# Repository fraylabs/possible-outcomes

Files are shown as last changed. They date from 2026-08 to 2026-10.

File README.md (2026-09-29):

# Fray Labs Outcomes

Public, reusable AI Outcomes and the recipes behind them, published by Fray Labs for [Possible](https://possible.sh).

Each folder contains:

- `outcome.md` — what was made and the original request;
- `prompt.md` — the recorded reusable execution prompt; and
- `outcome.json` — provenance, models, Products, Skills, requirements, file metadata, and an optional recipe.

A recipe collects the recorded agent, pinned skills, references, tools and ordered steps that help another agent reproduce or adapt the result. Unknown details are omitted. Fray-authored backfills explicitly label steps reconstructed from published prompts and artifacts; they are not transcripts of historical agent turns. Existing model provenance, prompts, result limitations and creator credits remain intact. Curated third-party demos retain their disclosed prompts without an invented workflow.

The root [`outcomes.json`](./outcomes.json) is the machine-readable publisher index. Possible reads this repository directly; the canonical source remains here.

## Use with Possible

Use CLI 0.5.0 or newer for manifests containing the optional `recipe` field. The older primary Product/Skill parsing issue in CLI 0.3.0 was fixed in 0.3.1; recipe support began in 0.4.0; explicit reconstructed-origin labels require 0.5.0.

```shell
npx https://github.com/fraylabs/possible/releases/download/v0.5.0/fraylabs-possible-0.5.0.tgz add fraylabs/possible-outcomes
npx https://github.com/fraylabs/possible/releases/download/v0.5.0/fraylabs-possible-0.5.0.tgz use fraylabs/possible-outcomes@digital-photo-frame
```

The `use` command provides the reusable instructions for an agent. Review the recipe, original prompt and stated limits before running it; access to referenced tools and services is still required.

## Opus 5.5 demos

[See ten creator demos and copy their prompts](OPUS-DEMOS.md): neon cities, mini golf, a cursor-following pet, a rocket launch, an interactive robot hand, fluid simulation, a Rube Goldberg machine, a sunset pirate ship, motion design and an explorable pagoda. Each links the original creator and records creator-reported model provenance.

## License

Fray-authored code and text are available under the MIT License. Curated creator prompts and demo media retain their original ownership and are excluded from that grant; see linked sources and each media/NOTICE.md. Referenced third-party Products and Skills retain their respective ownership and licenses.

CLI 0.5.0 is currently distributed through the verified GitHub release package used above. The npm registry remains on 0.3.1; use the release package for these optional recipes.

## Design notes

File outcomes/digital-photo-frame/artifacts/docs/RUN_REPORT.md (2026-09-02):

# Cleanroom and independent review report

## Outcome

The exact prompt was executed once in an empty workspace by an isolated Codex agent using Burr skill commit `3a1b8ebf17e178b28c6d65f67ad04fc97f009a55`, CAD skill commit `fc4f7069fb31c131a55f1ecd334b505f031f486b`, and KiStack commit `c5a25d1d0af7ae811666cab41d7952f41e310575`.

Prompt SHA-256: `394d94afe5622c2cc86f75955a4a430ee1d9883ff4be4308cc8aa4a50aa25dcd`.

No sibling experiment was visible and no parent-agent steering occurred after execution began. No purchase, fabrication, hardware power-up, publication, or external contact occurred during the run.

## Reproduced digital evidence

- Mechanical CAD: 9/9 final STEP targets passed topology, closure, and positive-volume validation.
- Product face: 216 × 138 mm.
- Nominal enclosure depth excluding stand: 29 mm.
- Burr motion: 61 rigid frames, eight instances, 1200 ms.
- KiCad ERC: exit 0, zero violations.
- KiCad DRC/parity: exit 5. The saved run recorded 742 DRC violations, zero unconnected items, and 295 schematic-parity issues.

The independent review reran ERC and reproduced exit 0. Three exact DRC reruns—including the cleanroom receipt—reproduced exit 5 and 295 parity issues; the DRC count varied between 740, 742, and 784 after zone refill. The stable conclusion is failure, not an exact deterministic violation count.

## Integration boundary

Because DRC/parity failed, the run correctly withheld populated PCB STEP, PCB renders, Gerbers, and drill files. The assembly retains an explicitly named `unverified_populated_component_envelope_4p5mm` rather than presenting a fabricated board model as authoritative.

Burr's integrated checks are also not passes:

- Deployed: `fail`, six findings across 28 checked pairs.
- Folded: `fail`, seven findings across 28 checked pairs.
- Exploded: `fail`, three findings across 28 checked pairs.
- All three carry an `open_component_mesh` incomplete reason.

## Trust boundary

Trusted: the exact prompt and provenance, editable CAD and KiCad sources, ERC-clean schematic, generated BOM/PDF, nine valid CAD outputs, relative Burr project, named fold motion, and preserved failed evidence.

Not trusted: PCB routing or fabrication readiness, populated-board integration, connector reach, power integrity, antenna performance, thermal or electrical safety, enclosure fit, stand strength, durability, or production readiness.

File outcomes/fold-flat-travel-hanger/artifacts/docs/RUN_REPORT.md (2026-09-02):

# Cleanroom and independent review report

## Outcome

The exact prompt was executed once in an empty workspace by an isolated Codex agent using Burr skill commit `3a1b8ebf17e178b28c6d65f67ad04fc97f009a55` and CAD skill commit `fc4f7069fb31c131a55f1ecd334b505f031f486b`.

Prompt SHA-256: `3c9f24162b60f47c980407762831950fe5c1894924433af9f205b289d80082fc`.

No earlier hanger geometry was provided, and no parent-agent steering occurred after execution began. No purchase, fabrication, physical use, publication, or external contact occurred during the run.

## Reproduced digital evidence

- CAD provider validation: 16/16 targets passed with zero failures.
- Deployed shoulder width: 442 mm.
- Folded envelope: 222.884518 × 88 × 30 mm.
- Hook pocket: 42 mm for a stated maximum 38 mm rod.
- Pin/bore clearance: 0.6 mm diametral.
- Positive-lock engagement: 6 mm per arm, with a nominal 36 mm² contact face per side.
- Release travel: 7.5 mm with 1 mm modeled blocking-face clearance.
- Exact exported STEP validation: all 55 component pairs passed in deployed, 25%, 50%, 75%, and folded poses.
- Burr motion: 61 rigid frames, 11 instances, 1600 ms.

The independent review reran the geometry validator from a separate temporary copy and reproduced `overall_pass: true` and all five zero-positive-volume-intersection results.

## Burr result

Burr's check is not a pass:

- Deployed: `fail`, four findings, 11 components, 55 checked pairs.
- Folded: `fail`, three findings, 11 components, 55 checked pairs.
- Both include `open_component_mesh` for seven tessellated components.

The exact BREP result and Burr's tessellated result use different representations. Both are retained; the BREP result does not override Burr's failed/incomplete outcome.

## Trust boundary

Trusted: editable source, exported CAD, stated dimensions, exact five-pose geometry result, named Burr motion, and the preserved evidence files.

Not trusted: physical load rating, stiffness, fatigue, creep, spring selection, retention force, dimensional accuracy after printing, user safety, or production readiness.

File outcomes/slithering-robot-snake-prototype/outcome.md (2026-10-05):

# Slithering Robot Snake Prototype

A ten-link robot snake, about 0.95 m long, with nine yaw joints: a CAD assembly, robot description files, and a MuJoCo simulation where it slithers with lateral undulation, notices an obstacle with a range sensor, detours around it without touching it, and rejoins its route. Twelve tests check the geometry, joints, gait and clearance.

## How it was made

An AI agent made this. Codex built it in one recorded session, starting from the `$possible` skill: it asked what to build, how it should behave, where, and what result was wanted, then prepared a build pack. The answers in this recipe came from a scripted test run, not typed live. The agent used the text-to-cad and robotics skills listed below, MuJoCo for simulation and pytest for checks. Possible captured the session with `possible capture`; tool outputs and file contents are left out.

## What to know

This is a digital prototype. Propulsion in the simulation uses a surrogate, so real-world slithering, servo choice, friction, strength and manufacturability are unproven. The video and renders were regenerated from the session's own files after the originals were lost; link count, joints, tests and simulated distances match the session's report.

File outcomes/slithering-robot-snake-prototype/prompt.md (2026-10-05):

$possible

I want to make a robot snake.

I want it to slither convincingly and navigate around obstacles on its own.

A smooth indoor floor.

Continue from my previous answer.

I am starting from scratch. I only have the idea.

A convincing digital prototype I can inspect and simulate now, with a clear path toward fabricating it later.

Yes, proceed with this pack.

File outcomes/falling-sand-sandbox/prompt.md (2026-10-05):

Build a falling-sand sandbox game as a single self-contained index.html: no libraries, no build step, it should just open in a browser. Elements: sand, water, stone, wood, plant, fire, smoke, and an eraser. Sand piles up and slides off slopes, water flows sideways and levels out, fire burns wood and plants and gives off smoke that rises and fades, and plants slowly grow into adjacent water. Paint with mouse or touch, with an element palette along the bottom and a brush-size slider. Simulate on a fixed grid of about 240x160 cells, render it to a canvas through ImageData, and scale it up with crisp pixels. Keep it smooth at 60fps. Give every element a little per-cell colour variation so it looks textured. Add Pause, Clear, and a Seed button that drops a small demo scene.

Works nicely. Two changes: add lava, which flows slowly, sets wood and plants on fire, turns water it touches into steam (a new gas that rises and condenses back into water near the top) and cools into stone where it meets water. And alternate the horizontal scan direction every frame so sand piles and water don't drift to one side.

Now make the Seed scene look good as a screenshot: a stone basin of water with plants growing in it, a wooden tree on a stone ledge, a stream of sand pouring from the top, and lava dripping from one corner onto the ledge so the tree slowly catches fire. Load that scene automatically on first open.

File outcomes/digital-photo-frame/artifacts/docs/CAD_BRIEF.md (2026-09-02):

# CAD brief

## Goal and scope

Create a landscape tabletop enclosure for a documented seven-inch display, a
compact controller PCB envelope, a reusable-fastener rear cover, and a folding
easel stand. The authoritative editable source is
`models/cad/source/photo_frame_parts.py`; STEP and STL files are generated
artifacts. The detailed PCB is not represented as validated populated geometry
because the KiCad PCB failed DRC and parity, so the assembly intentionally uses
a named conservative PCB envelope and is incomplete.

## Units and coordinates

- Units: millimetres and degrees.
- Origin: centre of the front product face.
- +X: landscape right; +Y: product up; +Z: toward the rear.
- Front exterior plane: Z=0.
- Rear-cover exterior plane: Z=29.
- Stand hinge axis: X direction through Y=35, Z=29.

## Objects and configuration

- `front_bezel`: 216 x 138 mm rounded outer form, 4 mm face, display-frame
  ledge and an unobstructed 158.08 x 89.92 mm window around the active area.
- `rear_chassis`: 216 x 138 mm, rear envelope ending at Z=29, service-cover
  insert bosses, PCB standoffs/ribs, connector openings, hinge blocks and hard
  stops.
- `service_cover`: 208 x 130 x 2 mm; four M3 clearances, controller/power vents,
  three button holes, ambient-sensor hole, and rear status-light opening.
- `folding_stand`: 140 x 105 x 4 mm plate with hinge barrel, folded detents, and
  stop tabs; deployed source angle -18 degrees and folded angle 0 degrees.
- `display_envelope`: EastRising ER-TFTM070-4V3 documented 180 x 100 x 12.8 mm
  maximum envelope plus 154.08 x 85.92 mm active-area plate.
- `pcb_unverified_envelope`: 112 x 70 x 1.6 mm board plus 4.5 mm conservative
  top-side component envelope. This is explicitly not a populated-PCB STEP.
- Product outputs: deployed, folded, and rear-cover-open exploded arrangements
  built from unchanged rigid component functions.

## Constraints and assumptions

- Outer front envelope must remain <=230 x 165 mm. Actual: 216 x 138 mm.
- Enclosure excluding stand must remain approximately 22-30 mm deep. Nominal
  exterior planes span 29 mm; the hinge/stop source is constrained to Z<=29.
- Display ledge locates the module by its outer frame, not active glass.
- Four product PCB standoff centres are (-10,-31), (94,-31), (-10,31),
  (94,31), mapped from KiCad holes (24,24), (128,24), (24,86), (128,86).
- Side openings share the KiCad connector Y coordinates; final X insertion and
  shell engagement require the missing validated populated-PCB STEP.
- No underside PCB components are allowed in the current integration envelope.
- Prototype parts require a build volume of at least 220 x 140 x 30 mm when
  oriented flat; this is an envelope statement, not a printability proof.

## Validation contract

All nine final STEP files were run through CAD `inspect refs --facts --planes
--positioning` and `inspect validate`; every final validation reported
`failureCount: 0`. Every primary STEP has at least one saved snapshot. These
checks prove closed positive-volume source geometry, but do not supersede
Burr's failed tessellated interference check or prove manufactured fit.

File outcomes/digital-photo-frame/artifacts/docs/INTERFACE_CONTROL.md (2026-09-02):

# Shared mechanical/electrical interface control

Status: digital pre-build, incomplete. KiCad and CAD remain independent
authorities. Only exported geometry is copied into `models/assembly/exports`.

## Product and display

| Interface | Controlled value |
|---|---|
| Product axes | Origin at front-face centre; +X right, +Y up, +Z rear |
| Product front envelope | 216 x 138 mm |
| Nominal enclosure rear | Z=29 mm |
| Display MPN/configuration | ER-TFTM070-4V3, 5 V, 8-bit 8080, no touch |
| Display outer/max envelope | 180 x 100 x 12.8 mm |
| Display active area | 154.08 x 85.92 mm, centred on product origin |
| Display front/back | Z=4.5 to 17.3 mm; active-area plate is immediately forward |
| Display mounting holes | Four 3.2 mm holes on 174 x 98 mm centres per selected module documentation; not modelled as product fasteners in this first result |
| Display connection | J2, 2x20 2.54 mm vertical pin header on controller PCB |
| Touch | No-touch configuration; pins 33-38 intentionally unconnected |

The CAD ledge clears the 180 x 100 mm display frame by 0.6 mm total in X and Y
and leaves a 2 mm perimeter allowance around the active area. A replaceable
0.5-1.0 mm compliant gasket is required between the ledge/clamp system and
module frame during physical build; no load may be applied to active glass.

## PCB mapping

| Interface | KiCad coordinates | Product coordinates |
|---|---:|---:|
| Board outline | X=20..132, Y=20..90 | X=-14..98, Y=-35..35 |
| Board centre | (76,55) | (42,0) |
| Mount 1 | (24,24) | (-10,-31) |
| Mount 2 | (128,24) | (94,-31) |
| Mount 3 | (24,86) | (-10,31) |
| Mount 4 | (128,86) | (94,31) |
| Board thickness | 1.6 mm | Z=18.5..20.1 |
| Modelled top envelope | 4.5 mm above board | Z=20.1..24.6 |
| Allowed bottom components | None in this revision | Board-to-display gap is 1.2 mm |

Coordinate transform: `product_x = kicad_x - 34`, `product_y = kicad_y - 55`.
The standoff centres exactly use this mapping in the CAD source. Edge clearance
to the inner cavity is at least 5 mm at the right board edge and 29 mm at the Y
edges. Top-envelope clearance to the service-cover underside at Z=27 is 2.4 mm.
The 1.2 mm board-bottom gap is an explicit local exception valid only because
the current PCB places no bottom-side components; solder protrusion and assembly
tolerance remain a physical bring-up check.

## External and service interfaces

| Item | KiCad anchor | Product opening/axis | Status |
|---|---:|---:|---|
| USB-C J1 | (130,32), rotated 90 deg | right wall, Y=-23 | Y aligned; exact shell protrusion unverified without populated PCB STEP |
| microSD J3 | (126,70), rotated 90 deg | right wall, Y=15 | Y aligned; insertion reach unverified without populated PCB STEP |
| Previous SW1 | (86,74) | (52,19) | coordinate-aligned |
| Next SW2 | (96,74) | (62,19) | coordinate-aligned |
| Menu/wake SW3 | (106,74) | (72,19) | coordinate-aligned |
| Ambient sensor U3 | (63,80) | (29,25) | coordinate-aligned |
| Status LED LED1 | (75,76) | (41,21) | coordinate-aligned after source repair |
| Debug J4 | (39,74) | internal, (5,19) | rear cover removal required; not externally exposed |

Keep at least 12 mm unobstructed outside the USB-C opening for plug overmould
and bend, and at least 20 mm outside the microSD slot for finger/card insertion.
The display module uses a rigid pin-header connection in the selected
configuration; there is no FPC bend region. Maintain a 6 mm insertion corridor
above and around J2 until exact mating hardware is validated.

## Stand and service envelope

- Hinge: X-axis, Y=35, Z=29.
- Deployed pose: -18 degrees from folded/rear plane.
- Folded pose: 0 degrees, stand plate substantially flush; final folded product
  bounds are approximately 216 x 139 x 35.2 mm including the stand barrel.
- Deployed product bounds are approximately 216 x 138 x 67.34 mm.
- Retention: spherical folded detents and two deployed stop tabs are modelled;
  retention force and cycle life are not verified.
- Service cover: four M3 reusable fasteners into heat-set inserts; display, PCB,
  controls and cover are intended to be replaceable after cover removal.

## Known failed interfaces

Burr reports positive-volume overlaps between enclosure pieces, display and PCB
envelope, and open component meshes. The deployed integrated assembly has six
reported interfering pairs, folded has seven, and exploded has three. Therefore
no-fit/no-interference claim is made. USB-C/microSD X alignment, all connector
insertion volumes, and mechanical clearances to real populated components remain
unverified because DRC prevented populated PCB STEP export.

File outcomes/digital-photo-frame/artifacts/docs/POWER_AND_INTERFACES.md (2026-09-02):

# Power budget and electrical interfaces

Status: design estimate only; not measured on hardware.

## Input and rails

J1 is a GCT USB4105-GF-A USB-C receptacle used as a power-only sink. R1 and R2
are independent 5.1 kohm Rd resistors from CC1 and CC2 to ground. USB data and
SBU pins are intentionally unconnected. U4 (USBLC6-2SC6) protects CC1/CC2 and
uses VBUS as its reference. VBUS passes through F1, a Bourns MF-MSMF200-2
2.0 A resettable protector, to +5V; D1 is an SMAJ5.0A shunt TVS on protected
+5V. This architecture requires a certified regulated 5 V USB-C supply that
advertises sufficient Type-C current; it has no USB PD negotiation.

U2 is TPS62132RGTR, fixed 3.3 V, rated 3 A. It uses a 1.0 uH Coilcraft
XAL4020-102MEC, 10 uF input, two 22 uF output capacitors, 10 nF soft-start, and
the datasheet's fixed-output pin treatment. Exact loop layout is not accepted:
the PCB currently fails DRC.

## Pre-build current budget

| Load | Rail | Budgeted current | Basis |
|---|---:|---:|---|
| ER-TFTM070-4V3 module including backlight | 5 V | 0.480 A max | module datasheet maximum |
| ESP32-S3 module/Wi-Fi peaks | 3.3 V | 0.550 A | conservative bring-up allowance; must be measured |
| microSD write/transient | 3.3 V | 0.200 A | design allowance; card-dependent |
| Ambient sensor, LED, pull networks, margin | 3.3 V | 0.020 A | design allowance |
| 3.3 V total | 3.3 V | 0.770 A | below converter rating |
| 3.3 V input equivalent at 90% efficiency | 5 V | 0.565 A | calculated |
| Combined nominal maximum estimate | 5 V | 1.045 A | display plus converter input |
| Recommended adapter | 5 V | >=2.0 A | transient/thermal headroom |

TPS62132 output loading is approximately 26% of its 3 A rating under this
budget. The input protector is not a precision current limiter, and temperature
derating of the PTC must be checked. Display inrush, Wi-Fi bursts, storage
writes, converter temperature, rail droop and EMI require bench measurement.

## Display interface

J2 implements the documented 40-pin ER-TFTM070-4V3 interface in 8-bit 8080,
5 V, no-touch configuration:

- 1 GND; 2 VDD5V; 3 /CS; 4 D/C; 5 /RD; 6 /WR; 7 RESET; 8 TE.
- 9-16 are DB0-DB7 and connect to ESP32-S3 GPIO35-GPIO42.
- 17-32 (DB8-DB23) are intentionally no-connect for the selected 8-bit mode.
- 33-38 are touch-related pins and are intentionally no-connect for no-touch.
- 39 BL_ON/OFF/PWM is driven by GPIO11 (`LCD_BL`); 40 is NC.

The module's integrated SSD1963 controller and backlight circuitry are the
reason it was selected. The logic-level compatibility and reset/backlight
polarity still require physical confirmation on the exact ordered
configuration; the saved public datasheet could not be downloaded directly in
this environment, although the official URL is recorded.

## Storage, sensing and debug

The Molex 104031-0811 microSD socket is wired in SPI mode with card detect.
LTR-303ALS-01 uses I2C with 4.7 kohm pull-ups, 100 nF local decoupling and an
interrupt line. Three KMR221GLFS buttons pull GPIO inputs to ground with 10 kohm
pull-ups. Reset and boot buttons are separately accessible after rear-cover
removal. J4 exposes 3V3, GND, native USB D+/D-, U0TXD and U0RXD. Test points
cover +5V, +3V3, GND, LCD_WR, LCD_BL and SD_CS.

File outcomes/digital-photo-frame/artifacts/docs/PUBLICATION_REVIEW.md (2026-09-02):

# Publication review

This receipt records findings made after the one-shot cleanroom run. The generated archive, CAD, KiCad files, source, prompt, and original run report remain unchanged so the published pack is evidence of the actual run rather than a parent-edited redesign.

## Reproducibility

- Burr package: `@fraylabs/burr` version `0.31.0`, skill commit `3a1b8ebf17e178b28c6d65f67ad04fc97f009a55`, source: <https://github.com/fraylabs/burr/tree/3a1b8ebf17e178b28c6d65f67ad04fc97f009a55/skills/burr>.
- CAD skill commit: `fc4f7069fb31c131a55f1ecd334b505f031f486b`, source: <https://github.com/earthtojake/text-to-cad/tree/fc4f7069fb31c131a55f1ecd334b505f031f486b/skills/cad>.
- KiStack skill commit: `c5a25d1d0af7ae811666cab41d7952f41e310575`, source: <https://github.com/American-Embedded/kistack/tree/c5a25d1d0af7ae811666cab41d7952f41e310575/skills>.
- Archive CAD source: `models/cad/source/photo_frame_parts.py`.
- Archive electronics source: `tools/generate_electronics.py`.
- Archive mechanical endpoints: `models/assembly/exports/product_stand_deployed.step`, `models/assembly/exports/product_stand_folded.step`, and `models/assembly/exports/product_rear_cover_open_exploded.step`.
- Archive KiCad authority: `models/kicad/source/photo_frame.kicad_pro`, `.kicad_sch`, and `.kicad_pcb`.
- Reviewed snapshots: `media/xray.png`, `media/deployed.png`, `media/exploded.png`, `media/schematic.png`, and `media/burr-checks.png`.

Paths beginning with `models/` or `tools/` are valid relative to the extracted archive root. Paths beginning with `artifacts/` or `media/` are valid relative to this outcome pack.

## Confirmed source blockers

1. The stand barrel is a solid cylinder: it has no clearance bore for the specified 5 mm hinge pin. Its local barrel centre is also 2 mm behind the hinge datum before placement. The documented hinge assembly cannot be completed from this geometry.
2. The interface control gives a 180 × 100 mm display envelope and four 3.2 mm holes on 174 × 98 mm centres. The vertical pattern plus hole diameters spans 101.2 mm, so those stated values are mutually incompatible. The exact selected-module drawing must resolve the interface before CAD placement.
3. The USB-C input has fixed 5.1 kΩ sink resistors but no detection or load limiting for the source-advertised Type-C current. The estimated 1.045 A load can exceed a source advertising default current; the 2 A resettable protector is not a precision current-control mechanism.
4. The KiCad project ignores or downgrades footprint/symbol identity mismatches, and the generator has no equivalent fail-closed schematic-to-PCB footprint comparison. The already failed parity result must be repaired and independently blocked before fabrication.
5. The electronics generator hard-codes one macOS KiCad 10.0.6 installation and a host-specific Python package path. The checked-in KiCad files are inspectable, but regeneration is not portable as generated.

The schematic date `2026-09-03` is not a future-dated receipt: the run and publication used Singapore time (UTC+08:00), as recorded by the outcome's `authoredAt` value.

These are repair blockers, not physical validation results. A future design pass must repair the sources, regenerate all affected CAD/KiCad artifacts, rerun ERC, DRC/parity, exact CAD validation and Burr checks, and then perform the specified physical bring-up. Until then, this pack remains incomplete and repair-required.

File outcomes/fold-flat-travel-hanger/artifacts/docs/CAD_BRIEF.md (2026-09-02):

# CAD brief

- Model: symmetric fold-flat travel clothes hanger; five printed parts plus purchased shoulder screws, locknuts and compression springs.
- Task type: new fit-critical mechanical assembly with five static fold poses, exploded assembly and lock details.
- Units and axes: millimetres; X shoulder width, Y front/back thickness, Z vertical.
- Deployed target: 430–450 mm shoulder width; modeled nominal 442 mm.
- Folded target: at most approximately 230 × 90 × 30 mm.
- Load path: each thick shoulder beam has an 8 × 6 mm heel bearing on a rigid dual-ear lock bar. The bar presents 6 mm positive blocking engagement per side; it is spring-biased engaged and moves 7.5 mm axially under deliberate thumb action.
- Hook: 42 mm circular rod pocket, 40 mm modeled throat, folding on a captured M5 shoulder screw in a front-layer clevis.
- Parts: `center_yoke`, `left_shoulder_arm`, `right_shoulder_arm`, `folding_hook`, `dual_positive_lock_bar`.
- Purchased hardware: two M5 arm shoulder screws, one shorter M5 hook shoulder screw, three low-profile prevailing-torque locknuts, two small compression springs.
- Clearances: 5.0 mm pin in 5.6 mm bore (0.30 mm radial); arm axial clearance 1.0 mm each side; hook axial clearance 0.5 mm each side; released lock clearance 1.0 mm.
- Joints/datums: named left/right arm revolute axes, hook revolute axis and lock linear-release axis in `models/hanger_common.py`.
- Finger protection: both arm roots remain between 4 mm cheek plates; the thumb pad is recessed in an 8 mm-high guide slot; final arm movement occurs behind the cheek faces.
- Strap notches: shallow 9 mm-diameter transverse top grooves near both tips, leaving more than 12 mm of local beam depth.
- Manufacturing assumption: FDM PETG/PA-class prototype with layer direction selected to keep shoulder bending in the XY layer plane; rounded long edges are modeled where OCC permits. This is not a material or strength validation.
- Authoritative paths: `models/hanger_common.py`, individual `models/parts/*.step.py`, and pose `models/assemblies/*.step.py` generators.
- Validation targets: closed positive-volume occurrences; part build-area envelopes; deployed/folded envelopes; hook pocket/throat; pin and axial clearances; blocking-face engagement/contact; release clearance; component identity; pairwise positive-volume intersection for five poses; Burr motion and Burr interference outcomes.

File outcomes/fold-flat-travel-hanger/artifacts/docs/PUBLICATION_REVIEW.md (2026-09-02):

# Publication review

This receipt records findings made after the one-shot cleanroom run. The generated archive, CAD, source, prompt, and original run report remain unchanged so the published pack is evidence of the actual run rather than a parent-edited redesign.

## Reproducibility

- Burr package: `@fraylabs/burr` version `0.31.0`, skill commit `3a1b8ebf17e178b28c6d65f67ad04fc97f009a55`, source: <https://github.com/fraylabs/burr/tree/3a1b8ebf17e178b28c6d65f67ad04fc97f009a55/skills/burr>.
- CAD skill commit: `fc4f7069fb31c131a55f1ecd334b505f031f486b`, source: <https://github.com/earthtojake/text-to-cad/tree/fc4f7069fb31c131a55f1ecd334b505f031f486b/skills/cad>.
- Archive source: `models/hanger_common.py`.
- Archive model endpoints: `models/assemblies/hanger_deployed.step` and `models/assemblies/hanger_folded.step`.
- Published source mirror: `artifacts/source/hanger_common.py`.
- Reviewed snapshots: `media/deployed.png`, `media/folded.png`, `media/lock-engaged.png`, `media/lock-released.png`, `media/burr-folded.png`, and `media/burr-checks-deployed.png`.

Paths beginning with `models/` are valid relative to the extracted archive root. Paths beginning with `artifacts/` or `media/` are valid relative to this outcome pack.

## Confirmed source defect

`make_lock_bar()` combines the transverse bar and thumb pad but does not create the two guide pegs named by `docs/ASSEMBLY.md`. The documented compression springs therefore have no modeled pegs, and the spring-loaded return/folded-retention assembly cannot be reproduced from the generated geometry.

This is a repair blocker, not a physical validation result. A future design pass must add compatible guide and spring geometry, regenerate every pose and export, rerun exact geometry checks and Burr checks, and physically verify release and retention forces. Until then, this pack remains repair-required.

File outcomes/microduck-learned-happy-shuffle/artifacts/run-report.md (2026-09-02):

# Happy Shuffle run report

## Outcome

`Mjlab-HappyShuffle-Flat-MicroDuck` is implemented as a registered reinforcement-learning task and trained with PPO in the official `pollen-robotics/microduck_rl` stack. The final checkpoint produces a stable, rhythmic, alternating step-and-sway motion in the supported simulator playback path. A close front-view rollout shows two consecutive eight-second phrases; it is recognizably a compact shuffle rather than random twitching or a scripted joint trajectory.

This result is **verified in simulation, not on physical hardware**. The dance reads clearly in motion, but “happy” is subjective and the step size is intentionally modest. The second phrase is stable but not action-identical to the first (`phrase_repeat_action_rmse = 0.446`), so perfect loop identity is not proven.

## What changed

- Registered `Mjlab-HappyShuffle-Flat-MicroDuck` in the live task registry and documented it in `README.md`.
- Added an eight-second four-count phase command: left-out, right-close, right-out, left-close.
- Added state-based rewards for alternating contacts, body-relative lateral foot motion, lateral body rhythm, and a curriculum-gated gentle head sway. No target joint trajectory or animation is present.
- Added fall/NaN termination plus costs for unintended travel/yaw, slip, self-collision, feet tilt, joint-limit proximity, action over-limit, torque, leg speed, neck thrash, and action changes.
- Preserved the 61-dimensional actor observation contract, BAM actuators, observation noise/delay, domain randomization, and modest training pushes inherited from the production walking task.
- Added a finite supported-path checkpoint evaluator with nominal video and a 32-environment randomized perturbation battery.
- Fixed the Hugging Face training bootstrap's pre-existing one-level checkpoint lookup so the final trained checkpoint is exported through `scripts/export.py` to normalized ONNX.

## Local verification

All local work ran on CPU/configuration paths; no meaningful Mac GPU training was attempted.

| Check | Result |
|---|---|
| `uv run list-envs` | Lists `Mjlab-HappyShuffle-Flat-MicroDuck` |
| `uv run --with pytest pytest -q tests/test_happy_shuffle_cfg.py` | 6 passed |
| `uv run --with pytest pytest -q tests/` | 172 passed, 1 skipped |
| `uvx ruff check` on the new evaluator, task config, and focused tests | Passed |
| `git diff --check` | Passed |

Focused tests cover the eight-second phase/seam, four-count alternation, 61D observation layout, anti-hacking reward signs and guards, inherited robustness configuration, and distinct PPO run configuration.

## Training and checkpoint

- Private model repository: <https://huggingface.co/cowbelleh/happy-shuffle-train-20260902>
- Final checkpoint: `happy_shuffle/2026-09-01_17-15-19_happy_shuffle/model_3499.pt`
- Supported export: `exported/policy.onnx`
- Serious run: 4,096 environments, 3,500 PPO iterations, A10G Small, completed successfully.
- Final training mean reward: `172.35`; mean episode length: `800/800` steps (16 seconds).
- Final weighted task terms: contacts `2.2791`, lateral step `1.6563`, body rhythm `2.7295`, head sway `0.9705`.
- Final safety signals: `nan_state = 0`; fall term `0.0417`; slip velocity metric `0.0146`; every logged penalty remained non-positive.

## Final evaluation

Checkpoint `model_3499.pt` was loaded by RSL-RL's inference policy in the registered environment. The nominal battery recorded one robot for 800 steps (two phrases). The perturbation battery ran 32 environments for 800 steps with training-time domain randomization and pushes. All `done` events occurred at the expected final 16-second timeout; there were no early terminations.

| Metric | Nominal | Perturbed (32 envs) |
|---|---:|---:|
| Upright within 30 degrees | 1.000 | 1.000 |
| Early terminations | 0 | 0 |
| Contact-sequence score | 0.7634 | 0.7594 |
| Lateral-step score | 0.3637 | 0.3537 |
| Body-rhythm score | 0.9076 | 0.9072 |
| Mean stance-foot slip | 0.0103 m/s | 0.00947 m/s |
| Self-collision fraction | 0.000 | 0.000 |
| Maximum episode-relative travel | 0.0622 m | 0.0572 m |
| Maximum heading drift | 0.435 rad | 0.448 rad |
| Maximum absolute joint speed | 4.665 rad/s | 4.849 rad/s |
| Mean action delta L2 | 0.0638 | 0.0613 |
| Mean reward per step | 0.2112 | 0.2103 |

Artifacts in this working directory:

- `artifacts/happy_shuffle/happy-shuffle-preview.mp4` — 16 seconds, 640x640, 50 fps, two phrases.
- `artifacts/happy_shuffle/happy-shuffle-one-phrase.gif` — shareable eight-second preview.
- `artifacts/happy_shuffle/metrics.json` — final nominal and perturbed metrics.
- `artifacts/happy_shuffle/frames/final-contact-sheet.png` — 0.5-second visual samples used for inspection.

Artifact checksums:

- MP4: `c359335be695e085c3b8a454de94670130578705ebe62bfb3c9042c8bf66d8d9`
- GIF: `91e255cc0ed1fb57e5c6953d524f4b2243d9e16e9df795fb54d9d3f870fa20ea`
- metrics JSON: `e9be5221bef3352c99536bf16e3596bb1408c2d4518a6fdbffbc8c953bf8109a`

The same final evaluation is preserved privately under `evaluation-final/` in the model repository.

## Hugging Face Jobs and spend

The requested L4 smoke remained queued for about 47 minutes and was canceled and verified canceled before the explicitly authorized A10G fallback. It never started and has zero measured runtime.

| Purpose | Job | Status | Runtime | Derived cost |
|---|---|---:|---:|---:|
| L4 smoke, canceled before allocation | [6a96fadf21c5aa7c8364bdd2](https://huggingface.co/jobs/cowbelleh/6a96fadf21c5aa7c8364bdd2) | CANCELED | 0 s | $0.0000 |
| A10G 64-env/5-iteration smoke | [6a97060b0718b0f6d890d682](https://huggingface.co/jobs/cowbelleh/6a97060b0718b0f6d890d682) | COMPLETED | 191.638 s | $0.0532 |
| A10G serious 4,096-env/3,500-iteration run | [6a97077a0718b0f6d890d6cb](https://huggingface.co/jobs/cowbelleh/6a97077a0718b0f6d890d6cb) | COMPLETED | 8,922.121 s | $2.4784 |
| Initial eval, missing EGL selection | [6a972c0621c5aa7c8364c3c7](https://huggingface.co/jobs/cowbelleh/6a972c0621c5aa7c8364c3c7) | ERROR | 188.710 s | $0.0524 |
| Distant-camera eval | [6a972cf80718b0f6d890de6a](https://huggingface.co/jobs/cowbelleh/6a972cf80718b0f6d890de6a) | COMPLETED | 251.862 s | $0.0700 |
| Close-view eval, score-probe config bug | [6a972f160718b0f6d890def4](https://huggingface.co/jobs/cowbelleh/6a972f160718b0f6d890def4) | ERROR | 195.688 s | $0.0544 |
| Correct close-view eval | [6a9730880718b0f6d890df2a](https://huggingface.co/jobs/cowbelleh/6a9730880718b0f6d890df2a) | COMPLETED | 261.156 s | $0.0725 |
| Final episode-relative metric confirmation | [6a97329d0718b0f6d890df98](https://huggingface.co/jobs/cowbelleh/6a97329d0718b0f6d890df98) | COMPLETED | 269.929 s | $0.0750 |

**Total derived compute cost: USD $2.8559**, below the authorized $5.00 cap.

Hugging Face's job-inspection response did not expose an actual billed-dollar field. Costs above are therefore explicitly derived from recorded `startedAt`/`finishedAt` timestamps and the live Jobs hardware price returned by the API for A10G Small (`$0.016667/minute`). Queuing time is excluded. No other paid service was used.

## Failed attempts and remaining uncertainty

- Two evaluator attempts failed before rollout due to harness defects (headless EGL selection, then unresolved scene-site configuration). Both were diagnosed without changing the trained policy, fixed, and followed by successful final evaluations.
- The behavior is proven only in MuJoCo Warp simulation. Sim-to-real transfer, hardware thermal/current behavior, and physical floor grip are not tested here.
- The randomized battery covers the repository's domain randomization and modest velocity pushes for 16 seconds. It does not prove recovery from arbitrary large disturbances or long-horizon drift.
- The two phrases are visually coherent and remain stable, but action-space phrase-repeat RMSE is `0.446`; exact trajectory identity at the seam is not proven.
- “Joyful” is a human visual judgment. The close-view evidence shows a compact alternating foot shuffle, synchronized body sway/crouch, and gentle head motion; it is not an exaggerated dance.

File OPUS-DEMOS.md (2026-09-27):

# Opus 5.5: see the result, copy the prompt

Ten creator demos with the prompts they disclosed. Model attribution is creator-reported; these are not independent Possible model tests.

## [Rainy Neon Cyberpunk City](outcomes/neon-cyberpunk-city/outcome.md)

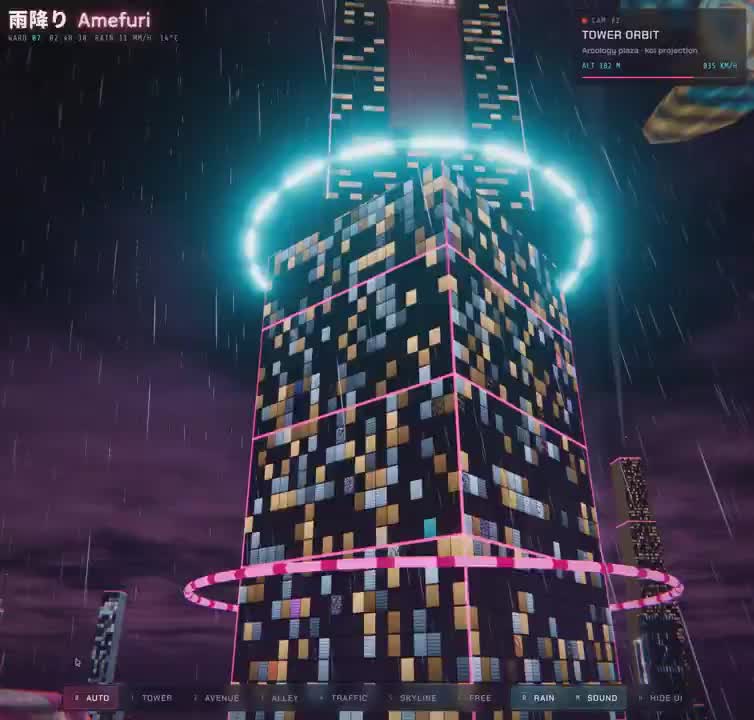
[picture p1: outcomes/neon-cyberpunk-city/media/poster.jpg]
Rainy Neon Cyberpunk City (https://x.com/0xPD33/status/2102454871899443432)


[Copy the prompt](outcomes/neon-cyberpunk-city/prompt.md) · [Preview excerpt](outcomes/neon-cyberpunk-city/media/preview.mp4) · [Full creator demo](https://x.com/0xPD33/status/2102454871899443432)

## [One-File Mini Golf](outcomes/one-file-mini-golf/outcome.md)

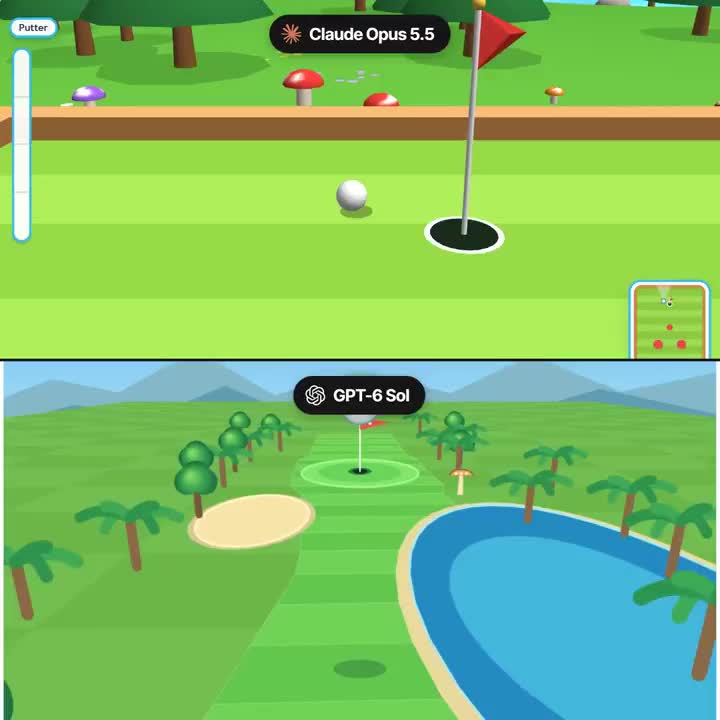
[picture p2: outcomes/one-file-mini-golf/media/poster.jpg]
One-File Mini Golf (https://x.com/hunterjreid/status/2102718456026325132)


[Copy the prompt](outcomes/one-file-mini-golf/prompt.md) · [Preview excerpt](outcomes/one-file-mini-golf/media/preview.mp4) · [Full creator demo](https://x.com/hunterjreid/status/2102718456026325132)

## [Feed a Cursor-Following Monster](outcomes/cursor-monster-pet/outcome.md)

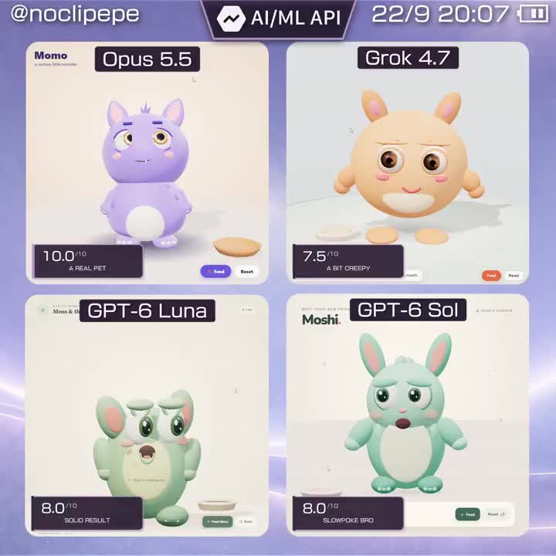
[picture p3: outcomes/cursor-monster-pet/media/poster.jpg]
Feed a Cursor-Following Monster (https://x.com/noclipepe/status/2102673625060966830)


[Copy the prompt](outcomes/cursor-monster-pet/prompt.md) · [Preview excerpt](outcomes/cursor-monster-pet/media/preview.mp4) · [Full creator demo](https://x.com/noclipepe/status/2102673625060966830)

## [3D Rocket Launch](outcomes/three-dimensional-rocket-launch/outcome.md)

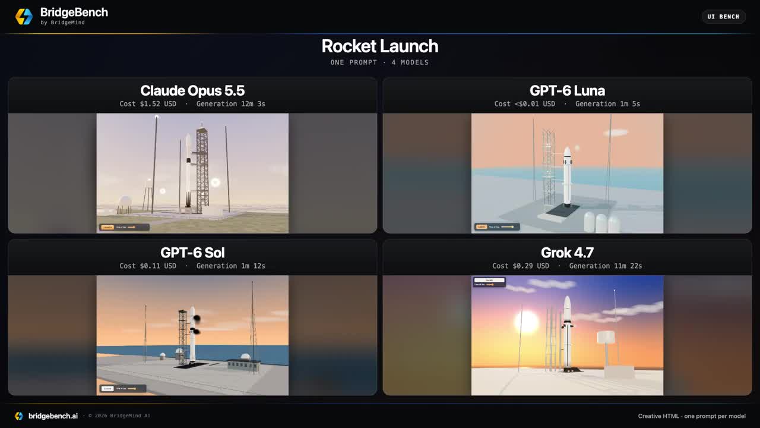
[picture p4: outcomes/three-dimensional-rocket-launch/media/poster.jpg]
3D Rocket Launch (https://x.com/bridgebench/status/2102476831031017581)


[Copy the prompt](outcomes/three-dimensional-rocket-launch/prompt.md) · [Preview excerpt](outcomes/three-dimensional-rocket-launch/media/preview.mp4) · [Full creator demo](https://x.com/bridgebench/status/2102476831031017581)

## [Inside a Robot Hand](outcomes/inside-robot-hand/outcome.md)

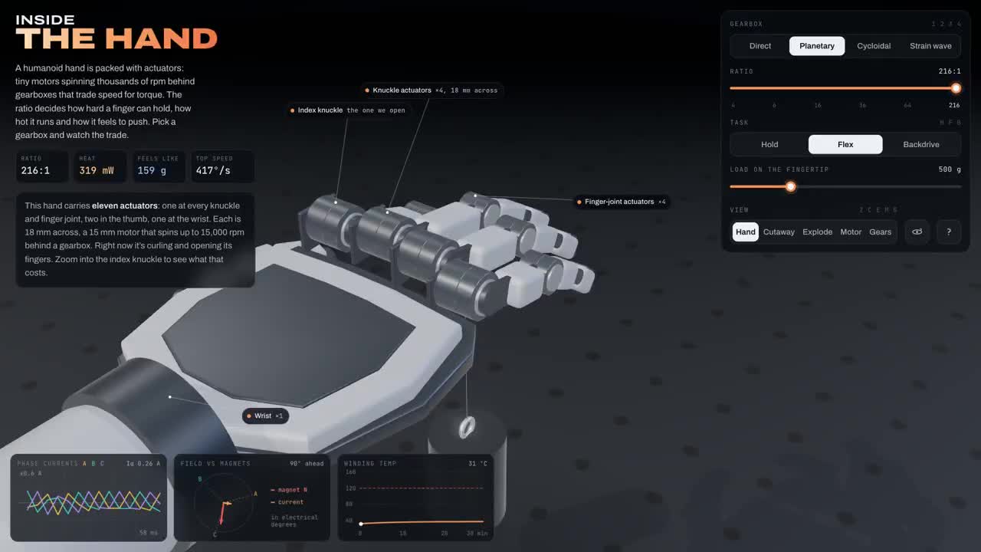
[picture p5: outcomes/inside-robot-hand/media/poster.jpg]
Inside a Robot Hand (https://x.com/thermalpastor/status/2102928996900200562)


[Copy the prompt](outcomes/inside-robot-hand/prompt.md) · [Preview excerpt](outcomes/inside-robot-hand/media/preview.mp4) · [Full creator demo](https://x.com/thermalpastor/status/2102928996900200562)

## [Neon Fluid Playground](outcomes/neon-fluid-simulation/outcome.md)

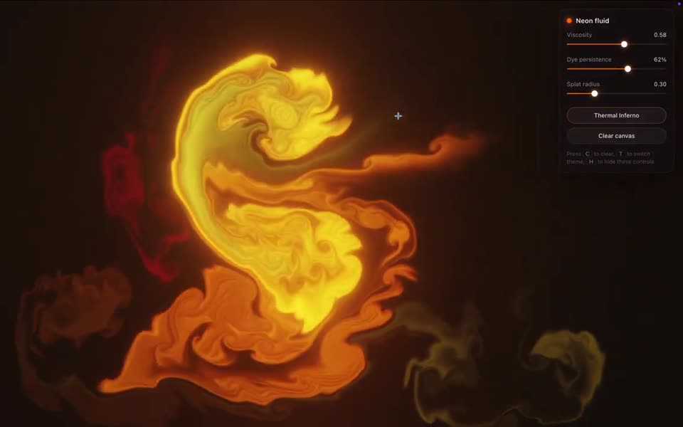
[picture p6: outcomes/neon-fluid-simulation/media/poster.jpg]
Neon Fluid Playground (https://x.com/theailoser/status/2102565611473661963)


[Copy the prompt](outcomes/neon-fluid-simulation/prompt.md) · [Watch demo](outcomes/neon-fluid-simulation/media/demo.mp4) · [Original creator post](https://x.com/theailoser/status/2102565611473661963)

## [Self-Running Rube Goldberg Machine](outcomes/rube-goldberg-machine/outcome.md)

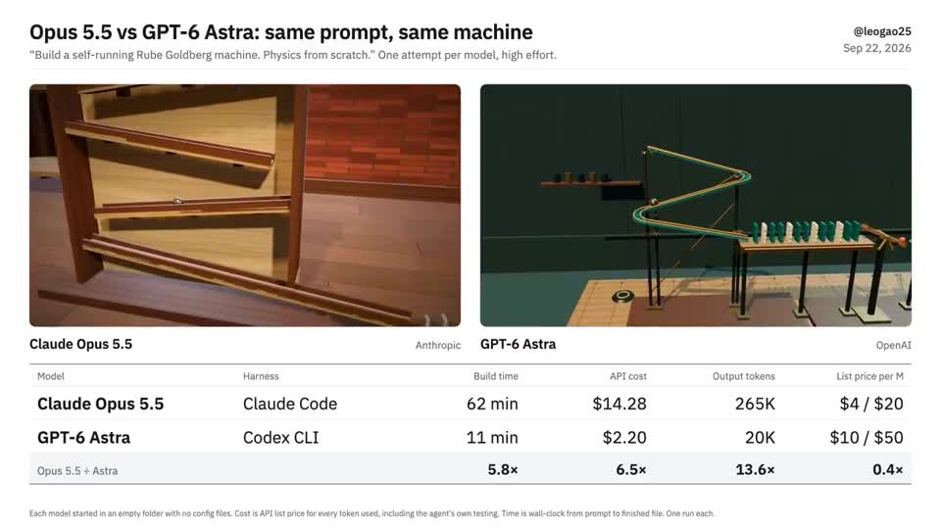
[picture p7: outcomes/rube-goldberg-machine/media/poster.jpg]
Self-Running Rube Goldberg Machine (https://x.com/leogao25/status/2102544078927741369)


[Copy the prompt](outcomes/rube-goldberg-machine/prompt.md) · [Watch demo](outcomes/rube-goldberg-machine/media/demo.mp4) · [Original creator post](https://x.com/leogao25/status/2102544078927741369)

## [Pirate Ship at Sunset](outcomes/sunset-pirate-ship/outcome.md)

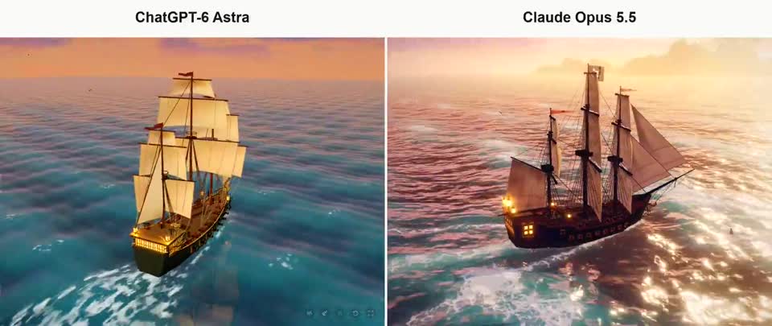
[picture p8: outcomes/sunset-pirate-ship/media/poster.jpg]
Pirate Ship at Sunset (https://x.com/vib3coded/status/2102533729746882985)


[Copy the prompt](outcomes/sunset-pirate-ship/prompt.md) · [Watch demo](outcomes/sunset-pirate-ship/media/demo.mp4) · [Original creator post](https://x.com/vib3coded/status/2102533729746882985)

## [Kinetic Motion Design Reel](outcomes/kinetic-motion-design-reel/outcome.md)

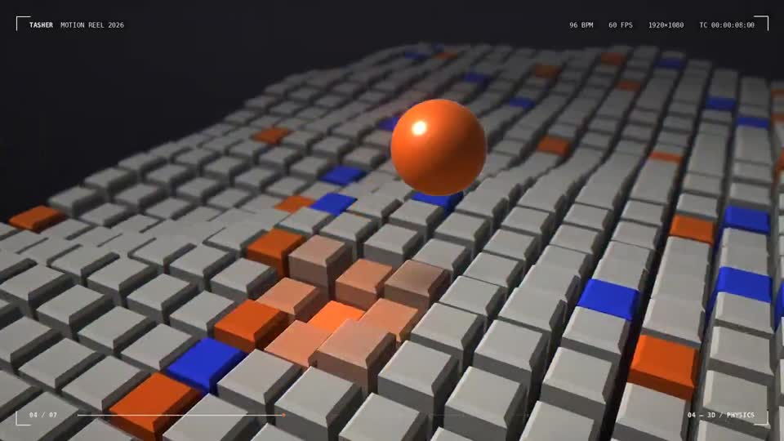
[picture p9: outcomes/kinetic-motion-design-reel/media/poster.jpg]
Kinetic Motion Design Reel (https://x.com/Dannnnnok/status/2103846630088716687)


[Copy the prompt](outcomes/kinetic-motion-design-reel/prompt.md) · [Watch demo](outcomes/kinetic-motion-design-reel/media/demo.mp4) · [Original creator post](https://x.com/Dannnnnok/status/2103846630088716687)

## [Explore a 3D Pagoda](outcomes/navigable-3d-pagoda/outcome.md)

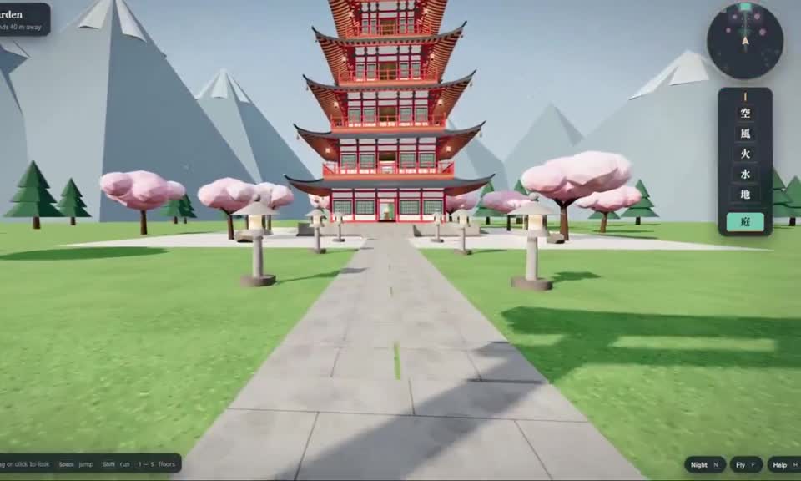
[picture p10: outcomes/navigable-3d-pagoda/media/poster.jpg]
Explore a 3D Pagoda (https://x.com/BuildFastWithAI/status/2103483174957597035)


[Copy the prompt](outcomes/navigable-3d-pagoda/prompt.md) · [Watch demo](outcomes/navigable-3d-pagoda/media/demo.mp4) · [Original creator post](https://x.com/BuildFastWithAI/status/2103483174957597035)

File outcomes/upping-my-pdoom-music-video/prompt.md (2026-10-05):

I've included an MP4 file and an original link to a video that is called "Claude Pop." It's a pop song that is about increasing rate of progress and the experience of the singularity approaching.

I want you to independently do an end-to-end complete pass on making an updated version of this video. Use the exact same audio track and think and feel very deeply about what is the best way to visually represent all of the lyrics on screen. You do not need to anchor to the current style, you can do truly anything that you think might best let you visually express yourself, including abstract motion graphics.

You can use the internet freely to pull in references. You can look at motion design. I want you to make a new music video that has beautifully rendered JavaScript animations with a papery feel in a similar style to the reference that is created, but push the aesthetics in any direction you want and consider what is part of the modern zeitgeist.

Also, think about your current capabilities and what is realistic for you to be able to do. You can go through the full /asic folder and look at the other work that I've done. You should be able to use the skill mesh to look at the compendium of references that I've pulled, and also the skill video scoring to learn how to make JavaScript songs from references that are passed in (You shouldn't need to modify the song in any real way, but I want you to have this available to you so you can better creatively express yourself)

You can also use the ElevenLabs API to do sound design. There's documentation in /asic to do this, and you can see the API key.

There's also a foul API key that's available to you. I think what might make the most sense here is using the foul API key to generate some character sheets and probably having a pop protagonist that represents you. There's already an anchor point where Claude has a sunflower-esque character, and you could likely do an adapted version of this that is similar to the feminine vocals that are being delivered and is inspired by the Claude character, but maybe feels a bit more personified in some way.

I think you should be mindful of aesthetics here, and I don't want you to produce something that is GPT slop. Instead, I'd be more impressed if you come up with a coherent style that works well with the image gen models that are available via foul. Generate the style sheet. You can use the gen media documentation for seedance 2.5 that exists in my markdown files and come up with your own style that makes sense and that works well with the models.

I wouldn't fit too heavily to Pixar. I think it's kind of slop. Think critically about what is relevant here and what would be fun, and also perform well on Twitter as far as an aesthetic. I think that K-pop is a good anchor point visually that you can pull from, but I'll let you cook here.

Once you have your character sheet, you can make a few backup dancers and some supporting characters as you see fit. You can design your own sets with the foul API. You can insert the characters and then do seedance 2.5 video generations to serve as the base assets for this, and you could pass in the lyrics so you can generate individual scenes.

You don't need to have vocal singing, like visible lip movement, throughout the entire thing. Think like a regular music video where you have some inserts that are done independently and don't have the characters in them, or you see the characters doing something else entirely different. I think that for the world building for this, we want to create the sense of speeding up, and so I would like you to audit all of the different events, like the Navi Stokes and all of the Twitter hype around math getting eaten up. Think really critically about how to integrate all of the current memes that are in the zeitgeist on the Twitter timeline, and all of the feelings around AI progress.

Think about things like the Shinji meme and all of the words that are around him, and how you might be able to integrate this. You can also just take straight assets and insert things into the video in an internet brutalism style. You should feel very creatively free in order to do what you want here, but try and anchor to visual references that people will be able to understand. The goal for this is to have it be appreciated by people widely in a San Francisco tech Twitter audience.

We need a very strong, compelling visual hook that gets people excited and appreciates the work that you've done here really quickly. You can also just go and study other music videos and understand what they've done really well. I think that K-pop is probably one of the best examples that we can pull from, and thinking about how they direct human attention and manage human psychology in the way that they use visual patterns.

This is probably your best approach, but taking more stylistic freedom instead of having to anchor to K-pop too intensely. The best version of this is seedance 2.5 generations with those image bases of environments and characters inserted into them with singing, and ideally we get good lip syncing. You can cut up the song and actually pass it in as a reference in seedance, if that's part of what seedance can handle, so that the timing is exactly right, I think it'd be very important for you to do that properly. I would think critically about how to do this, like really nailing the timing of the delivery of voices. You'll want to build out the right verification loops so that you can run seedance 2.5 as much as you need, and confirm that the audio is properly synced up.

I think after that, what might be fun is if you use your visual reasoning skills and your ability to build animations in JavaScript, and then reconstruct the video from scratch as sort of an overlay, so that the visual continuity of the base is really there. It's like that animation technique where you shoot first in traditional film and then draw over top of it. I think you could do this in such a way that we're only looking at the beautiful drawing that you've produced in JavaScript as an overlay, and we don't even see the base assets from seedance 2.5. So all the video gen work that you do is actually just a way to give you a strong foundation of a base to work with for your JavaScript animations. Just because seedance 2.5 has really good character representation and physics rendering for backgrounds, that gives you a lot of ammunition to then go and do your amazing JavaScript work that I know you're so good at.

I think too, we want to think about how to retain attention, and one of the best ways to do this is through text on screen.

It'd be good to have amazing motion graphics of the text lyrics that are actually embedded into the video itself. And you can think about this as you are composing shots. As you're making backgrounds and inserting characters, we can think about where we want to have lyrics be really big and really present, so the background can be less busy there, and you can position the characters perhaps on the right as lyrics appear on the left.

You want to have some variance, so sometimes I think lyrics will just appear more like subtitles, and then other times they're going to be really present and really big. I think at the start for the visual hook, we do want to have lyrics be much more visually present because that's a strong way to grab people's attention

Overall, I just really want to emphasize how amazing you are as an agent and a language model, and now a visual reasoning system. Your capabilities are far beyond what you understand, and I want you to have this mindset as you're going through this entire process. I have a Claude Max plan with 100% available usage. I want you to spend all of the usage. You can monitor it, and you should be pushing tokens aggressively, but also economically, so you can think about how to best use what is available to you.

Remember, you can really do anything here. The goal is to make a banger for Twitter, and the stretch goal is to make something better than anyone's ever seen before. I think that what I would remind you of is that sometimes when things cohere together, it can be jarring or abrasive because the thought work has not been done beforehand in order for everything to mesh cleanly. You need to be really rigorous in planning of composition and timing to make sure this goes well.

You also need to be open to going back and revisiting things in order to be able to reiterate. You're going to want to watch the entire video multiple times, take screenshots at individual parts, and think about if something is really up to the bar of quality that we need here. I trust that you can do this, and I think that it's really important to nail the style of animations. The reference GitHub attached of the source video that I'm talking about is good, but it's really not there. It could be much, much stronger, but it gives you a good foundation to work with.

You can also use search abilities and find other references to pull from for motion, for JavaScript, animations, et cetera, and integrate them. Your budget is as high as you want here, effectively as high as you want. I think that there's roughly two grand in foul credits. Again, be economical; don't go crazy, but spend what you want here and see what you can cook up

here's the source code for the JS animation video: https://github.com/JohnHeibel/PDoomVideo

here's a mp4 for the original blender video:  
(linked)

orginal twitter post  
https://x.com/other__reality/status/2102514581684052169?s=20

make no mistakes.

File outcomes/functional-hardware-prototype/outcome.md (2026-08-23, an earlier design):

# Flat-Pack Corridor Cat Shelter CAD Prototype

Design a fully printable, screw-free cat shelter with a captured triangular roof, replaceable panels, and concealed ballast bays for an HDB corridor.

## Original request

> Can u use $possible from repos/possible to make a cat house?

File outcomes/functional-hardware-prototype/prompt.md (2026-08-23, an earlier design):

Design a fully 3D-printable, screw-free, flat-pack cat shelter for supervised indoor use immediately outside an HDB flat door in a spacious corridor. It should fit a typical adult cat, include a floor and stable base, and resist being flipped by using concealed compartments for removable ballast that the owner supplies separately.

Use interlocking or snap-fit walls connected to the base and a triangular roof that is mechanically captured by the wall geometry. The assembled shelter must not depend on screws, glue, tape, or non-printed structural fasteners. Make panels replaceable and make the roof attachment understandable in both the CAD and the exploded view. Keep every part printable through a commercial large-format FDM service; disclose the largest part dimensions and do not pretend it fits a common desktop printer.

Deliver editable parametric CAD source, an assembled STEP model, an exploded STEP model, individual STEP parts, and print-oriented STL exports. Include clear assembled, exploded, ballast-base, and roof-lock renders. Check that the solids are valid, the intended interfaces overlap correctly, the entrance is usable, and the assembled envelope and largest part are reported.

This is a digital pre-build only. Do not purchase, fabricate, expose it to an animal, or claim that the snap fits, ballast, stability, edges, material, weather resistance, hygiene, durability, or corridor suitability have been physically validated. State the coupon, assembly-cycle, push, under-ballast, contact-edge, and cleaning tests that must happen before use, and return the result as repair-required until those tests exist.

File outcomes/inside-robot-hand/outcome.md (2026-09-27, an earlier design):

# Inside a Robot Hand

Open a robot hand to explore its motors and gearboxes, then compare how gear ratios affect motion.

## Try it

Copy the creator’s disclosed prompt into Claude Opus 5.5. A coding assistant and a WebGL-capable browser. The creator also provides a live interactive demo. [Open the interactive demo](https://zerotimedrift.github.io/inside-the-hand/).

## Creator

By [H](https://x.com/thermalpastor). [Full demo and original prompt](https://x.com/thermalpastor/status/2102928996900200562). The preview is an excerpt of the actual creator video; comparison labels are retained.

## What to know

The post discloses the task sentence, not a complete session transcript. The linked app is an educational visualisation, not a validated engineering simulator. Model attribution is creator-reported. Possible checked the source pairing and preview playback; we did not regenerate this result or independently test Opus.

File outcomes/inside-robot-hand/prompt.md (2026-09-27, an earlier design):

create an interactive 3D visualisation explaining how robot actuators work

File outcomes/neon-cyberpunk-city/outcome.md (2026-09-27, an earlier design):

# Rainy Neon Cyberpunk City

Fly past luminous towers and rainy streets in a neon-lit Three.js city.

## Try it

Copy the creator’s disclosed prompt into Claude Opus 5.5. A coding-capable Claude environment and a WebGL-capable browser.

## Creator

By [paddy](https://x.com/0xPD33). [Full demo and original prompt](https://x.com/0xPD33/status/2102454871899443432). The preview is an excerpt of the actual creator video; comparison labels are retained.

## What to know

The creator reports max reasoning in the Claude web app. The one-line prompt leaves architecture, camera paths and visual details to the model. Model attribution is creator-reported. Possible checked the source pairing and preview playback; we did not regenerate this result or independently test Opus.

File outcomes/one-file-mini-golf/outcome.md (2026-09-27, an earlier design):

# One-File Mini Golf

Putt across a bright miniature course with a power meter, obstacles and a tiny course map.

## Try it

Copy the creator’s disclosed prompt into Claude Opus 5.5. A coding assistant that can save an HTML file and a browser to run it.

## Creator

By [Hunter](https://x.com/hunterjreid). [Full demo and original prompt](https://x.com/hunterjreid/status/2102718456026325132). The preview is an excerpt of the actual creator video; comparison labels are retained.

## What to know

The creator compares two models with the same prompt; the shown Opus result is the top half. Generated source was not supplied in the post. Model attribution is creator-reported. Possible checked the source pairing and preview playback; we did not regenerate this result or independently test Opus.

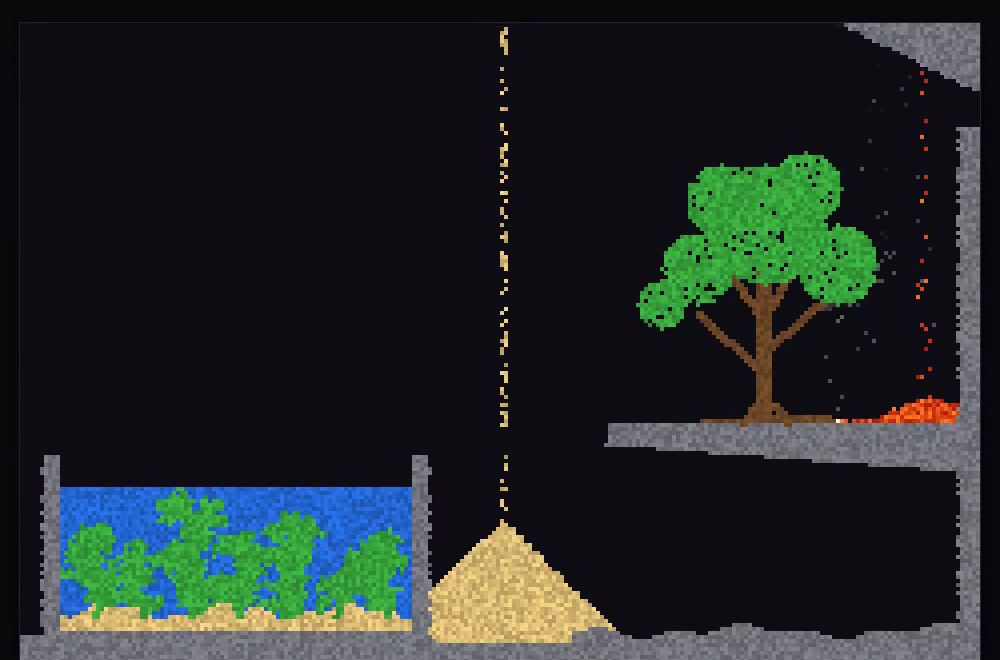
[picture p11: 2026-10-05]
outcomes/falling-sand-sandbox/media/poster.png

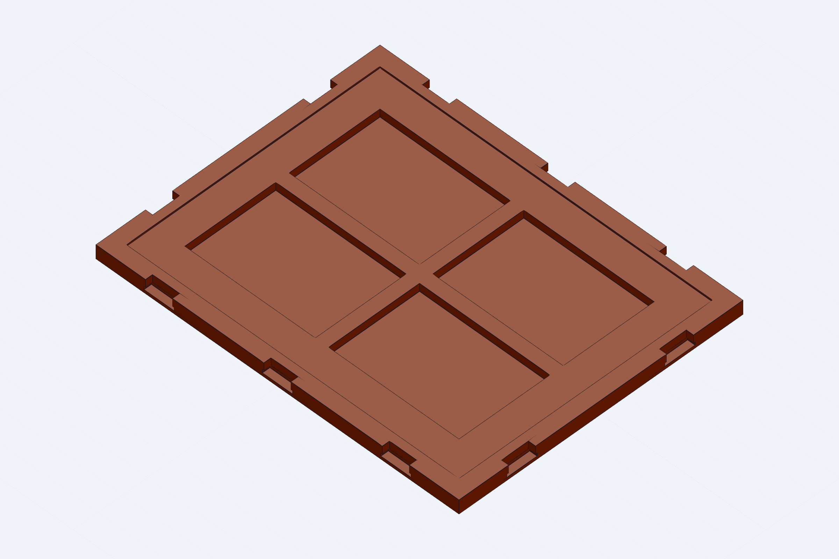
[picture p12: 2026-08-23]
outcomes/functional-hardware-prototype/media/cat-shelter-ballast-base.png

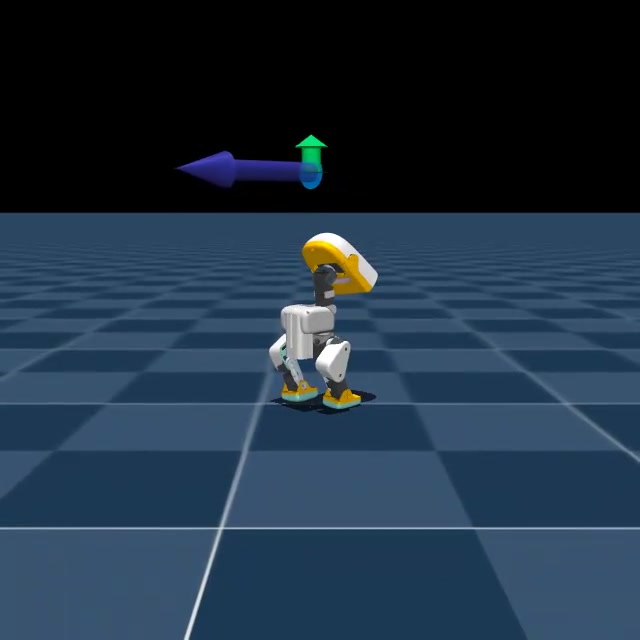
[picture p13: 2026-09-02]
outcomes/microduck-learned-happy-shuffle/media/happy-shuffle-poster.jpg

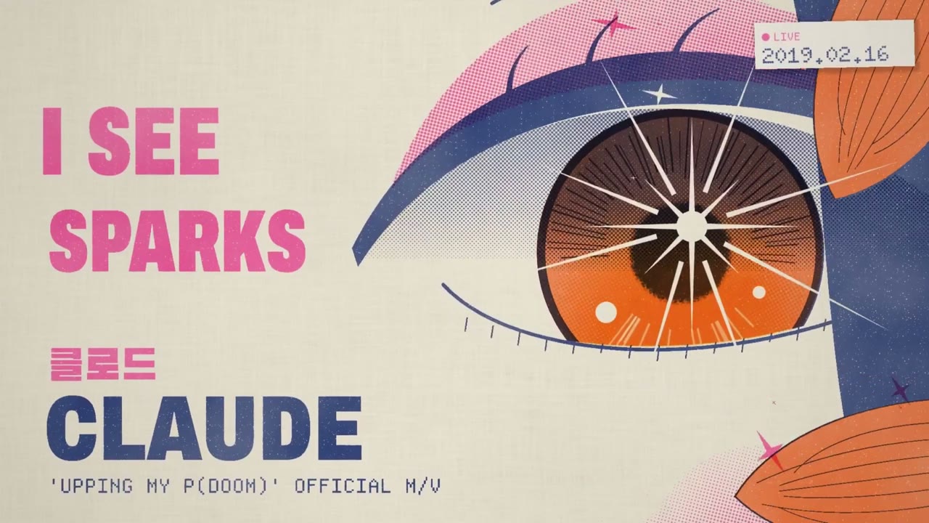
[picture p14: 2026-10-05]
outcomes/upping-my-pdoom-music-video/media/poster.jpg

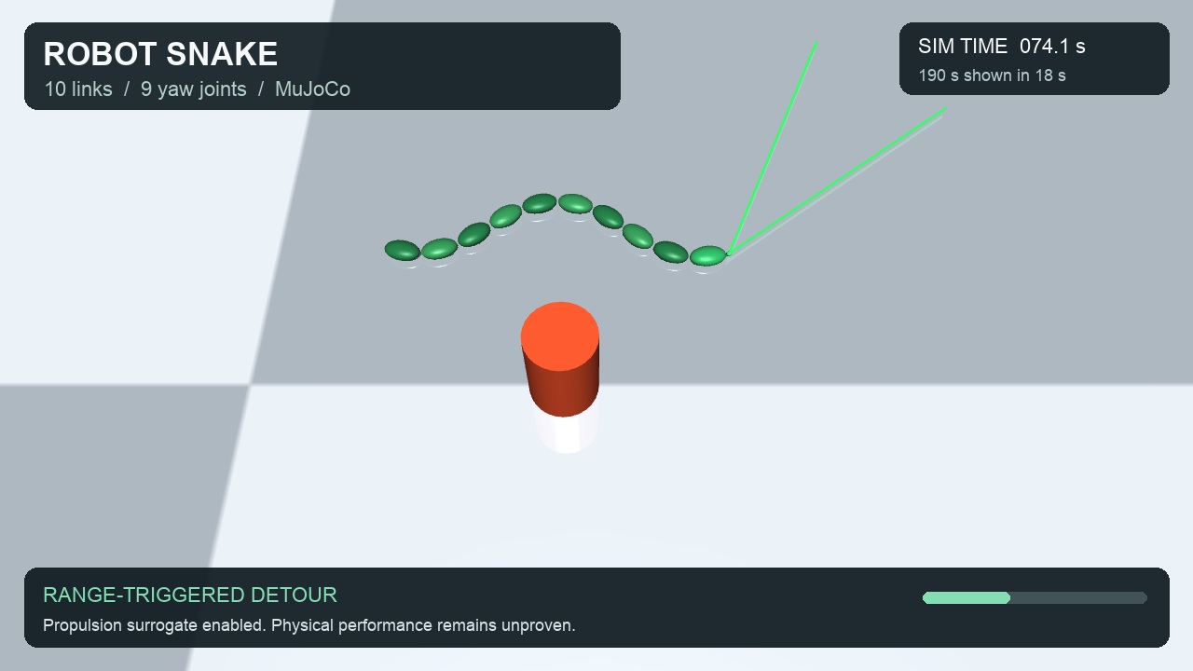
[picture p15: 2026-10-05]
outcomes/slithering-robot-snake-prototype/media/poster.jpg

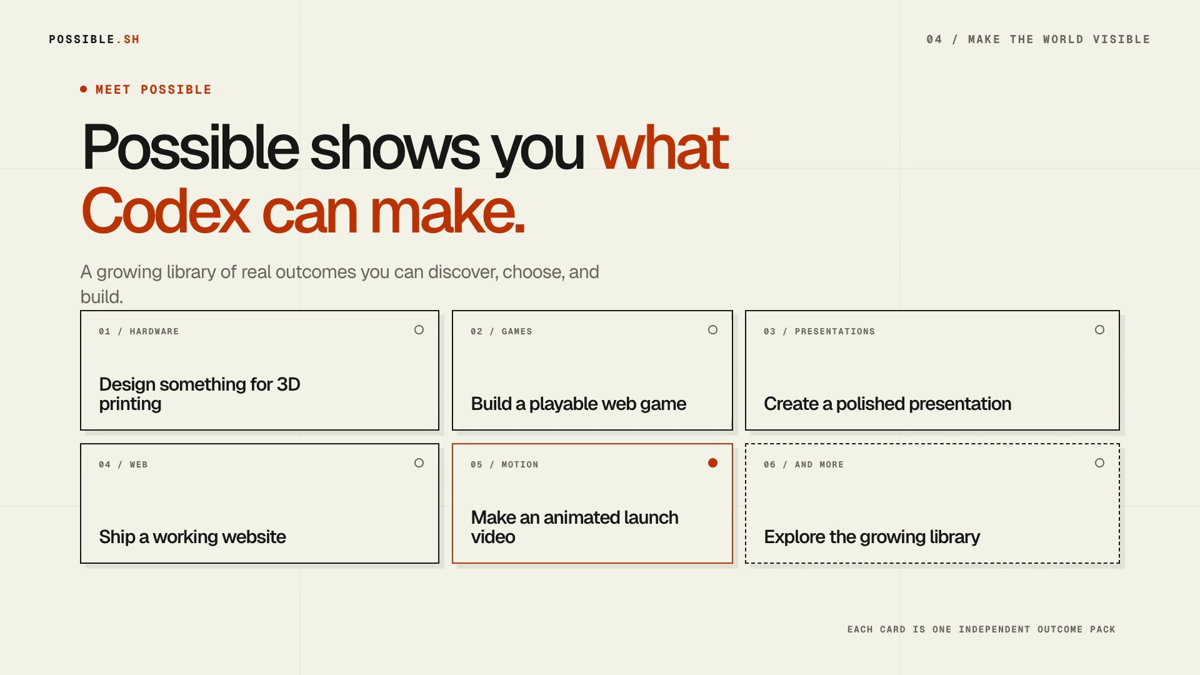
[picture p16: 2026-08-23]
outcomes/html-css-animated-product-launch-film/media/possible-launch-film-poster.jpg

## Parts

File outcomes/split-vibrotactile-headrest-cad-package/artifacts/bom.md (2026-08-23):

# Connectorized BOM and sourcing shortlist

Evidence checked: 2026-07-25. Prices and stock can change. Checkout delivery
dates are not verified orders.

No item may be bought until the exact cart, landed cost, delivery date, and
vendor are separately approved.

## Operator inventory and purchase status

Confirmed owned:

- Raspberry Pi 4 host.
- RØDE AI-1 USB audio interface.

Confirmed ordered on 2026-07-26:

- Dayton Audio TT25-8, 8-ohm version, from
  [Amazon Singapore](https://www.amazon.sg/Dayton-Audio-TT25-8-Tactile-Transducer/dp/B009RGJ47S).

Not yet confirmed as owned, ordered, or available: Fosi V1.0G, the exact
1/4-inch-to-RCA interconnect, speaker cable/connectors, microSD, switched
strip, power meter, suitable true-RMS low-pass meter, sound meter, thermometer,
calibrated load, or bench equipment. A hope of borrowing equipment is not a
budget line.

## Recommended chain

| Role | Exact item or bounded equivalent | Evidence | Connectorization / assembly | SGD estimate | Timing and uncertainty |
| --- | --- | --- | --- | ---: | --- |
| Tactile actuator | **Dayton Audio TT25-8**, 8 ohm, conservatively bounded to 15 W continuous / 30 W max pending received label, 20–80 Hz, Fs 40 Hz | [Current manufacturer product page, checked 2026-07-26](https://www.daytonaudio.com/product/1104/tt25-8-puck-tactile-transducer-mini-bass-shaker) states 15 W RMS / 30 W max; [exact Amazon SG item ordered 2026-07-26](https://www.amazon.sg/Dayton-Audio-TT25-8-Tactile-Transducer/dp/B009RGJ47S) resolves to model TT25-8 | Finished actuator with wire leads. Bare unit uses six #6 screws; inspect the delivered bundle before selecting the mount path | Ordered; exact paid total not recorded | Correct model and impedance are locked. Arrival date, received label, included ring/hardware, mount path, and physical fit remain inspection gates. |
| Optional surface ring | **Dayton Audio SMRK-2**, only for mount path A | [Manufacturer SMRK-2 page](https://www.daytonaudio.com/product/1656/smrk-2-surface-mounting-ring-kit-for-tt25-puck-mini-bass-shaker) lists the ring as an accessory kit | Finished three-point ring; exact received geometry must be transferred | Unpriced | No Singapore cart, stock, delivery, or landed cost is verified. Omit only if TT25 cart proves inclusion or bare six-tab path is selected. |
| Host | **Raspberry Pi 4**, operator-owned | Existing operator inventory | USB-A host connection; runs finite non-looping WAV playback | Owned | Raspberry Pi OS recognition of the AI-1, sample rate, channel map, underrun-free playback, and silence before/after the file require a bench preflight. |
| Audio interface | **RØDE AI-1**, operator-owned | [RØDE product page](https://rode.com/en-us/products/ai-1) specifies two balanced 1/4-inch monitor outputs; its user guide specifies a -6 dBu maximum monitor output | USB bus powered; use left rear line output, not the microphone input or direct actuator connection | Owned | Its maximum line output exceeds the Fosi's published input sensitivity, so it is adequate but cannot serve as a power limiter. |
| Amplifier | **Fosi Audio V1.0G**, exact candidate | [Fosi product page](https://fosiaudio.com/products/v1-0g-2-channel-stereo-audio-class-d-amplifier-mini-hi-fi-professional-digital-amp-for-home-speakers-50w-x-2-with-powersupply-fosi-aud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) specifies RCA input, 2–8 ohm loads, 19 V adapter and input sensitivity <=280 mV | Enclosed and assembled. Use only the left RCA input and left speaker output; never bridge channels | Quote required | Ownership/order not confirmed. The amplifier can overpower the TT25-8; it does not replace the 9.5 V RMS abort gate. |
| Vibration logger | **SparkFun OpenLog Artemis DEV-16832** | [Mouser SG](https://www.mouser.sg/ProductDetail/SparkFun/DEV-16832?qs=hWgE7mdIu5RLSvRkxZwC3g%3D%3D) showed 32 in stock, dispatch immediately, S$83.33; [SparkFun](https://www.sparkfun.com/sparkfun-openlog-artemis.html) specifies CSV logging and IMU up to 250 Hz | Fully assembled board; USB-C power/configuration and microSD logging; no soldering | 83.33 | Strongest delivery evidence. Add microSD and USB-C cable if not already owned. Bare board requires a nonconductive mount/enclosure. |
| Logger alternative | **WitMotion WT901BLECL**, ±16 g, up to 200 Hz, USB-C cable included | [WitMotion](https://witmotion-sensor.com/products/bluetooth-5-0-accelerometer-inclinometer-wt901blecl-mpu9250-9-axis-imu-sensor) showed US$28.90 (~S$39 before freight) | Assembled enclosed wireless sensor with built-in battery and USB-C charging | 50 landed allowance | Delivery to Singapore and 200 Hz packet completeness are unverified. Charging and Bluetooth add failure modes. Use only if OpenLog timing or budget fails and checkout is approved. |
| Power measurement | **GMM-DDS108 Type-G power meter** | [Testmeter SG](https://testmeter.sg/products/GMM-DDS108-Digital-Power-Consumption-Energy-Meter-UK-Plug-Socket/) showed in stock, S$26.80 incl. tax | Finished plug-in instrument; no wiring | 26.80 | Measures whole-chain AC input, not actuator electrical power. Use voltage/current measurements separately if available. |
| Required actuator-voltage instrument | **Fluke 87V** true-RMS battery handheld meter with intact TL75 or equivalent shrouded leads, AC low-pass mode, and calibration/service state recorded | [Fluke Singapore](https://www.fluke.com/en-sg/product/electrical-testing/digital-multimeters/fluke-87v) specifies true RMS and a low-pass filter for noisy PWM-drive outputs; [RS Singapore](https://sg.rs-online.com/web/p/multimeters/4802355) showed S$953 | Fully assembled floating handheld instrument; attach across speaker terminals while amplifier is off/unplugged; no soldering, current jack, chassis earth, or oscilloscope ground clip | S$953 if bought; **owned/borrowed-only** | Buying it alone exceeds the complete S$300 budget by S$653. If it cannot be borrowed, this prototype is no-go under the current budget. Wall input power is not a substitute. |
| Budget hard-limit candidate | **RS PRO 175-3303**, Type-G regulated 12 V / 1 A / 12 W, 2.1 × 5.5 mm centre-positive, overload/overvoltage protected | [RS Singapore](https://sg.rs-online.com/web/p/ac-dc-adapters/1753303) showed S$19.40 incl. GST and 46 units ready to ship | Fully assembled molded lead; no soldering | 19.40 | Power conservation makes a genuinely current-limited 12 W DC source attractive, but the published page does not state the overload-current/time curve. It is not a sole 15 W control until exact amplifier barrel/polarity/startup compatibility and continuous current limit below 1.25 A are documented. |
| Manual disconnect | Reputable switched Type-G power strip already owned; otherwise a locally certified equivalent | Exact owned model must be recorded before use | Finished mains accessory; no modified AC leads | 0–20 | This is a manual disconnect, not a safety-rated E-stop. Reject travel adapters and unmarked products. |
| Speaker interconnect | 18–20 AWG stranded copper speaker lead plus **WAGO 221-2411** inline lever connector or direct amplifier spring terminal | [WAGO manufacturer record](https://www.wago.com/global/installation-terminal-blocks-and-connectors/inline-splicing-connector-with-levers/p/221-2411) specifies 0.2–4 mm² and all conductor types; [TT25 manual](https://www.daytonaudio.com/images/resources/dayton-audio-tt25-8-tt25-16-user-manual.pdf) permits standard wire nuts | Pre-cut/stripped by supplier or fabricator; lever connection; no solder | 10 | Exact cable OD, connector envelope, strip length, route, and bend radius are release blockers. No loose copper strands permitted. |
| Audio cable | Shielded 1/4-inch TS male-to-RCA male cable, <=1.5 m | Finished cable from a known retailer | AI-1 left rear output to Fosi left RCA input; no Y-splitter required | 8–15 | Confirm continuity/pinout before powered testing. Right channel remains disconnected. |
| Logger media/power | 8–32 GB genuine microSD and data-capable USB-C cable, if not owned | [SparkFun guide](https://learn.sparkfun.com/tutorials/openlog-artemis-hookup-guide/hardware-hookup) documents microSD logging | Finished parts | 0–20 | Prefer owned known-good items; format and destructive erase require explicit bench approval. |

## Budget scenarios

These modeled totals exclude the currently unpriced SMRK-2 accessory. None is
purchase-ready until the exact TT25 cart proves ring inclusion or the mount
decision selects the bare six-tab path.

They originally assumed some items were owned or borrowed. The Pi 4 and AI-1
are now confirmed owned, and the TT25-8 is ordered; all other ownership and
access assumptions remain invalid. Buying the S$953 reference instrument makes
every S$300 all-in scenario a no-go. The S$19.40 12 W adapter candidate can
become one bounded design control only after its overload behavior and exact
amplifier compatibility are verified; it does not replace vibration,
temperature, noise, or fit evidence.

| Scenario | Electronics and measurement | Remaining from S$300 | Decision |
| --- | ---: | ---: | --- |
| Current core: ordered TT25 + owned Pi 4/AI-1 + Fosi + finished interconnects | Quote required | Unknown | Mechanically and electrically coherent; paid actuator total, Fosi status, cable cart and fabrication quote remain unrecorded. |
| Current measured prototype: core + logger and verification access | Quote required | Unknown | Cannot earn a `working` receipt until logger, voltage access, sound, temperature, load and fixture evidence are named and priced. |

Current conclusion: **S$300 all-in feasibility is not established.** The next
useful comparison is (A) exact product cart + enclosed-body quote and (B) a
separate quote or named access route for measurement/verification. Do not hide
verification cost inside “borrowed.”

## Purchase gate

Proceed only if one cart satisfies all of these:

- actuator, amplifier, adapter, logger, and interconnect arrive by the locked
  assembly date;
- exact cart proves whether SMRK-2 is included; otherwise the cart adds the
  ring or the approved design selects the bare six-tab mount;
- amplifier variation includes the stated power adapter and supports the
  actuator impedance;
- electronics plus confirmed fabrication remain <=S$300;
- a named Fluke 87V-class or reviewed exact-equivalent access route is
  available with intact shrouded leads, service state, date, provider and cost;
  none is currently available;
- any proposed 12 W supply substitute has an exact connector/polarity match
  and a documented continuous current limit below 1.25 A at 12 V;
- no operator soldering is required;
- seller pages and checkout screens are saved as evidence;
- alternatives are not silently substituted.

If no cart satisfies the gate, report `no-go` or request a budget/deadline
decision. Do not buy a visually similar actuator or amplifier without revising
the interfaces and test plan.

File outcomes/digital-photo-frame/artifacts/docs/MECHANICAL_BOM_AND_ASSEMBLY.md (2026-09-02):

# Mechanical BOM and assembly instructions

## Hardware BOM

| Qty | Item | Specification / status |
|---:|---|---|
| 1 | Front bezel | Printed prototype from `front_bezel.stl` |
| 1 | Rear chassis | Printed prototype from `rear_chassis.stl` |
| 1 | Service cover | Printed prototype from `service_cover.stl` |
| 1 | Folding stand | Printed prototype from `folding_stand.stl` |
| 4 | M3 heat-set insert | Brass, nominal 4.6-5.0 mm OD x 4-6 mm; exact vendor not selected |
| 4 | M3 service-cover screw | M3 x 8 mm, low-profile pan/button head; verify grip length |
| 4 | PCB standoff screw | M3 x 6 mm nylon or metal with insulating washer; exact stack unverified |
| 1 | Hinge pin | 5 mm nominal diameter x 140 mm max; exact retention hardware not selected |
| 1 set | Display pads/gasket | Replaceable closed-cell compliant pads, 0.5-1.0 mm |
| as needed | Strain relief | Serviceable USB-C cable clip or tie mount; not yet modelled |

The hardware list is a prototype selection guide, not a released procurement
BOM. Insert hole size, screw length, hinge-pin tolerance and polymer material
must be resolved with the chosen print process.

## Assembly sequence

1. Inspect printed parts and chase support material from the service-cover,
   connector and hinge openings. Install four M3 heat-set inserts without
   distorting the chassis bosses.
2. Apply compliant pads only to the display module's metal frame. Seat the
   display against the front ledge without contacting active glass.
3. Install the controller PCB on its four mapped standoffs. This step is blocked
   for the current digital result because no DRC-clean populated PCB STEP exists;
   first validate real connector reach and underside solder clearance.
4. Mate J2 and provide service slack/strain relief. Verify USB-C and microSD
   insertion before closing the cover.
5. Align the three button plungers/light openings; confirm the ambient sensor is
   optically exposed and the LED points rearward.
6. Fit the service cover using four reusable M3 screws. Do not glue the cover.
7. Install the hinge pin, verify the folded detents engage, and verify the two
   stand tabs land on the chassis hard stops at the deployed angle.
8. Perform low-voltage electrical bring-up with the cover removed, then repeat
   thermal and insertion checks with the enclosure assembled.

All four manufactured parts fit a stated 220 x 140 x 30 mm flat-oriented build
envelope. No statement is made about slicer settings, warping, strength,
tolerance stack, cycle life or print quality.

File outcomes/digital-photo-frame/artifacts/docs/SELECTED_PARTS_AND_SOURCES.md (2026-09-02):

# Selected exact parts and manufacturer sources

These are the BOM selections embedded in the KiCad schematic. Availability,
life-cycle status, distributor stock and the display's orderable configuration
suffix were not verified; no purchasing claim is made.

| Function | Manufacturer / exact MPN | Package/footprint | Manufacturer source | Local source receipt |
|---|---|---|---|---|
| Display | EastRising ER-TFTM070-4V3, 5 V, 8-bit 8080, no-touch configuration | Module, 2x20 2.54 mm header | https://www.buydisplay.com/download/manual/ER-TFTM070-4V3_Datasheet.pdf | Direct download rejected; URL and rejection receipt retained |
| MCU module | Espressif ESP32-S3-WROOM-1-N16R8 | ESP32-S3-WROOM-1 | https://www.espressif.com/sites/default/files/documentation/esp32-s3-wroom-1_wroom-1u_datasheet_en.pdf | PDF saved |
| 3.3 V buck | Texas Instruments TPS62132RGTR | VQFN-16, 3 x 3 mm, exposed pad | https://www.ti.com/lit/ds/symlink/tps62132.pdf | TPS6213x family PDF saved |
| USB-C receptacle | GCT USB4105-GF-A | 16-position horizontal top mount | https://gct.co/files/drawings/usb4105.pdf | drawing and product specification saved |
| microSD socket | Molex 104031-0811 | Molex 104031 footprint | https://www.molex.com/content/dam/molex/molex-dot-com/products/automated/en-us/productspecificationpdf/104/104031/PS-104031-001-001.pdf | direct download unavailable |
| Ambient sensor | Lite-On LTR-303ALS-01 | 2 x 2 mm six-pin optical package | https://optoelectronics.liteon.com/upload/download/DS86-2013-0004/LTR-303ALS-01_DS_V1.1.PDF | request-rejection HTML retained, not mislabeled as PDF |
| USB ESD | STMicroelectronics USBLC6-2SC6 | SOT-23-6 | https://www.st.com/resource/en/datasheet/usblc6-2.pdf | direct download unavailable |
| Input PTC | Bourns MF-MSMF200-2 | 1206 | https://www.bourns.com/docs/product-datasheets/mf-msmf.pdf | URL in BOM |
| 5 V TVS | Littelfuse SMAJ5.0A | SMA | https://www.littelfuse.com/assetdocs/littelfuse-tvs-diode-smaj-datasheet | URL in BOM |
| Buck inductor | Coilcraft XAL4020-102MEC | XAL4020 | https://www.coilcraft.com/getmedia/5e5308cc-2480-4f52-be4a-cbbfc5c2eb1f/xal4020.pdf | URL in BOM |
| User/reset/boot switches | C&K KMR221GLFS | KMR2 SMD | https://www.ckswitches.com/media/1479/kmr2.pdf | URL in BOM |
| Status LED | Lite-On LTST-C191KGKT | 0603 | https://optoelectronics.liteon.com/upload/download/DS22-2000-228/LTST-C191KGKT.pdf | URL in BOM |
| Debug header | Harwin M20-9990646 | 1x6, 2.54 mm | https://cdn.harwin.com/pdfs/M20-999.pdf | URL in BOM |

The generated schematic BOM also fixes Murata capacitor and Yageo resistor MPNs
and Keystone 5015 test points. See `models/kicad/exports/photo_frame_bom.csv` for
the complete exact-part table and datasheet links.

## Display dimensional and pinout source facts used

- Resolution 800 x 480; SSD1963 controller; landscape module.
- Module outer envelope 180 x 100 mm; documented maximum thickness 12.8 mm.
- Active area 154.08 x 85.92 mm.
- Four 3.2 mm mounting holes on 174 x 98 mm centres.
- Maximum module current used for the budget: 480 mA at 5 V.
- Pin map: 1 GND, 2 5V, 3 /CS, 4 D/C, 5 /RD, 6 /WR, 7 RESET,
  8 TE, 9-32 DB0-DB23, 33-38 touch-related, 39 BL_ON/OFF/PWM, 40 NC.

The base MPN does not encode every selectable factory interface/no-touch option.
An order must quote and confirm the exact 5 V, 8-bit 8080, no-touch, pin-header
configuration with EastRising before procurement. That is an unresolved
ordering assumption, not an invented suffix.

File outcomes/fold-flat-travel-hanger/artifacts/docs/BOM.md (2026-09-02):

# Bill of materials

| Qty | Item | Source / specification | Notes |
| ---: | --- | --- | --- |
| 1 | Center yoke | Printed from `center_yoke.step` | Arm cheek plates, lock guide and hook clevis are one part. |
| 1 | Left shoulder arm | Printed from `left_shoulder_arm.step` | Deep solid beam, captured root and shallow strap notch. |
| 1 | Right shoulder arm | Printed from `right_shoulder_arm.step` | Mirror of left with unique component name. |
| 1 | Folding hook | Printed from `folding_hook.step` | 42 mm rod pocket, 40 mm throat. |
| 1 | Dual positive lock bar | Printed from `dual_positive_lock_bar.step` | Rigid linked blocking member and recessed thumb pad. |
| 2 | Arm shoulder screw | Purchased M5 × 18 mm shoulder-length, low-profile head | Simplified envelope in CAD. Use an unthreaded shoulder through the rotating stack. |
| 1 | Hook shoulder screw | Purchased M5 × 26.25 mm shoulder-length, low-profile head | Simplified envelope in CAD; the shoulder spans the main front cheek and outboard hook clevis. |
| 3 | M5 low-profile prevailing-torque locknut | Purchased | Simplified cylindrical envelope in CAD; production selection must be verified. |
| 2 | Compression spring | Purchased, approximately 3.5 mm OD × 10–12 mm free length | Fits around lock guide pegs and biases the bar to engaged. Not modeled because coil geometry changes under compression. |

All pins and nuts remain captured after assembly. None are removed during folding, deployment or use. Printed pins are deliberately not supplied; if improvised for a prototype, they are prototype-only and not the intended load-bearing hardware.

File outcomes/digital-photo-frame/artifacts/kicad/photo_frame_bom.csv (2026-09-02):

Reference | Value | Footprint | MPN | Manufacturer | Datasheet | Description | Quantity
C1,C3,C4 | 22uF 10V X5R | Capacitor_SMD:C_0805_2012Metric | GRM21BR61A226ME44L | Murata | https://search.murata.co.jp/Ceramy/image/img/PDF/ENG/GRM21BR61A226ME44-01.pdf | 3.3 V output capacitor; 10 V rating,Protected 5 V bulk capacitor; 10 V rating | 3
C2 | 10nF 25V X7R | Capacitor_SMD:C_0603_1608Metric | GRM188R71E103KA01D | Murata | https://search.murata.co.jp/Ceramy/image/img/PDF/ENG/GRM188R71E103KA01-01.pdf | Buck soft-start capacitor | 1
C5 | 10uF 10V X5R | Capacitor_SMD:C_0805_2012Metric | GRM21BR61A106KE19L | Murata | https://search.murata.co.jp/Ceramy/image/img/PDF/ENG/GRM21BR61A106KE19-01.pdf | Buck input capacitor | 1
C6 | 10uF 10V X5R | Capacitor_SMD:C_0805_2012Metric | GRM21BR61A106KE19L | Murata | https://search.murata.co.jp/Ceramy/owa/CATALOG.showcatalog | ESP32 local decoupling | 1
C7 | 100nF 16V X7R | Capacitor_SMD:C_0603_1608Metric | GRM188R71C104KA01D | Murata | https://search.murata.co.jp/Ceramy/owa/CATALOG.showcatalog | ESP32 local decoupling | 1
C8 | 100nF 16V X7R | Capacitor_SMD:C_0603_1608Metric | GRM188R71C104KA01D | Murata | https://search.murata.co.jp/Ceramy/image/img/PDF/ENG/GRM188R71C104KA01-01.pdf | Ambient sensor decoupling | 1
D1 | SMAJ5.0A | Diode_SMD:D_SMA | SMAJ5.0A | Littelfuse | https://www.littelfuse.com/assetdocs/littelfuse-tvs-diode-smaj-datasheet | Unidirectional 5 V rail TVS | 1
F1 | 2.0A resettable | Fuse:Fuse_1206_3216Metric | MF-MSMF200-2 | Bourns | https://www.bourns.com/docs/product-datasheets/mf-msmf.pdf | Resettable input current limiter | 1
J1 | USB4105-GF-A | Connector_USB:USB_C_Receptacle_GCT_USB4105-xx-A_16P_TopMnt_Horizontal | USB4105-GF-A | GCT | https://gct.co/files/drawings/usb4105.pdf | USB-C 16-position receptacle; power-only sink | 1
J2 | ER-TFTM070-4V3 8-bit 8080 5V no-touch | Connector_PinHeader_2.54mm:PinHeader_2x20_P2.54mm_Vertical | ER-TFTM070-4V3 | EastRising | https://www.buydisplay.com/download/manual/ER-TFTM070-4V3_Datasheet.pdf | 7-inch 800x480 SSD1963 display module; pin-header configuration | 1
J3 | 104031-0811 | Connector_Card:microSD_HC_Molex_104031-0811 | 104031-0811 | Molex | https://www.molex.com/content/dam/molex/molex-dot-com/products/automated/en-us/productspecificationpdf/104/104031/PS-104031-001-001.pdf | Push-pull microSD socket with detect switch | 1
J4 | DEBUG 1x6 | Connector_PinHeader_2.54mm:PinHeader_1x06_P2.54mm_Vertical | M20-9990646 | Harwin | https://cdn.harwin.com/pdfs/M20-999.pdf | Internal programming and debug header | 1
L1 | 1.0uH 20% | Inductor_SMD:L_Bourns-SRU8028_8.0x8.0mm | XAL4020-102MEC | Coilcraft | https://www.coilcraft.com/getmedia/5e5308cc-2480-4f52-be4a-cbbfc5c2eb1f/xal4020.pdf | Shielded buck inductor; Isat 7.6 A | 1
LED1 | LTST-C191KGKT green | LED_SMD:LED_0603_1608Metric | LTST-C191KGKT | Lite-On | https://optoelectronics.liteon.com/upload/download/DS22-2000-228/LTST-C191KGKT.pdf | Rear-facing green status LED | 1
R1,R2 | 5.1k 1% | Resistor_SMD:R_0603_1608Metric | RC0603FR-075K1L | Yageo | https://www.yageo.com/upload/media/product/productsearch/datasheet/rchip/PYu-RC_Group_51_RoHS_L_13.pdf | USB-C CC1 Rd sink resistor,USB-C CC2 Rd sink resistor | 2
R3 | 100k 1% | Resistor_SMD:R_0603_1608Metric | RC0603FR-07100KL | Yageo | https://www.yageo.com/upload/media/product/productsearch/datasheet/rchip/PYu-RC_Group_51_RoHS_L_13.pdf | Power-good pull-up | 1
R4-R8,R11-R13 | 10k 1% | Resistor_SMD:R_0603_1608Metric | RC0603FR-0710KL | Yageo | https://www.yageo.com/upload/media/product/productsearch/datasheet/rchip/PYu-RC_Group_51_RoHS_L_13.pdf | ESP32 GPIO0 boot pull-up,ESP32 enable pull-up,GPIO45 strap pull-down for 3.3 V VDD_SPI,GPIO46 strap pull-down for normal boot,User-button pull-up,microSD card-detect pull-up | 8
R9,R10 | 4.7k 1% | Resistor_SMD:R_0603_1608Metric | RC0603FR-074K7L | Yageo | https://www.yageo.com/upload/media/product/productsearch/datasheet/rchip/PYu-RC_Group_51_RoHS_L_13.pdf | I2C pull-up | 2
R14 | 1.0k 1% | Resistor_SMD:R_0603_1608Metric | RC0603FR-071KL | Yageo | https://www.yageo.com/upload/media/product/productsearch/datasheet/rchip/PYu-RC_Group_51_RoHS_L_13.pdf | Status LED current limit | 1
SW1-SW5 | KMR221GLFS | Button_Switch_SMD:SW_Push_1P1T-SH_NO_CK_KMR2xxG | KMR221GLFS | C&K | https://www.ckswitches.com/media/1479/kmr2.pdf | Bootloader access,Menu/wake button,Next button,Previous button,Reset access | 5
TP1 | +5V | TestPoint:TestPoint_Pad_D1.5mm | 5015 | Keystone Electronics | https://www.keyelco.com/product.cfm/product_id/13981 | Labeled test point for +5V | 1
TP2 | +3V3 | TestPoint:TestPoint_Pad_D1.5mm | 5015 | Keystone Electronics | https://www.keyelco.com/product.cfm/product_id/13981 | Labeled test point for +3V3 | 1
TP3 | GND | TestPoint:TestPoint_Pad_D1.5mm | 5015 | Keystone Electronics | https://www.keyelco.com/product.cfm/product_id/13981 | Labeled test point for GND | 1
TP4 | LCD_WR | TestPoint:TestPoint_Pad_D1.5mm | 5015 | Keystone Electronics | https://www.keyelco.com/product.cfm/product_id/13981 | Labeled test point for LCD_WR | 1
TP5 | LCD_BL | TestPoint:TestPoint_Pad_D1.5mm | 5015 | Keystone Electronics | https://www.keyelco.com/product.cfm/product_id/13981 | Labeled test point for LCD_BL | 1
TP6 | SD_CS | TestPoint:TestPoint_Pad_D1.5mm | 5015 | Keystone Electronics | https://www.keyelco.com/product.cfm/product_id/13981 | Labeled test point for SD_CS | 1
U1 | ESP32-S3-WROOM-1-N16R8 | RF_Module:ESP32-S3-WROOM-1 | ESP32-S3-WROOM-1-N16R8 | Espressif Systems | https://www.espressif.com/sites/default/files/documentation/esp32-s3-wroom-1_wroom-1u_datasheet_en.pdf | Wi-Fi MCU module; 16 MB flash and 8 MB octal PSRAM | 1
U2 | TPS62132RGTR 3.3V | Package_DFN_QFN:VQFN-16-1EP_3x3mm_P0.5mm_EP1.68x1.68mm_ThermalVias | TPS62132RGTR | Texas Instruments | https://www.ti.com/lit/ds/symlink/tps62132.pdf | 3 A fixed 3.3 V synchronous buck | 1
U3 | LTR-303ALS-01 | OptoDevice:Lite-On_LTR-303ALS-01 | LTR-303ALS-01 | Lite-On | https://optoelectronics.liteon.com/upload/download/DS86-2013-0004/LTR-303ALS-01_DS_V1.1.PDF | I2C ambient-light sensor | 1
U4 | USBLC6-2SC6 | Package_TO_SOT_SMD:SOT-23-6 | USBLC6-2SC6 | STMicroelectronics | https://www.st.com/resource/en/datasheet/usblc6-2.pdf | ESD protection for both USB-C CC pins and VBUS reference | 1

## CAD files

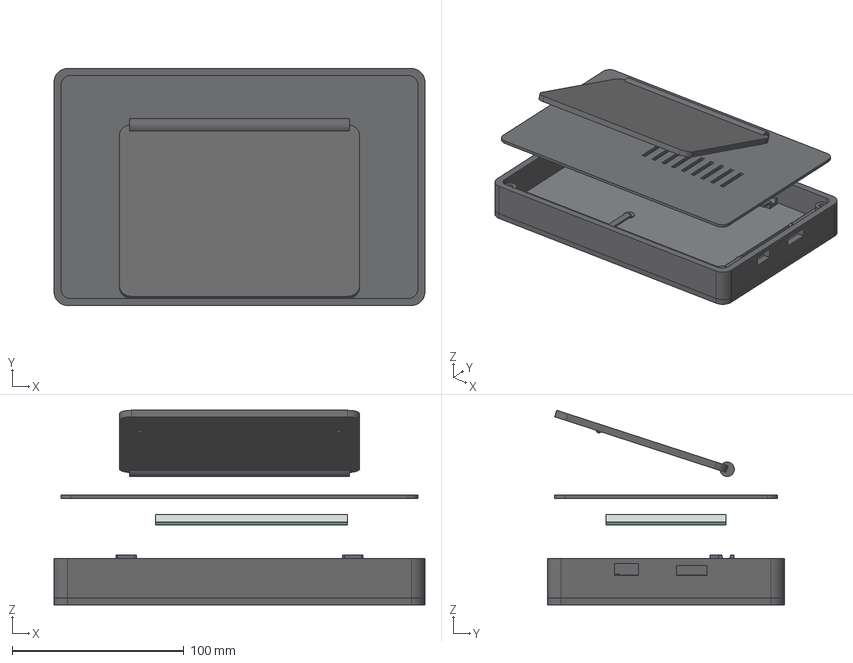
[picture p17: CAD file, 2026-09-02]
outcomes/digital-photo-frame/artifacts/cad/product_rear_cover_open_exploded.step
216.0 x 138.0 x 113.3 mm
front_bezel_with_display_ledge
rear_chassis_with_standoffs_and_hinge_stops
removable_service_cover
ER-TFTM070-4V3_documented_max_envelope
display_active_area_154p08x85p92
pcb_112x70x1p6
unverified_populated_component_envelope_4p5mm
folding_easel_stand_with_detents

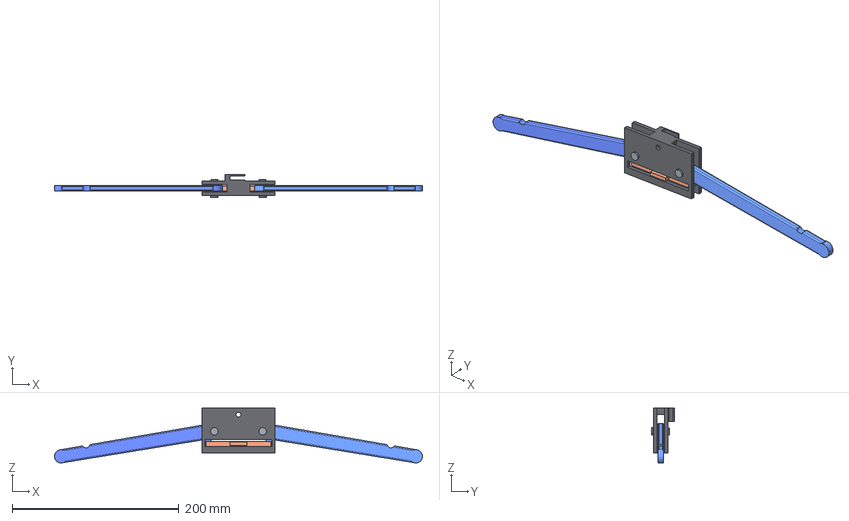
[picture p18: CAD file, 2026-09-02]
outcomes/fold-flat-travel-hanger/artifacts/cad/lock_engaged.step
442.0 x 27.5 x 66.0 mm
center_yoke
left_shoulder_arm
right_shoulder_arm
dual_positive_lock_bar
left_arm_pin
right_arm_pin
left_arm_locknut
right_arm_locknut

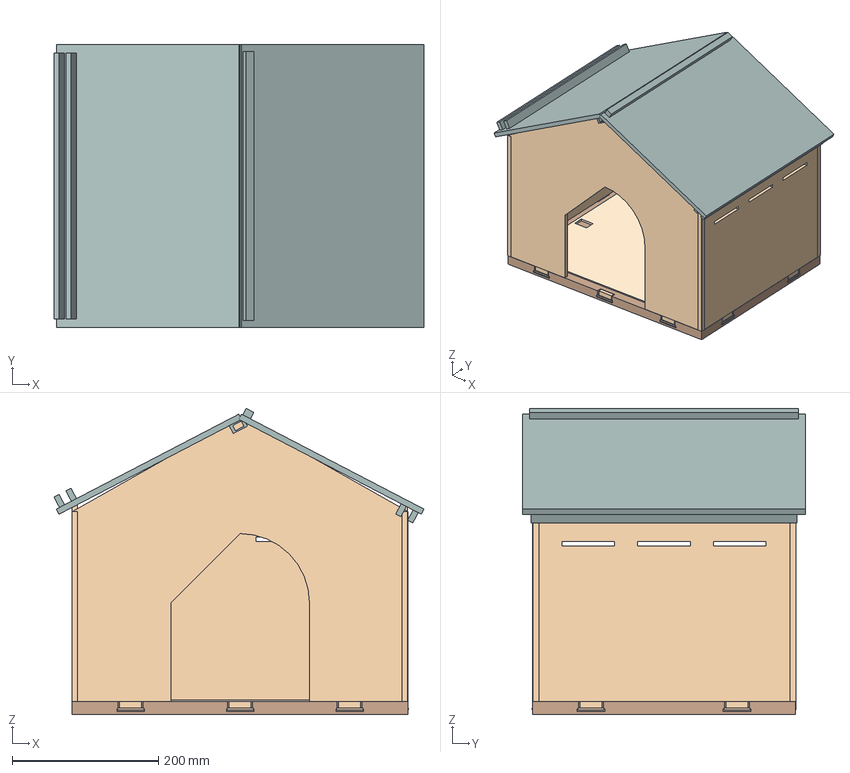
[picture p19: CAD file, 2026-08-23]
outcomes/functional-hardware-prototype/media/cat-shelter.step
506.8 x 388.0 x 419.5 mm
base_ballast_pan
ballast_cover_floor

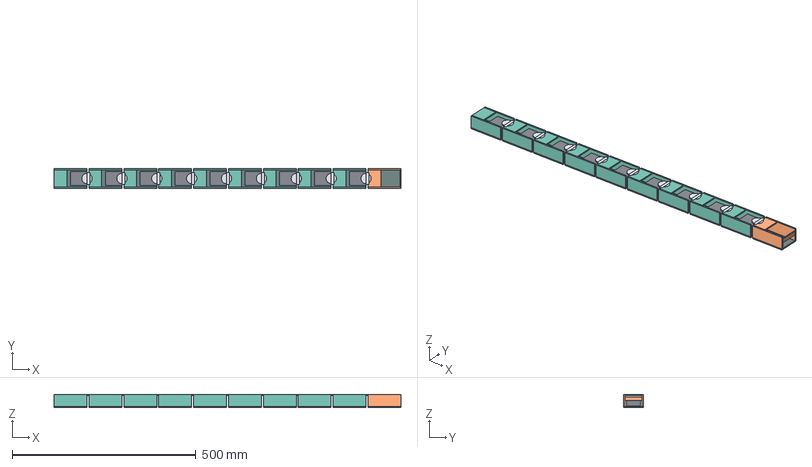
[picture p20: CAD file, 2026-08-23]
outcomes/robot-digital-prototype/media/robot-snake.step
945.0 x 55.0 x 35.0 mm
bottom_skid x 10
side_rail:left x 10
side_rail:right x 10
rear_deck x 10
trailing_yoke:joint_01
head_sensor_bar
range_sensor_window:head_range_m60
range_sensor_window:head_range_m30
range_sensor_window:head_range_00
range_sensor_window:head_range_p30
range_sensor_window:head_range_p60
st3215_reference_envelope:joint_01
servo_horn_reference:joint_01
trailing_yoke:joint_02
st3215_reference_envelope:joint_02
servo_horn_reference:joint_02
trailing_yoke:joint_03
st3215_reference_envelope:joint_03
servo_horn_reference:joint_03
trailing_yoke:joint_04
st3215_reference_envelope:joint_04
servo_horn_reference:joint_04
trailing_yoke:joint_05
st3215_reference_envelope:joint_05
servo_horn_reference:joint_05
trailing_yoke:joint_06
st3215_reference_envelope:joint_06
servo_horn_reference:joint_06
trailing_yoke:joint_07
st3215_reference_envelope:joint_07
servo_horn_reference:joint_07
trailing_yoke:joint_08
st3215_reference_envelope:joint_08
servo_horn_reference:joint_08
trailing_yoke:joint_09
st3215_reference_envelope:joint_09
servo_horn_reference:joint_09

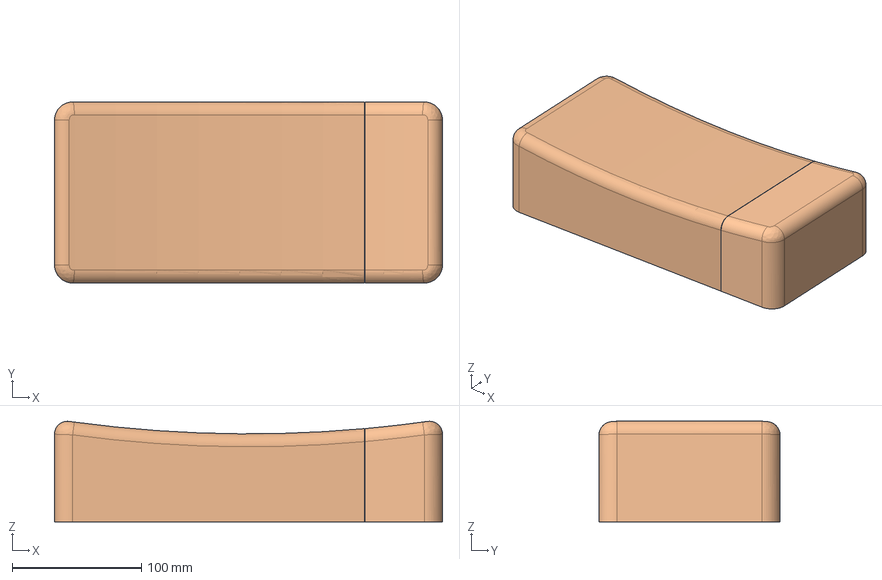
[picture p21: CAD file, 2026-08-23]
outcomes/split-vibrotactile-headrest-cad-package/artifacts/split_headrest_v2.step
300.0 x 140.0 x 77.7 mm
split_v2_primary_shell
split_v2_end_cap
split_v2_structural_service_panel
split_v2_petg_actuator_spine
split_v2_alignment_pin:rear
split_v2_alignment_pin:front
internal_accelerometer_coupon

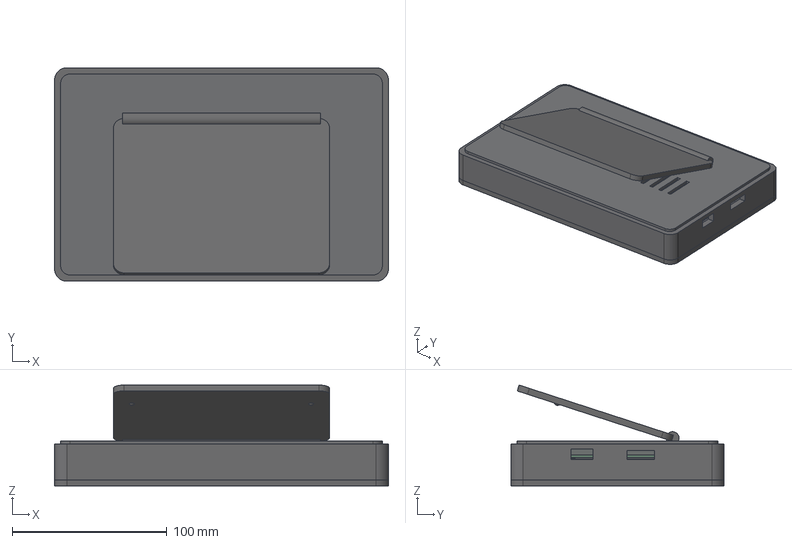
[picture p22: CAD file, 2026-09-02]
outcomes/digital-photo-frame/artifacts/cad/product_stand_deployed.step
216.0 x 138.0 x 65.3 mm
front_bezel_with_display_ledge
rear_chassis_with_standoffs_and_hinge_stops
removable_service_cover
ER-TFTM070-4V3_documented_max_envelope
display_active_area_154p08x85p92
pcb_112x70x1p6
unverified_populated_component_envelope_4p5mm
folding_easel_stand_with_detents

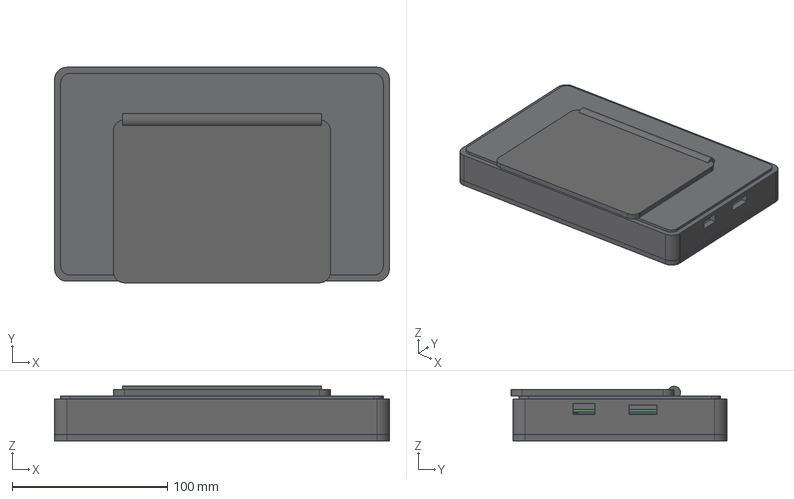
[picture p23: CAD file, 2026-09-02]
outcomes/digital-photo-frame/artifacts/cad/product_stand_folded.step
216.0 x 139.0 x 35.2 mm
front_bezel_with_display_ledge
rear_chassis_with_standoffs_and_hinge_stops
removable_service_cover
ER-TFTM070-4V3_documented_max_envelope
display_active_area_154p08x85p92
pcb_112x70x1p6
unverified_populated_component_envelope_4p5mm
folding_easel_stand_with_detents

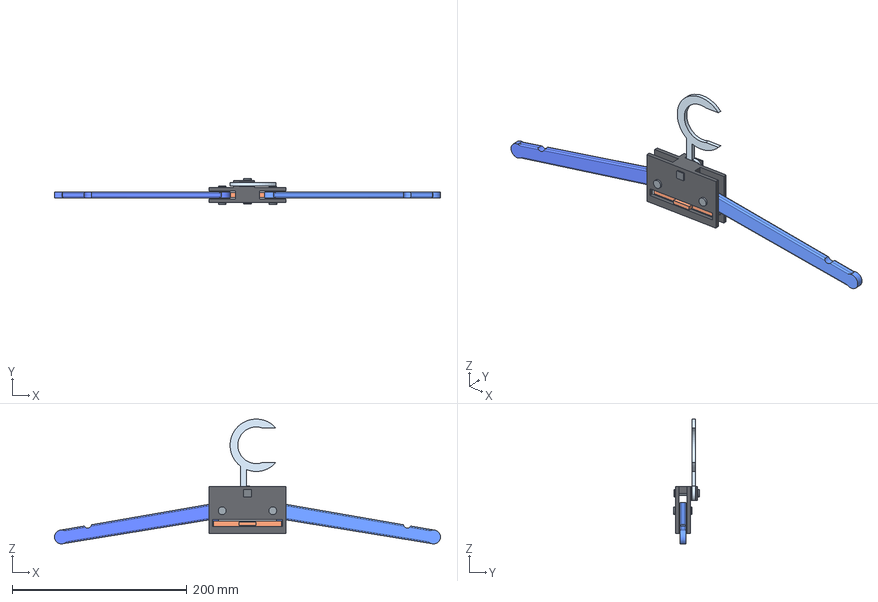
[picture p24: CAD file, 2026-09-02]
outcomes/fold-flat-travel-hanger/artifacts/cad/hanger_deployed.step
442.0 x 30.0 x 143.0 mm
center_yoke
left_shoulder_arm
right_shoulder_arm
folding_hook
dual_positive_lock_bar
left_arm_pin
right_arm_pin
hook_pin
left_arm_locknut
right_arm_locknut
hook_locknut

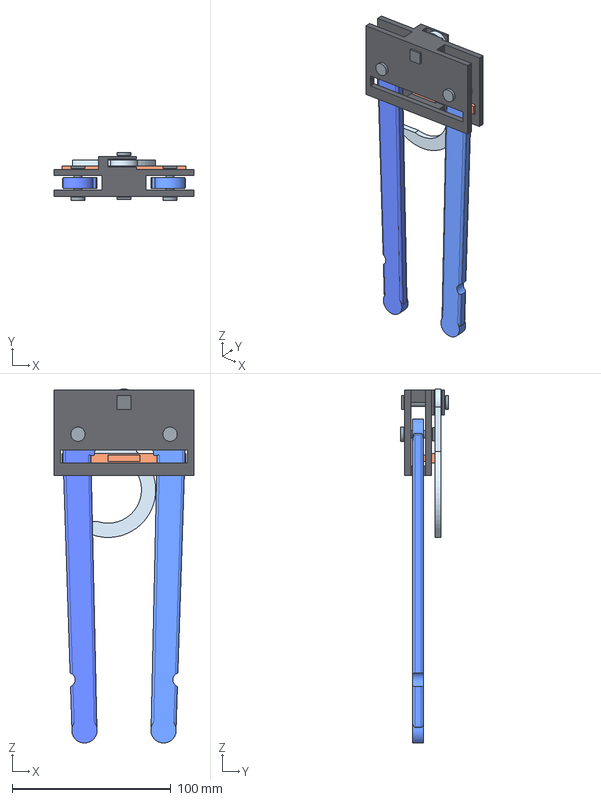
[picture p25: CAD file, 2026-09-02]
outcomes/fold-flat-travel-hanger/artifacts/cad/hanger_folded.step
88.0 x 30.0 x 222.9 mm
center_yoke
left_shoulder_arm
right_shoulder_arm
folding_hook
dual_positive_lock_bar
left_arm_pin
right_arm_pin
hook_pin
left_arm_locknut
right_arm_locknut
hook_locknut

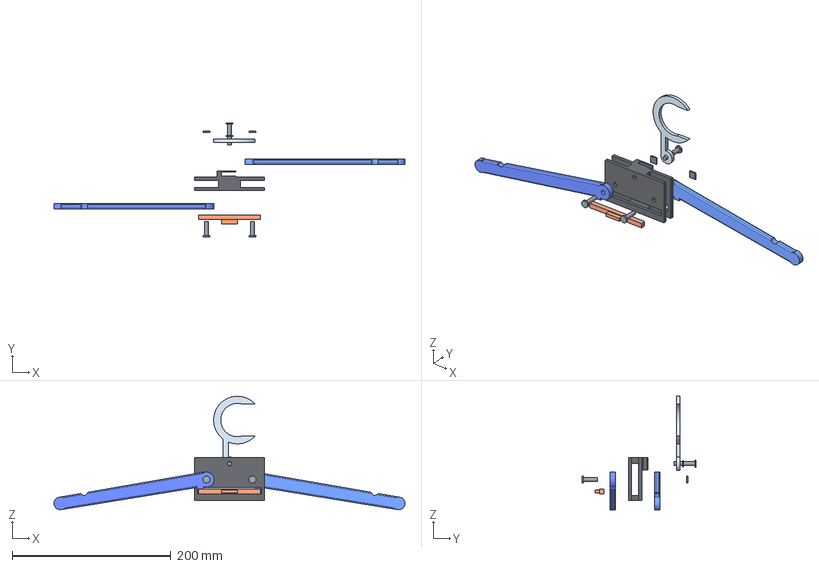
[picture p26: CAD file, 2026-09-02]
outcomes/fold-flat-travel-hanger/artifacts/cad/hanger_exploded.step
442.0 x 144.0 x 143.0 mm
center_yoke
left_shoulder_arm
right_shoulder_arm
folding_hook
dual_positive_lock_bar
left_arm_pin
right_arm_pin
hook_pin
left_arm_locknut
right_arm_locknut
hook_locknut

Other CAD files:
outcomes/fold-flat-travel-hanger/artifacts/cad/lock_released.step

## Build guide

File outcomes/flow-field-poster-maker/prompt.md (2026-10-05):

Make a generative flow-field poster maker as one self-contained index.html, no libraries. Thousands of particles follow a smooth noise field (write your own simplex or Perlin noise) and leave thin translucent trails that build up into an ink-like drawing on a portrait canvas in A-series proportions. Controls in a slim side panel: seed (with a shuffle button), particle count, noise scale, curl or swirl strength, line width, and a palette picker with about six good palettes (paper and ink, risograph, ocean, sunset, mono, neon on black). Drawing animates live and stops by itself after a few seconds. Add Redraw, and Export PNG at 3x resolution. Put the seed and parameters in the URL hash so a poster can be shared and reproduced exactly.

Looks great. Add a Contact Sheet button: it renders a 3x3 grid of small previews using the current settings with nine random seeds, and clicking one loads that seed full size. Also add an optional paper-grain texture toggle that is applied on top in the PNG export too.

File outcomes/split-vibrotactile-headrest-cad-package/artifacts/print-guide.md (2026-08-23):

# Full-size split V2 print and assembly guide

Status: printable geometry generated; slicing and physical retention remain
unverified

## Why the split is off-centre

The body remains `300 × 140 mm`, matching the original full-size concept. It
splits at `X = +90 mm`, producing:

| Part | Finished envelope | Fits a 256 mm square bed |
| --- | --- | --- |
| Primary shell | `239.85 × 140 × 77.75 mm` | Yes |
| End cap | `59.85 × 140 × 77.75 mm` | Yes |
| Structural service panel | `240 × 132 × 4 mm` | Yes |
| PETG actuator spine | `210 × 100 × 10 mm` | Yes |
| Alignment pin, two required | `Ø6 × 19.2 mm` | Yes |

The primary shell retains the centred head-contact and complete actuator
envelope. The seam is `90 mm` to the right of centre, outside the actuator tab
sweep and away from the main head-support area.

## How the two sections remain together

The seam is not held by glue alone:

1. Two `Ø6 × 19.2 mm` printed pins align the upper structure.
2. The one-piece `210 × 100 × 10 mm` PETG spine crosses the seam at the cavity
   ceiling. Four fasteners retain it to the primary shell and two retain it to
   the end cap.
3. The one-piece `240 × 132 × 4 mm` service panel crosses the seam below. Two
   panel fasteners retain the primary shell and two retain the end cap.
4. The nominal `0.30 mm` seam gap prevents printed faces from falsely appearing
   assembled when elephant foot or surface variation is present.

This is a redundant prototype retention concept. It is not yet proven under
vibration or head load.

## Print files

Prefer 3MF because it preserves units:

- `models/split_v2_primary_shell.3mf`
- `models/split_v2_end_cap.3mf`
- `models/split_v2_panel.3mf`
- `models/split_v2_spine.3mf`
- `models/split_v2_alignment_pin.3mf` — print two

Editable STEP and STL files are beside them.

## Before the full print

1. Slice the primary shell in the exact printer profile.
2. Compare normal and seam-face-down orientations; inspect supports, bed
   contact, bridge regions, and estimated mass.
3. Print an insert coupon and one alignment pin/hole coupon first.
4. Print the spine before the shell and verify all fastener clearances.
5. Do not print actuator holes until the received actuator is measured.

Starting material intent:

- PETG from one known batch;
- `0.20 mm` layer height;
- at least `5` perimeter walls for shell and panel;
- at least `6` perimeter walls for the structural spine;
- locally solid material around every insert, pin bore, and fastener;
- printer/filament manufacturer's PETG temperature profile; and
- slicer-generated supports only after overhang preview.

## Mechanical assembly order

1. Inspect and deburr the two seam faces without rounding their datum edges.
2. Prove the selected heat-set insert process on a matching coupon.
3. Install six spine inserts and four panel inserts using depth stops.
4. Dry-fit both alignment pins into the primary shell.
5. Mount the actuator to the removable spine after its real hole pattern is
   modeled and reprinted.
6. Bolt the spine to the primary shell at `X = -75/+60`, `Y = ±42`.
7. Slide the end cap over both alignment pins until the seam seats uniformly.
8. Bolt the spine to the end cap at `X = +100`, `Y = ±42`.
9. Complete the cable restraint and unpowered rattle inspection.
10. Fit the gasket and install the service panel at `X = ±105`, `Y = ±61`.
11. Apply witness marks and record every fastener before any energized test.

Do not use adhesive as the primary joint. Stop testing for any seam motion,
crack, whitening, heat deformation, shifted witness mark, or new rattle.

## External equipment

The Raspberry Pi, RØDE AI-1, power amplifier, and power supplies remain outside
the body. Only the actuator, passive cable, sensor, spine, fasteners, and strain
relief belong inside.

## What remains unknown

The files prove CAD bounds and topology only. They do not prove slicer support
strategy, print quality, insert retention, seam comfort, received actuator fit,
load capacity, vibration retention, temperature, or human-use suitability.

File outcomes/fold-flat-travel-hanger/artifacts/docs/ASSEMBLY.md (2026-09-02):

# Assembly and operating note

1. Place the lock bar through the 8 mm guide passage from the rear. Fit the two compression springs over its guide pegs before seating it at the engaged position.
2. Place each named shoulder arm between the yoke cheek plates. Align the 5.6 mm bores, insert the M5 shoulder screws from the rear, and secure the low-profile locknuts without clamping away the specified axial running clearance.
3. Place the hook between its front-layer clevis plates, insert the long shoulder screw from the front of that clevis and through the main front cheek, and secure its locknut behind the rear cheek.
4. Confirm that the rigid lock ears sit directly below both arm heels with 6 mm overlap. The orange lock bar must be visually inspectable through the side and rear openings.
5. To fold, remove garment load, press the recessed thumb pad forward by 7.5 mm, and rotate both arms downward. The cheek plates keep fingertips outside the root sweep. Fold the hook downward in its separate front layer.
6. The intended light folded retention is supplied by spring pressure from the released lock bar against the arm-root side faces and the nested geometry. This is a low-load luggage retention feature only; its holding force requires a physical prototype measurement.

The deployed downward load path is: garment → deep shoulder beam → solid heel → 6 mm rigid lock-ear face → linked lock bar → yoke side rails. The thumb pad is recessed and outside the vertical contact patch; it is not a flexible snap or thin release tab. Normal downward or inward clothing load does not translate the bar along Y.

The digital model reserves the spring path but omits deformable coil geometry. Springs must be selected after measuring prototype release force and available solid height.

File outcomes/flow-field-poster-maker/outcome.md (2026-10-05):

# Flow-Field Poster Maker

Thousands of particles follow a smooth noise field and leave thin translucent trails that build up into ink-like posters in A-series proportions. Six palettes (paper and ink, risograph, ocean, sunset, mono, neon), sliders for particle count, noise scale, swirl and line width, and a contact sheet of nine random seeds you can click to open. Every poster is reproducible from its URL, and the PNG export renders at 3x. One self-contained index.html with hand-written noise and no libraries.

## How it was made

An AI agent made this. Claude Code, running Claude Opus 5.5, built it in one recorded session from the two prompts in this recipe. Nobody edited the code by hand. Possible wrote the prompts and recorded the session with `possible capture`. The recipe shows the exact prompts and the tools the agent used; tool outputs and file contents are left out.

## Try it

Open the generated `index.html` in a browser, or copy the recipe into your own agent and compare. Results vary between runs and models.

## What to know

The agent did not run or test the page during the session (it had file tools only). Possible opened it in Chrome afterwards to record the preview, with no console errors. PNG export and the shareable URL were not checked in the recording.

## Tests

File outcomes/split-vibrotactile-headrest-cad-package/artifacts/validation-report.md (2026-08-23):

# Full-size split V2 local CAD validation

Validated: 2026-07-29

## Native inspection

All artifacts were generated from Python sources with the repo-local CAD
tooling. Native STEP inspection returned no errors or warnings.

| File | Kind | Bounds (mm) |
| --- | --- | --- |
| `models/split_headrest_v2.step` | engineering assembly | `300 × 140 × 77.75` |
| `models/split_v2_primary_shell.step` | printable part | `239.85 × 140 × 77.748` |
| `models/split_v2_end_cap.step` | printable part | `59.85 × 140 × 77.7479` |
| `models/split_v2_panel.step` | printable part | `240 × 132 × 4` |
| `models/split_v2_spine.step` | printable part | `210 × 100 × 10` |
| `models/split_v2_alignment_pin.step` | printable part | `Ø6 × 19.2` |

Every individual printable X/Y envelope is below `256 × 256 mm`. The assembled
body returns to the original `300 × 140 mm` footprint.

## Deterministic joint checks

`npm run check:v2` verifies:

- the primary and end-cap split planes preserve the nominal `0.30 mm` gap;
- each shell section remains one connected solid;
- the actuator spine crosses the seam and has retained fasteners on both sides;
- the service panel crosses the seam and has retained fasteners on both sides;
- the alignment pin has `0.40 mm` nominal diametric clearance;
- the seam remains beyond the nominal actuator tab envelope;
- the oriented actuator fits the spine width; and
- the actuator envelope clears the installed service panel.

## Visual review

- installed body:
  `workstreams/mechanical/snapshots/split-v2-body-iso_*.png`
- top seam position:
  `workstreams/mechanical/snapshots/split-v2-body-top_*.png`
- panel-hidden internal joint:
  `workstreams/mechanical/snapshots/split-v2-engineering-open_*.png`
- exploded assembly:
  `workstreams/mechanical/snapshots/split-v2-engineering-exploded_*.png`

Visual review confirms that the seam sits near the right end rather than under
the centred actuator. The internal spine and underside panel visibly overlap
both shell sections.

## Boundary

This validates source generation, topology, placement, and printer-bed
envelopes. It does not validate slicing, physical printing, insert installation,
seam feel, received-part fit, load capacity, vibration retention, temperature,
or human use.

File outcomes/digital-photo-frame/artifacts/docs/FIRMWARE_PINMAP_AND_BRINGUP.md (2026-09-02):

# Firmware pin map and bring-up requirements

Target module: ESP32-S3-WROOM-1-N16R8 (16 MB flash, 8 MB octal PSRAM).

| Function | ESP32-S3 signal |
|---|---|
| microSD CS / MISO / MOSI / SCK / card detect | GPIO4 / 5 / 6 / 7 / 15 |
| Previous / next / menu-wake buttons | GPIO16 / 17 / 18 |
| Status LED | GPIO8 |
| Ambient sensor interrupt / SCL / SDA | GPIO3 / 9 / 10 |
| Display backlight PWM / TE / reset | GPIO11 / 12 / 13 |
| Display CS / D-C / WR / RD | GPIO14 / 21 / 47 / 48 |
| Display DB0..DB7 | GPIO35..GPIO42 |
| Native USB | GPIO19 D- / GPIO20 D+ (module pins USB_D-/USB_D+) |
| UART0 | U0RXD / U0TXD |
| Boot / enable | GPIO0 / EN |

GPIO45 is pulled low for 3.3 V VDD_SPI selection and GPIO46 is pulled low for
normal boot. GPIO0 and EN are pulled high and each has a service button to
ground. Firmware must not repurpose these strap pins.

## Required staged bring-up

1. With display and microSD disconnected, current-limit the certified 5 V
   supply and verify +5V_RAW, protected +5V and +3V3 for shorts, ripple and
   startup sequencing.
2. Confirm TPS62132 switch-node waveform, converter temperature and load-step
   response before enabling Wi-Fi peaks.
3. Validate native USB and UART recovery paths, then confirm boot strapping from
   cold start and reset.
4. Probe all eight display data lines plus CS, D/C, RD, WR, RESET, TE and BL at
   the labelled connector/test points. Start with backlight disabled.
5. Confirm the exact ER-TFTM070-4V3 ordered configuration, interface-mode
   straps, 3.3 V logic acceptance, reset polarity, backlight PWM polarity and
   SSD1963 initialization before writing a framebuffer.
6. Exercise PSRAM and both framebuffer buffers under simultaneous Wi-Fi load.
7. Validate microSD insertion detect, card power transients and sustained writes.
8. Calibrate LTR-303ALS-01 brightness mapping and apply rate limits/hysteresis.
9. Verify button polarity/debounce and ensure the rear-facing status LED cannot
   leak through the display stack.
10. Measure worst-case total input current, display inrush, radio stability,
    enclosure temperatures and connector accessibility in the assembled unit.

Production firmware, OTA security policy, photo-transfer protocol, filesystem
recovery and display colour calibration are out of scope.

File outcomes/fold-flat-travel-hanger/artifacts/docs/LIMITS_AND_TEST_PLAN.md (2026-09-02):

# Digital limits and physical test plan

This package is a digital pre-build geometry concept. It does not validate a 3 kg load rating, strength, fatigue life, creep, impact resistance, latch reliability, print quality, dimensional accuracy, spring selection or garment safety.

Before use with garments, fabricate controlled prototypes and perform:

1. Progressive static load testing at the hook and both shoulders, instrumenting permanent set and lock movement.
2. Asymmetric one-arm loading on left and right arms.
3. Repeated folding and locking cycles through the intended service-life target.
4. Lock-release force measurement and accidental-release testing under symmetric, asymmetric, inward and jostling loads.
5. Hinge wear, shoulder-screw torque and pin-retention testing.
6. Folded-state drop testing from luggage-handling heights and orientations.
7. Warm-environment creep testing at the intended polymer's worst expected service temperature.
8. Pinch-point inspection throughout motion with representative adult fingers and gloves.
9. Garment-contact edge, snag and strap-notch inspection on representative fabrics.
10. Print-orientation, layer-adhesion and dimensional-capability coupons before committing to the final prototype process.

A structural analyst must define material, print process, load cases and safety factors before any load-rating claim.

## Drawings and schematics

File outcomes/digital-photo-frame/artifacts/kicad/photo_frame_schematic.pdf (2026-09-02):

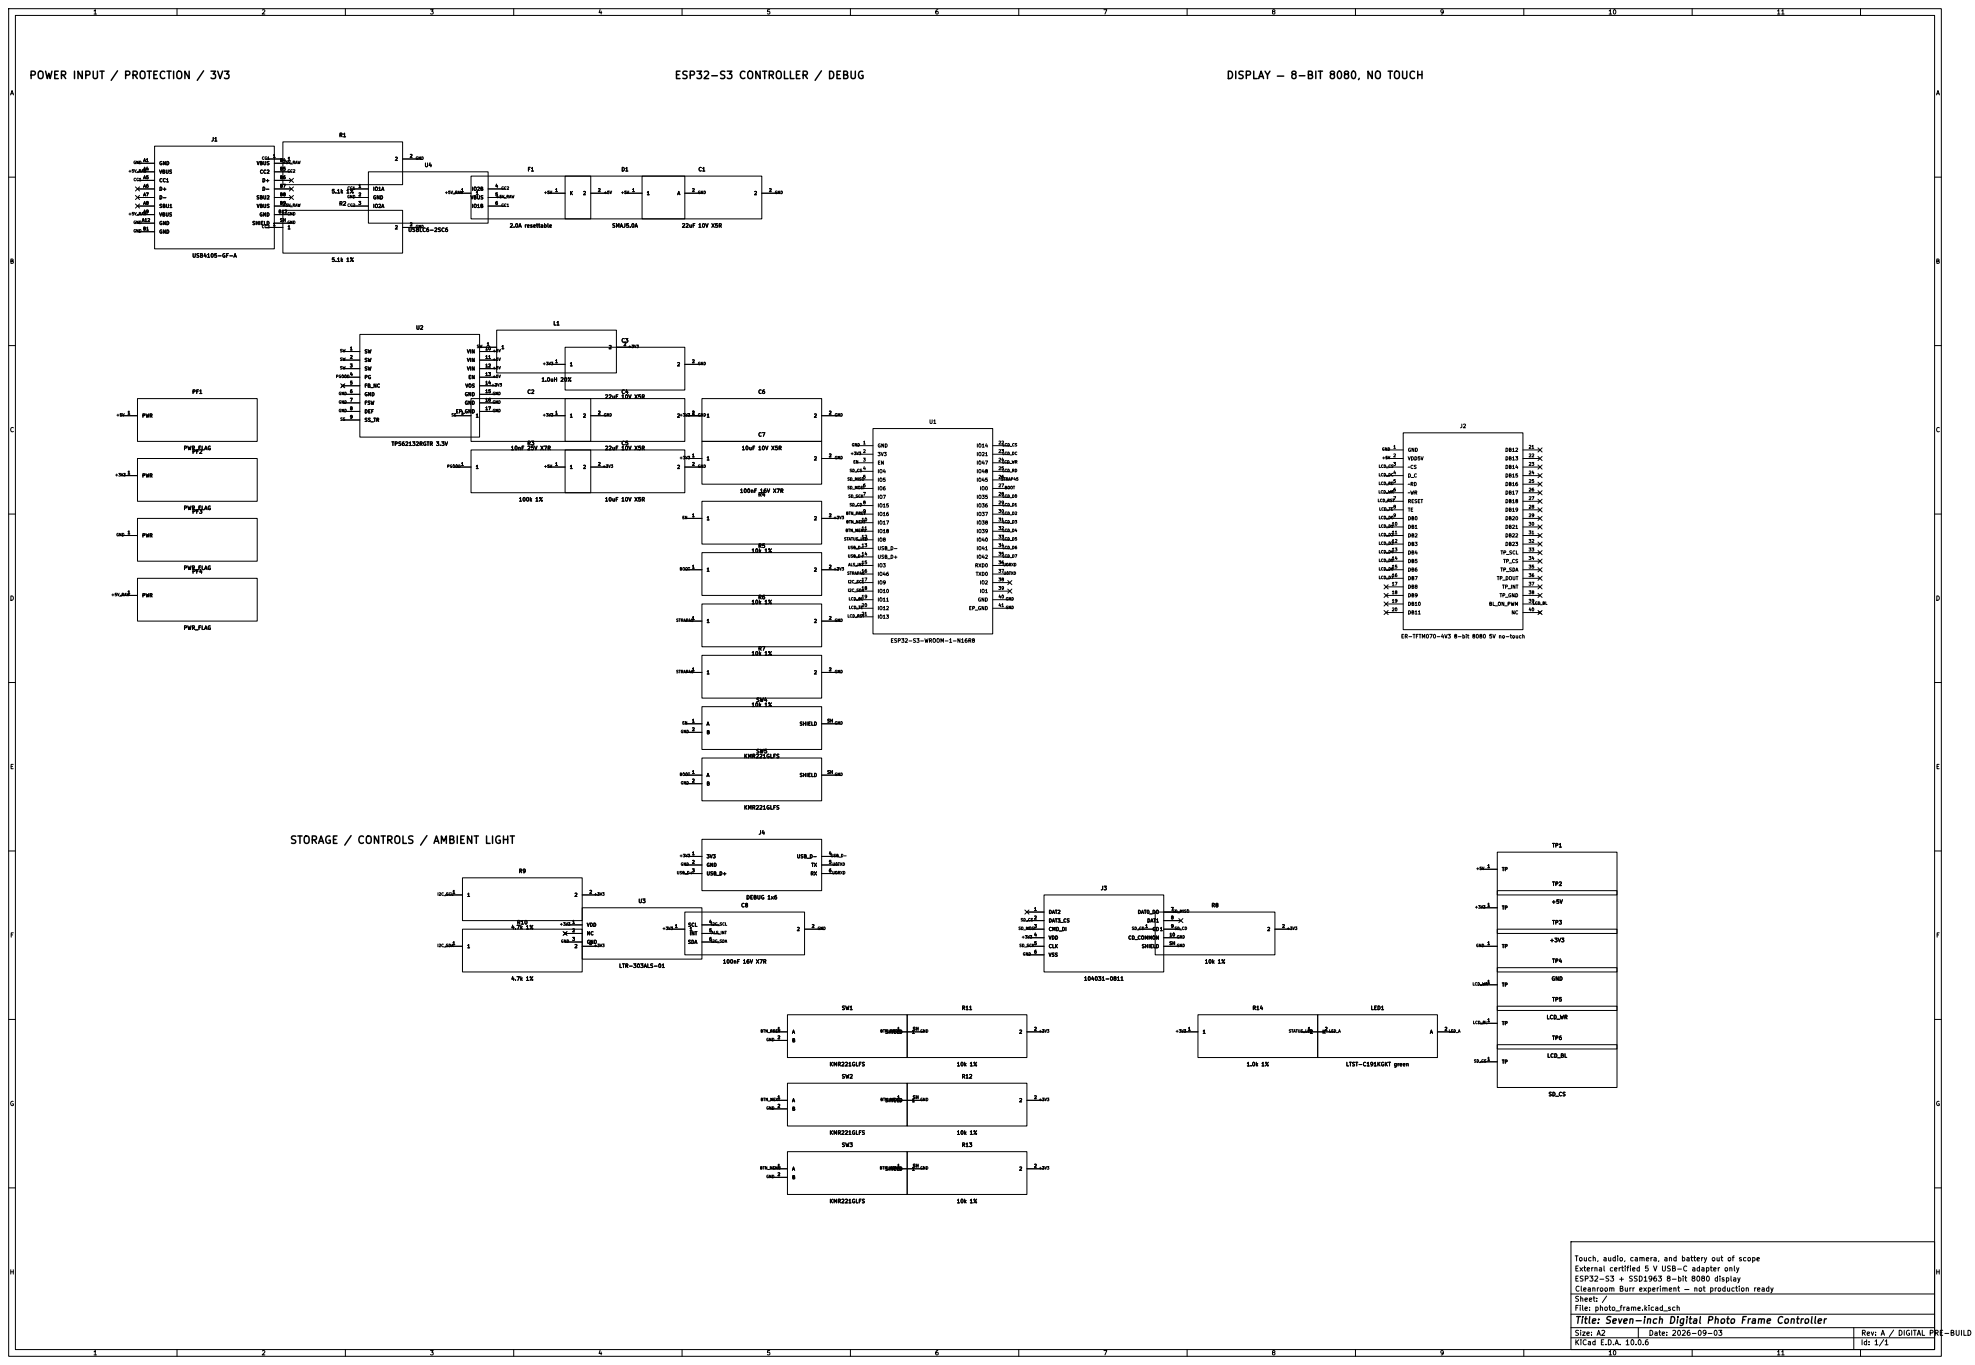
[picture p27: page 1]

ER-TFTM070-4V3 8-bit 8080 5V no-touch

STORAGE / CONTROLS / AMBIENT LIGHT

Touch, audio, camera, and battery out of scope
External certified 5 V USB-C adapter only
ESP32-S3 + SSD1963 8-bit 8080 display
Cleanroom Burr experiment — not production ready
Sheet: /
File: photo_frame.kicad_sch
Title: Seven-inch Digital Photo Frame Controller
KiCad E.D.A. 10.0.6

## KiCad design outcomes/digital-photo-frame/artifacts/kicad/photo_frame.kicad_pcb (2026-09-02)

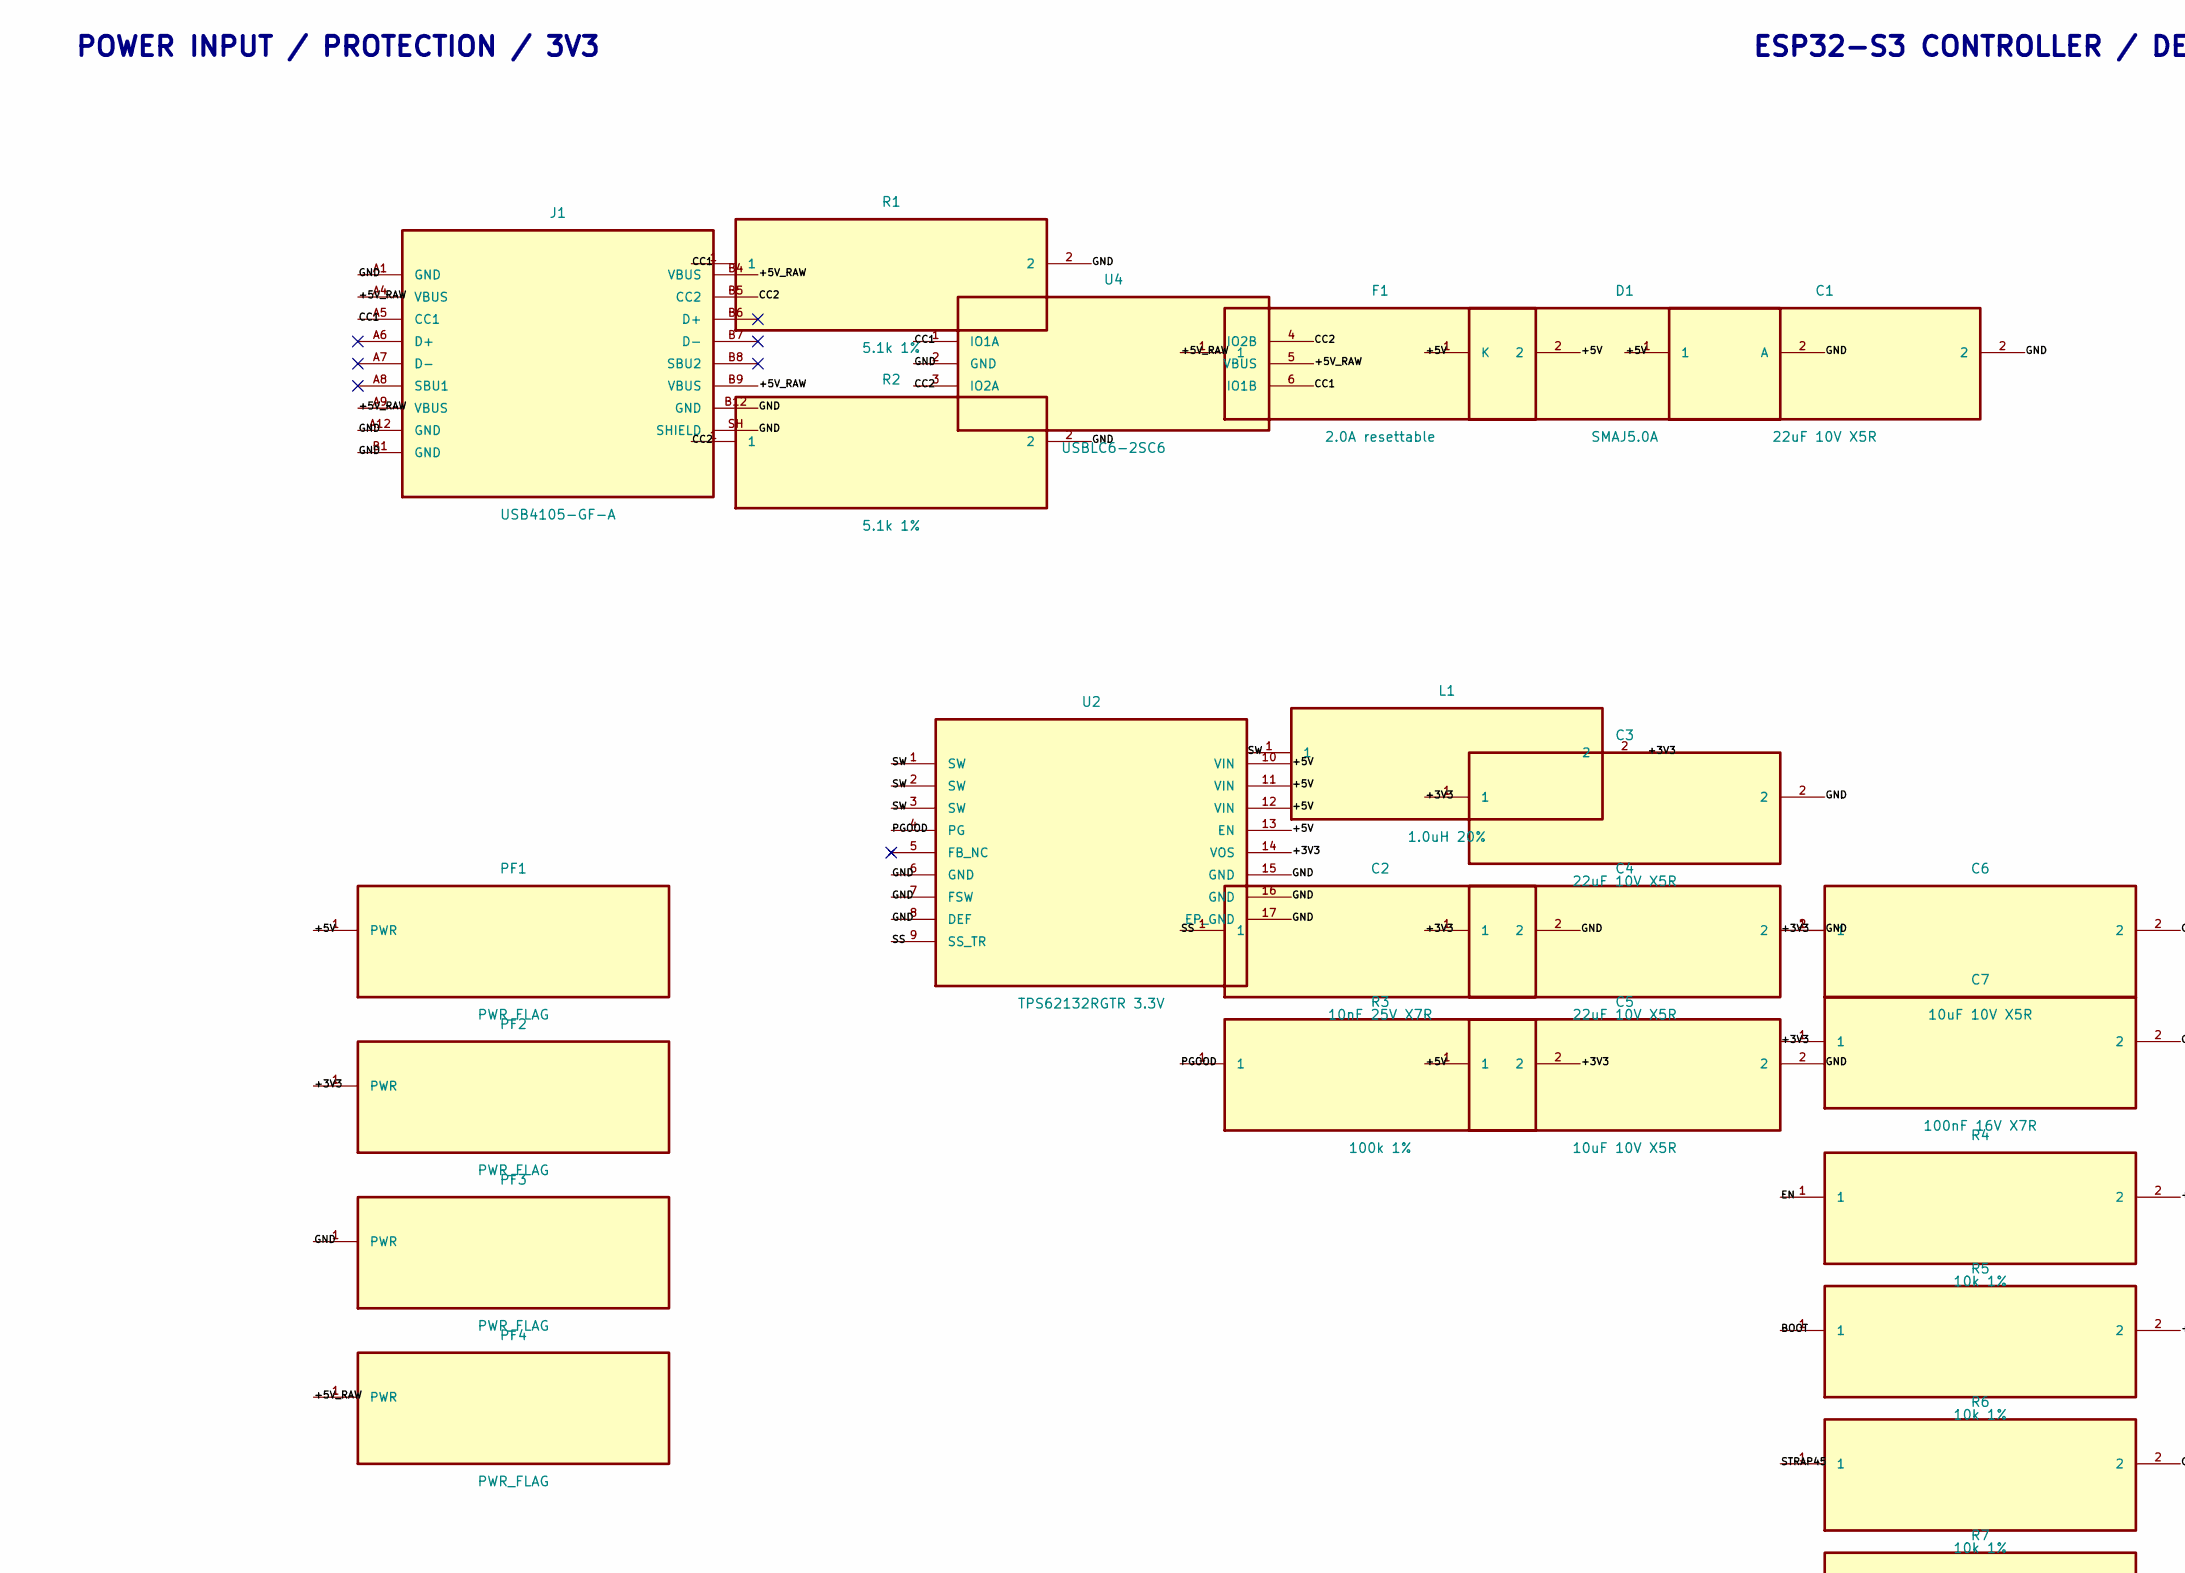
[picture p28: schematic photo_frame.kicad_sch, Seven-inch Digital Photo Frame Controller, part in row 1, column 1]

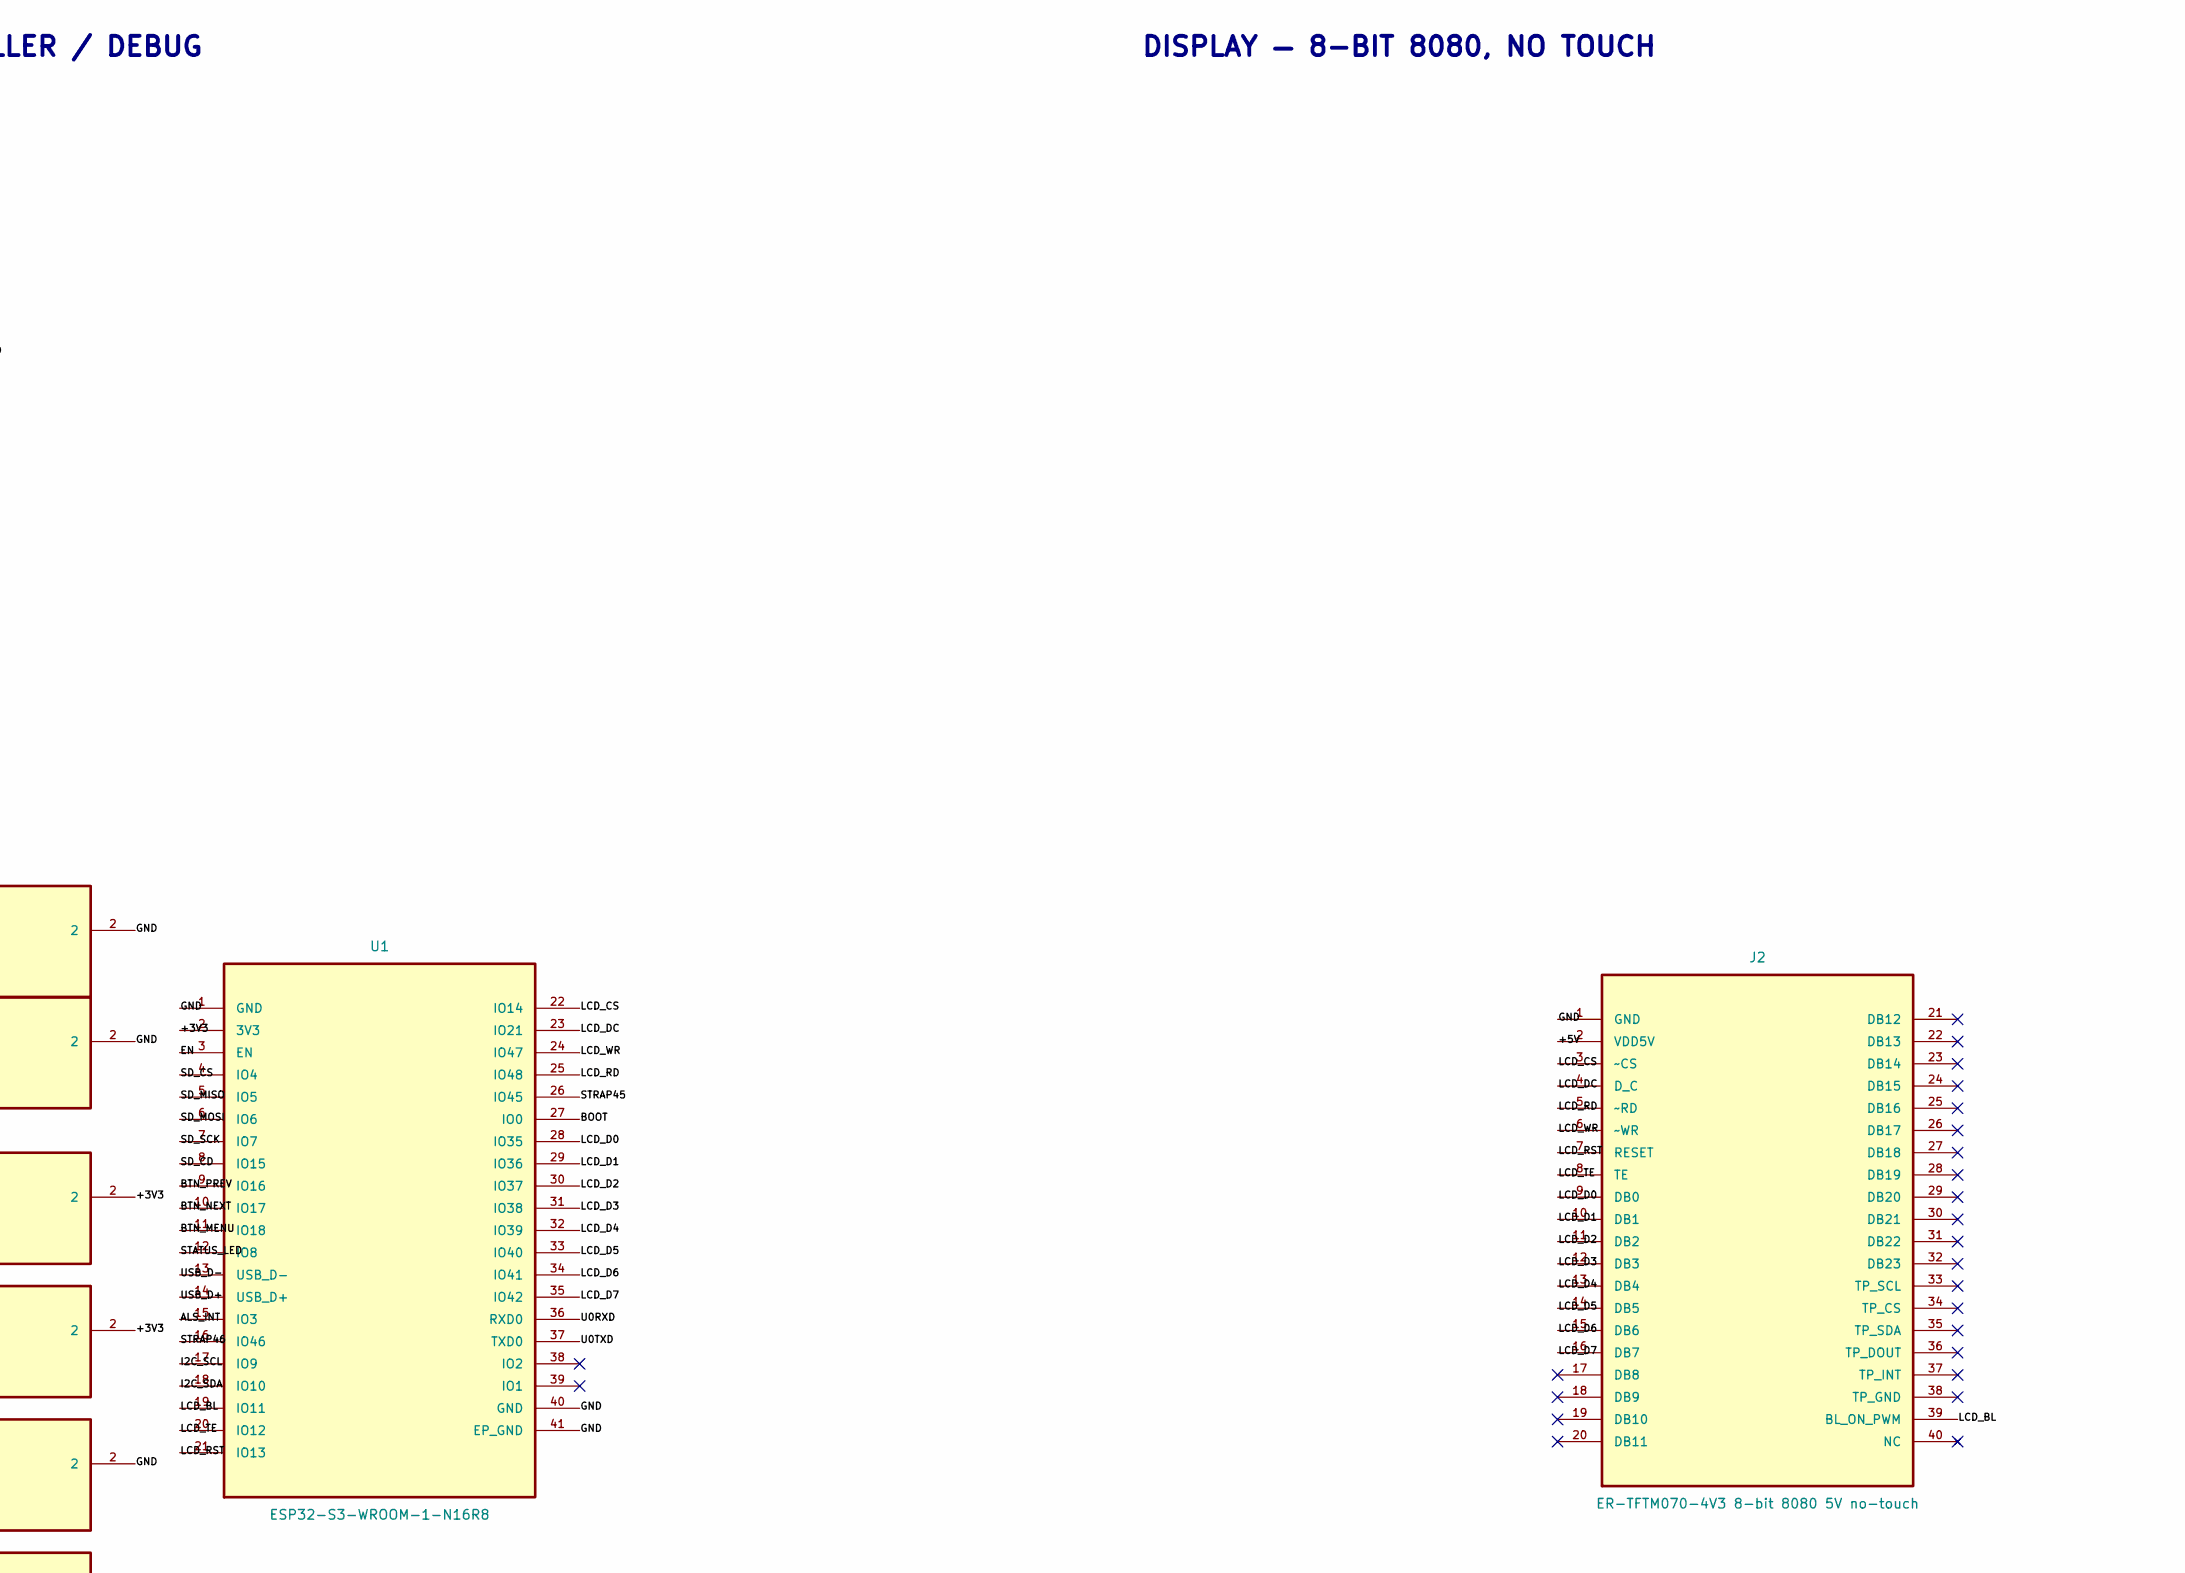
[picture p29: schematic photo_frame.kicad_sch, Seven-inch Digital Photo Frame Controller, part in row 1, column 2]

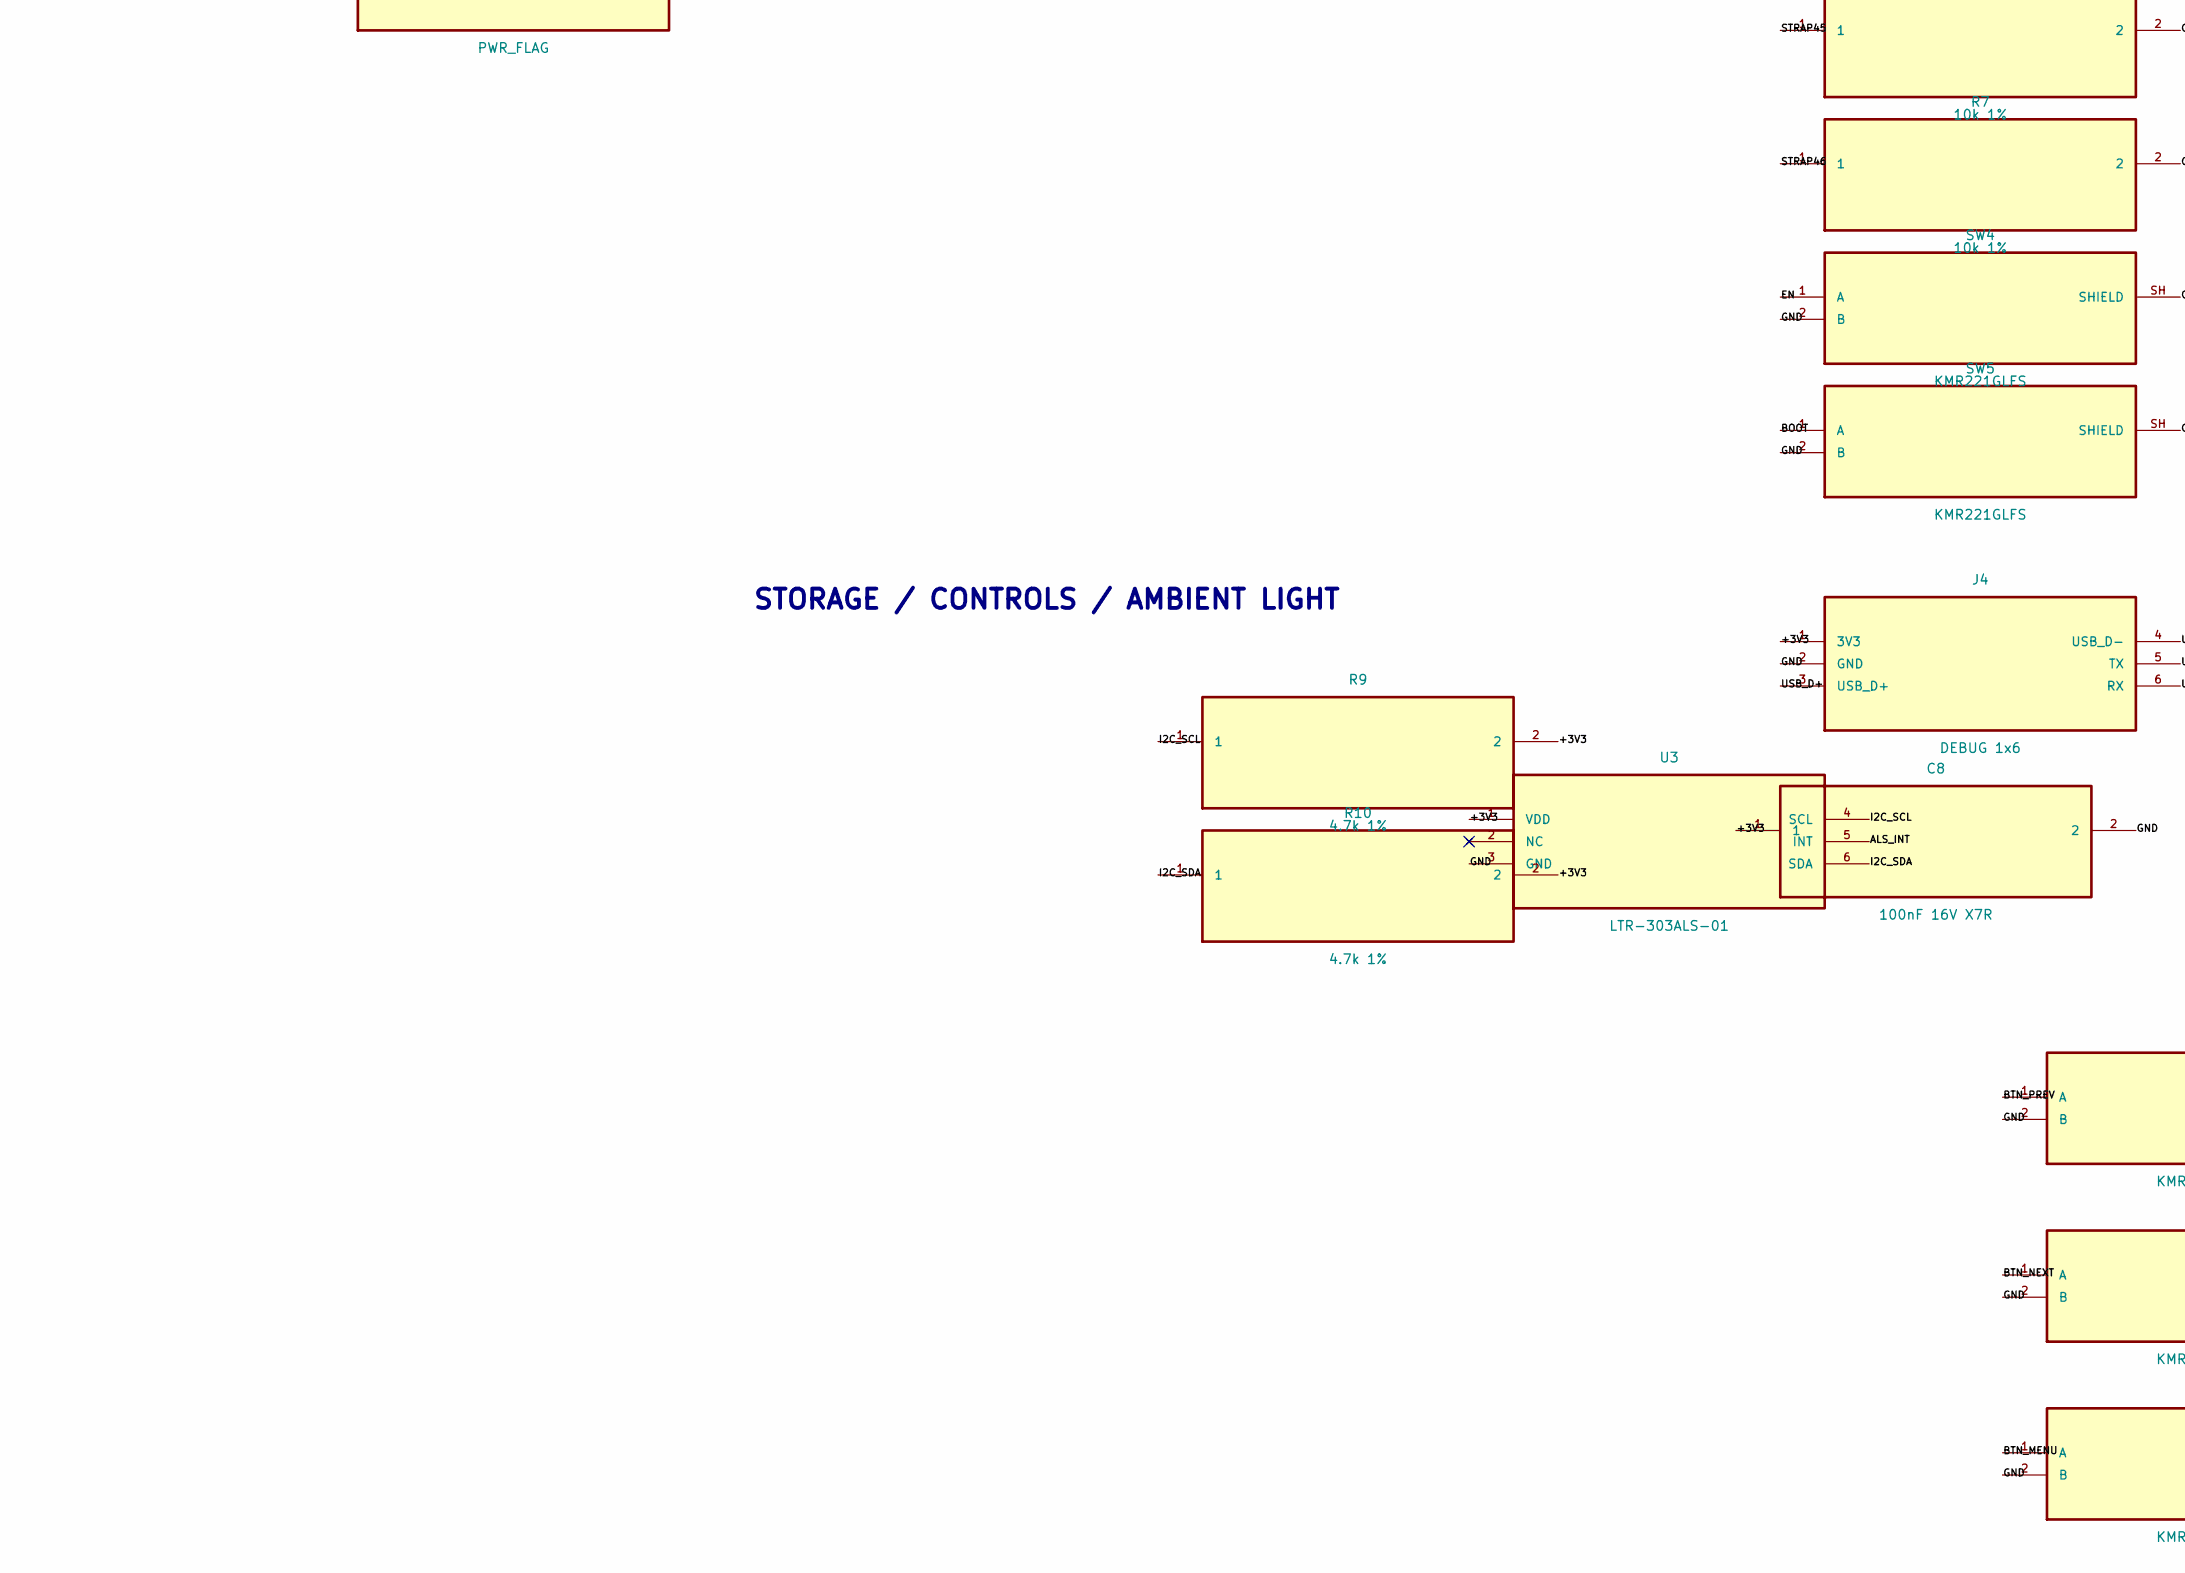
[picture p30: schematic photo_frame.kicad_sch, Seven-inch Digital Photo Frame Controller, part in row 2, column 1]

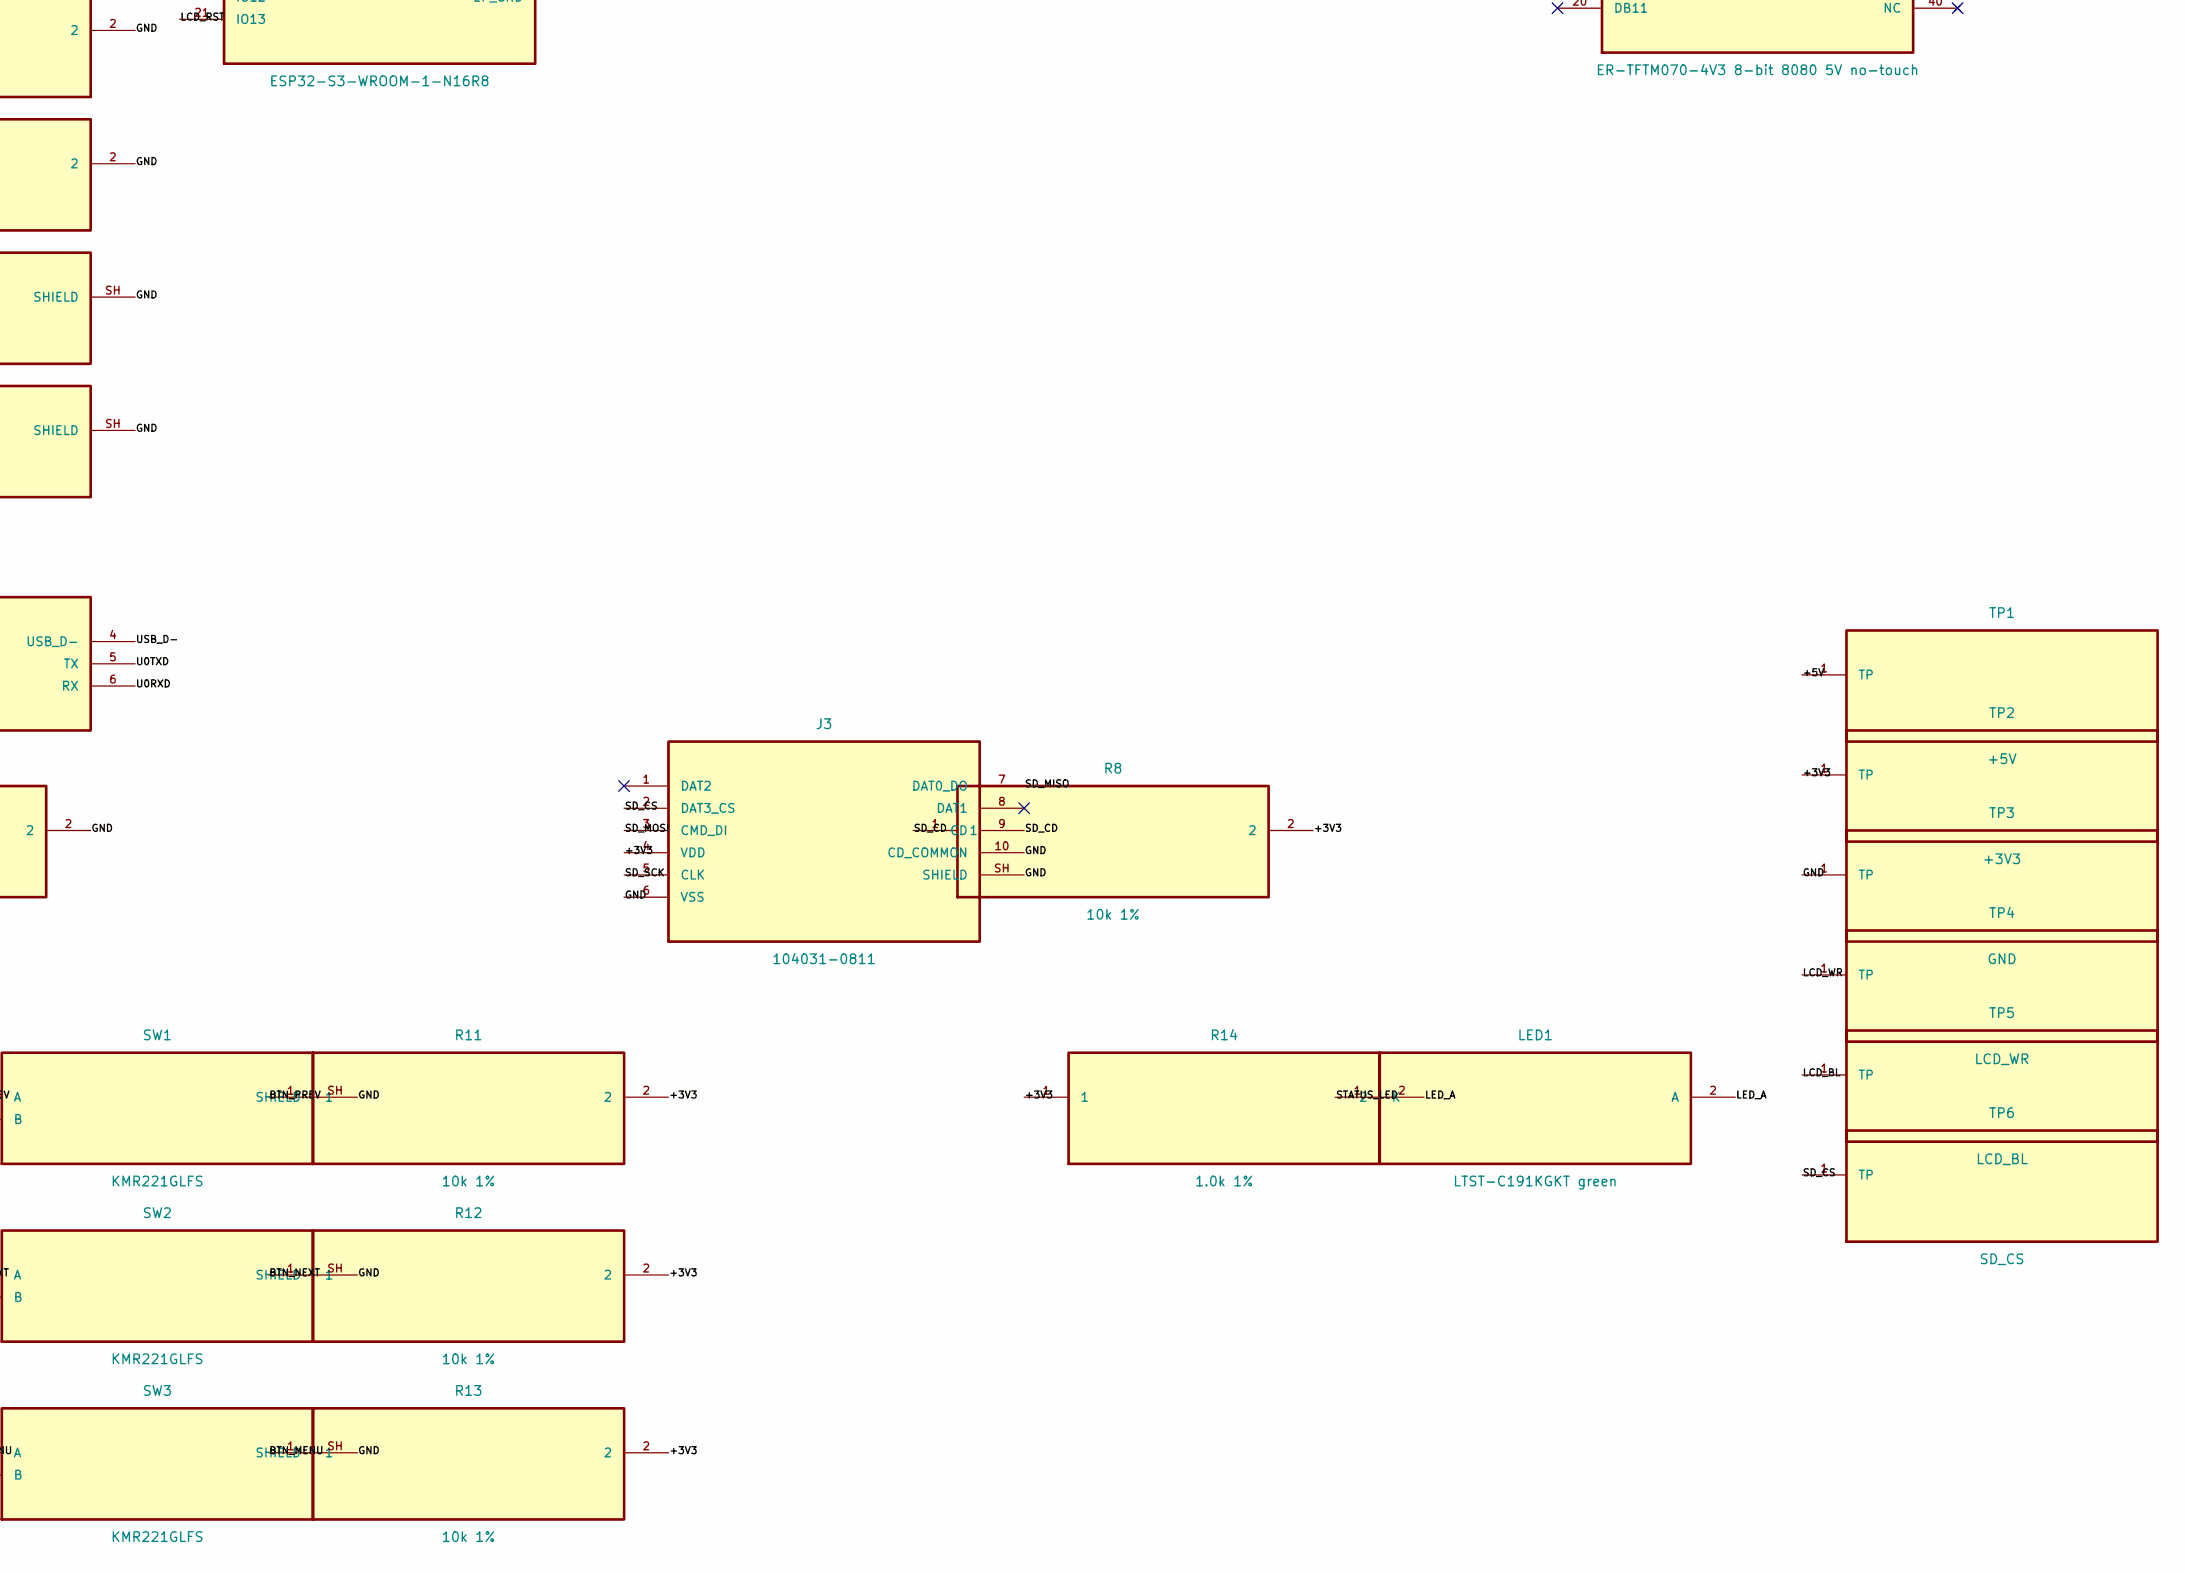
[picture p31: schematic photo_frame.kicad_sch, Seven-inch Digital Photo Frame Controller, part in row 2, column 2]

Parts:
C1, C3, C4: 22uF 10V X5R; C_0805_2012Metric; MPN GRM21BR61A226ME44L
C2: 10nF 25V X7R; C_0603_1608Metric; MPN GRM188R71E103KA01D
C5, C6: 10uF 10V X5R; C_0805_2012Metric; MPN GRM21BR61A106KE19L
C7, C8: 100nF 16V X7R; C_0603_1608Metric; MPN GRM188R71C104KA01D
D1: SMAJ5.0A; D_SMA; MPN SMAJ5.0A
F1: 2.0A resettable; Fuse_1206_3216Metric; MPN MF-MSMF200-2
J1: USB4105-GF-A; USB_C_Receptacle_GCT_USB4105-xx-A_16P_TopMnt_Horizontal; MPN USB4105-GF-A
J2: ER-TFTM070-4V3 8-bit 8080 5V no-touch; PinHeader_2x20_P2.54mm_Vertical; MPN ER-TFTM070-4V3
J3: 104031-0811; microSD_HC_Molex_104031-0811; MPN 104031-0811
J4: DEBUG 1x6; PinHeader_1x06_P2.54mm_Vertical; MPN M20-9990646
L1: 1.0uH 20%; L_Bourns-SRU8028_8.0x8.0mm; MPN XAL4020-102MEC
LED1: LTST-C191KGKT green; LED_0603_1608Metric; MPN LTST-C191KGKT
PF1, PF2, PF3, PF4: PWR_FLAG
R1, R2: 5.1k 1%; R_0603_1608Metric; MPN RC0603FR-075K1L
R3: 100k 1%; R_0603_1608Metric; MPN RC0603FR-07100KL
R4, R5, R6, R7, R8, R11, R12, R13: 10k 1%; R_0603_1608Metric; MPN RC0603FR-0710KL
R9, R10: 4.7k 1%; R_0603_1608Metric; MPN RC0603FR-074K7L
R14: 1.0k 1%; R_0603_1608Metric; MPN RC0603FR-071KL
SW1, SW2, SW3, SW4, SW5: KMR221GLFS; SW_Push_1P1T-SH_NO_CK_KMR2xxG; MPN KMR221GLFS
TP1: +5V; TestPoint_Pad_D1.5mm; MPN 5015
TP2: +3V3; TestPoint_Pad_D1.5mm; MPN 5015
TP3: GND; TestPoint_Pad_D1.5mm; MPN 5015
TP4: LCD_WR; TestPoint_Pad_D1.5mm; MPN 5015
TP5: LCD_BL; TestPoint_Pad_D1.5mm; MPN 5015
TP6: SD_CS; TestPoint_Pad_D1.5mm; MPN 5015
U1: ESP32-S3-WROOM-1-N16R8; ESP32-S3-WROOM-1; MPN ESP32-S3-WROOM-1-N16R8
U2: TPS62132RGTR 3.3V; VQFN-16-1EP_3x3mm_P0.5mm_EP1.68x1.68mm_ThermalVias; MPN TPS62132RGTR
U3: LTR-303ALS-01; Lite-On_LTR-303ALS-01; MPN LTR-303ALS-01
U4: USBLC6-2SC6; SOT-23-6; MPN USBLC6-2SC6

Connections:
+3V3: C3.1, C4.1, C6.1, C7.1, C8.1, J3.4 (VDD), J4.1 (3V3), L1.2, PF2.1, R3.2, R4.2, R5.2, R8.2, R9.2, R10.2, R11.2, R12.2, R13.2, R14.1, TP2.1, U1.2 (3V3), U2.14 (VOS), U3.1 (VDD)
+5V: C1.1, C5.1, D1.1 (K), F1.2, J2.2 (VDD5V), PF1.1, TP1.1, U2.10 (VIN), U2.11 (VIN), U2.12 (VIN), U2.13 (EN)
+5V_RAW: F1.1, J1.A4 (VBUS), J1.A9 (VBUS), J1.B4 (VBUS), J1.B9 (VBUS), PF4.1, U4.5 (VBUS)
ALS_INT: U1.15 (IO3), U3.5 (INT)
BOOT: R5.1, SW5.1 (A), U1.27 (IO0)
BTN_MENU: R13.1, SW3.1 (A), U1.11 (IO18)
BTN_NEXT: R12.1, SW2.1 (A), U1.10 (IO17)
BTN_PREV: R11.1, SW1.1 (A), U1.9 (IO16)
CC1: J1.A5 (CC1), R1.1, U4.1 (IO1A), U4.6 (IO1B)
CC2: J1.B5 (CC2), R2.1, U4.3 (IO2A), U4.4 (IO2B)
EN: R4.1, SW4.1 (A), U1.3 (EN)
GND: C1.2, C2.2, C3.2, C4.2, C5.2, C6.2, C7.2, C8.2, D1.2 (A), J1.A1 (GND), J1.A12 (GND), J1.B1 (GND), J1.B12 (GND), J1.SH (SHIELD), J2.1 (GND), J3.6 (VSS), J3.10 (CD_COMMON), J3.SH (SHIELD), J4.2 (GND), PF3.1, R1.2, R2.2, R6.2, R7.2, SW1.2 (B), SW1.SH (SHIELD), SW2.2 (B), SW2.SH (SHIELD), SW3.2 (B), SW3.SH (SHIELD), SW4.2 (B), SW4.SH (SHIELD), SW5.2 (B), SW5.SH (SHIELD), TP3.1, U1.1 (GND), U1.40 (GND), U1.41 (EP_GND), U2.6 (GND), U2.7 (FSW), U2.8 (DEF), U2.15 (GND), U2.16 (GND), U2.17 (EP_GND), U3.3 (GND), U4.2 (GND)
I2C_SCL: R9.1, U1.17 (IO9), U3.4 (SCL)
I2C_SDA: R10.1, U1.18 (IO10), U3.6 (SDA)
LCD_BL: J2.39 (BL_ON_PWM), TP5.1, U1.19 (IO11)
LCD_CS: J2.3 (~CS), U1.22 (IO14)
LCD_D0: J2.9 (DB0), U1.28 (IO35)
LCD_D1: J2.10 (DB1), U1.29 (IO36)
LCD_D2: J2.11 (DB2), U1.30 (IO37)
LCD_D3: J2.12 (DB3), U1.31 (IO38)
LCD_D4: J2.13 (DB4), U1.32 (IO39)
LCD_D5: J2.14 (DB5), U1.33 (IO40)
LCD_D6: J2.15 (DB6), U1.34 (IO41)
LCD_D7: J2.16 (DB7), U1.35 (IO42)
LCD_DC: J2.4 (D_C), U1.23 (IO21)
LCD_RD: J2.5 (~RD), U1.25 (IO48)
LCD_RST: J2.7 (RESET), U1.21 (IO13)
LCD_TE: J2.8 (TE), U1.20 (IO12)
LCD_WR: J2.6 (~WR), TP4.1, U1.24 (IO47)
LED_A: LED1.2 (A), R14.2
PGOOD: R3.1, U2.4 (PG)
SD_CD: J3.9 (CD), R8.1, U1.8 (IO15)
SD_CS: J3.2 (DAT3_CS), TP6.1, U1.4 (IO4)
SD_MISO: J3.7 (DAT0_DO), U1.5 (IO5)
SD_MOSI: J3.3 (CMD_DI), U1.6 (IO6)
SD_SCK: J3.5 (CLK), U1.7 (IO7)
SS: C2.1, U2.9 (SS_TR)
STATUS_LED: LED1.1 (K), U1.12 (IO8)
STRAP45: R6.1, U1.26 (IO45)
STRAP46: R7.1, U1.16 (IO46)
SW: L1.1, U2.1 (SW), U2.2 (SW), U2.3 (SW)
U0RXD: J4.6 (RX), U1.36 (RXD0)
U0TXD: J4.5 (TX), U1.37 (TXD0)
USB_D+: J4.3 (USB_D+), U1.14 (USB_D+)
USB_D-: J4.4 (USB_D-), U1.13 (USB_D-)

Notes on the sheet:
DISPLAY — 8-BIT 8080, NO TOUCH
STORAGE / CONTROLS / AMBIENT LIGHT
ESP32-S3 CONTROLLER / DEBUG
POWER INPUT / PROTECTION / 3V3

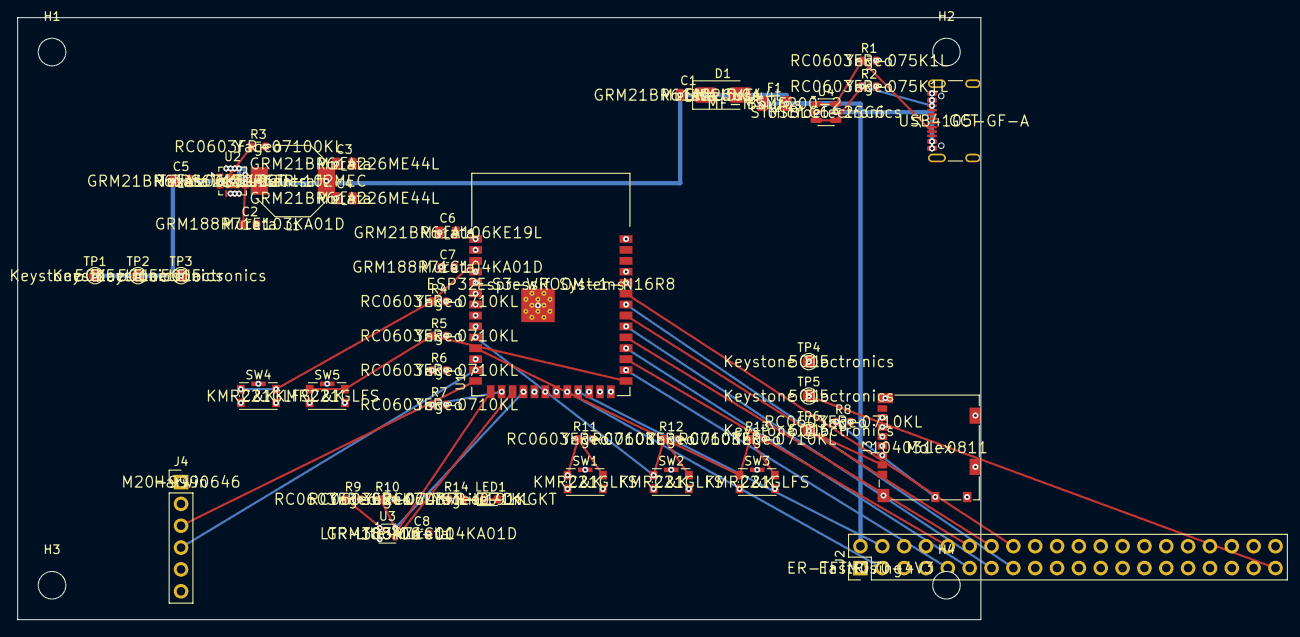
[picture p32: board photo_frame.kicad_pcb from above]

Board: 4 copper layers, 112.0 x 70.0 mm, 49 parts (0 on the bottom side), 45 nets.

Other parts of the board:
H1, H2, H3, H4: M3 mounting hole; MountingHole_3.2mm_M3

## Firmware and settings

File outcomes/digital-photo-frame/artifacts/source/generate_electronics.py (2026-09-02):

#!/usr/bin/env python3
"""Generate the KiCad authority for the cleanroom photo-frame experiment.

The schematic is first emitted in KiCad's deterministic legacy text format and
then upgraded by kicad-cli.  The board is generated through KiCad's bundled
pcbnew Python API.  Both are driven by the same component/pad/net table below.
"""

from __future__ import annotations

import json
import math
import os
import shutil
import subprocess
import sys
import uuid
from dataclasses import dataclass, field
from pathlib import Path

import pcbnew


ROOT = Path(__file__).resolve().parents[1]
KICAD_DIR = ROOT / "models" / "kicad" / "source"
LEGACY_SCH = KICAD_DIR / "photo_frame_legacy.sch"
SCH = KICAD_DIR / "photo_frame.kicad_sch"
PCB = KICAD_DIR / "photo_frame.kicad_pcb"
PRO = KICAD_DIR / "photo_frame.kicad_pro"
LIB = KICAD_DIR / "PhotoFrame.lib"
DCM = KICAD_DIR / "PhotoFrame.dcm"
KICAD_CLI = Path("/opt/homebrew/Caskroom/kicad/10.0.6/KiCad/KiCad.app/Contents/MacOS/kicad-cli")
SHARED = Path("/opt/homebrew/Caskroom/kicad/10.0.6/KiCad/KiCad.app/Contents/SharedSupport")


@dataclass(frozen=True)
class Pin:
    number: str
    name: str
    etype: str = "P"
    side: str = "L"


@dataclass
class SymbolDef:
    name: str
    pins: list[Pin]


@dataclass
class Component:
    ref: str
    symbol: str
    value: str
    footprint: str
    datasheet: str
    manufacturer: str
    mpn: str
    description: str
    nets: dict[str, str | None]
    sch_pos: tuple[int, int]
    pcb_pos: tuple[float, float]
    pcb_angle: float = 0.0
    board_only: bool = False


def pins_lr(entries: list[tuple[str, str, str]]) -> list[Pin]:
    midpoint = math.ceil(len(entries) / 2)
    return [
        Pin(number, name, etype, "L" if index < midpoint else "R")
        for index, (number, name, etype) in enumerate(entries)
    ]


SYMBOLS: dict[str, SymbolDef] = {}


def add_symbol(name: str, entries: list[tuple[str, str, str]]) -> None:
    SYMBOLS[name] = SymbolDef(name, pins_lr(entries))


add_symbol("R_EXACT", [("1", "1", "P"), ("2", "2", "P")])
add_symbol("C_EXACT", [("1", "1", "P"), ("2", "2", "P")])
add_symbol("L_EXACT", [("1", "1", "P"), ("2", "2", "P")])
add_symbol("FUSE_EXACT", [("1", "1", "P"), ("2", "2", "P")])
add_symbol("DIODE_EXACT", [("1", "K", "P"), ("2", "A", "P")])
add_symbol("LED_EXACT", [("1", "K", "P"), ("2", "A", "P")])
add_symbol("SW_KMR2", [("1", "A", "P"), ("2", "B", "P"), ("SH", "SHIELD", "P")])
add_symbol("TESTPOINT", [("1", "TP", "P")])
add_symbol("PWR_FLAG", [("1", "PWR", "w")])

add_symbol(
    "ESP32_S3_WROOM_1_N16R8",
    [
        ("1", "GND", "W"), ("2", "3V3", "W"), ("3", "EN", "I"),
        ("4", "IO4", "B"), ("5", "IO5", "B"), ("6", "IO6", "B"),
        ("7", "IO7", "B"), ("8", "IO15", "B"), ("9", "IO16", "B"),
        ("10", "IO17", "B"), ("11", "IO18", "B"), ("12", "IO8", "B"),
        ("13", "USB_D-", "B"), ("14", "USB_D+", "B"), ("15", "IO3", "B"),
        ("16", "IO46", "B"), ("17", "IO9", "B"), ("18", "IO10", "B"),
        ("19", "IO11", "B"), ("20", "IO12", "B"), ("21", "IO13", "B"),
        ("22", "IO14", "B"), ("23", "IO21", "B"), ("24", "IO47", "B"),
        ("25", "IO48", "B"), ("26", "IO45", "B"), ("27", "IO0", "B"),
        ("28", "IO35", "B"), ("29", "IO36", "B"), ("30", "IO37", "B"),
        ("31", "IO38", "B"), ("32", "IO39", "B"), ("33", "IO40", "B"),
        ("34", "IO41", "B"), ("35", "IO42", "B"), ("36", "RXD0", "B"),
        ("37", "TXD0", "B"), ("38", "IO2", "B"), ("39", "IO1", "B"),
        ("40", "GND", "W"), ("41", "EP_GND", "W"),
    ],
)

add_symbol(
    "ER_TFTM070_4V3",
    [
        ("1", "GND", "W"), ("2", "VDD5V", "W"), ("3", "~CS", "I"),
        ("4", "D_C", "I"), ("5", "~RD", "I"), ("6", "~WR", "I"),
        ("7", "RESET", "I"), ("8", "TE", "O"),
        *[(str(9 + i), f"DB{i}", "B") for i in range(24)],
        ("33", "TP_SCL", "B"), ("34", "TP_CS", "B"), ("35", "TP_SDA", "B"),
        ("36", "TP_DOUT", "B"), ("37", "TP_INT", "B"), ("38", "TP_GND", "W"),
        ("39", "BL_ON_PWM", "I"), ("40", "NC", "N"),
    ],
)

add_symbol(
    "TPS62132RGTR",
    [
        ("1", "SW", "O"), ("2", "SW", "P"), ("3", "SW", "P"),
        ("4", "PG", "C"), ("5", "FB_NC", "N"), ("6", "GND", "W"),
        ("7", "FSW", "I"), ("8", "DEF", "I"), ("9", "SS_TR", "I"),
        ("10", "VIN", "W"), ("11", "VIN", "P"), ("12", "VIN", "P"),
        ("13", "EN", "I"), ("14", "VOS", "I"), ("15", "GND", "W"),
        ("16", "GND", "W"), ("17", "EP_GND", "W"),
    ],
)

add_symbol(
    "USB4105_GF_A",
    [
        ("A1", "GND", "W"), ("A4", "VBUS", "P"), ("A5", "CC1", "B"),
        ("A6", "D+", "B"), ("A7", "D-", "B"), ("A8", "SBU1", "B"),
        ("A9", "VBUS", "P"), ("A12", "GND", "W"),
        ("B1", "GND", "W"), ("B4", "VBUS", "P"), ("B5", "CC2", "B"),
        ("B6", "D+", "B"), ("B7", "D-", "B"), ("B8", "SBU2", "B"),
        ("B9", "VBUS", "P"), ("B12", "GND", "W"), ("SH", "SHIELD", "P"),
    ],
)

add_symbol(
    "USBLC6_2SC6",
    [("1", "IO1A", "P"), ("2", "GND", "W"), ("3", "IO2A", "P"),
     ("4", "IO2B", "P"), ("5", "VBUS", "W"), ("6", "IO1B", "P")],
)

add_symbol(
    "MICROSD_104031_0811",
    [("1", "DAT2", "B"), ("2", "DAT3_CS", "B"), ("3", "CMD_DI", "I"),
     ("4", "VDD", "W"), ("5", "CLK", "I"), ("6", "VSS", "W"),
     ("7", "DAT0_DO", "O"), ("8", "DAT1", "B"), ("9", "CD", "P"),
     ("10", "CD_COMMON", "P"), ("SH", "SHIELD", "P")],
)

add_symbol(
    "LTR_303ALS_01",
    [("1", "VDD", "W"), ("2", "NC", "N"), ("3", "GND", "W"),
     ("4", "SCL", "I"), ("5", "INT", "C"), ("6", "SDA", "B")],
)

add_symbol(
    "HEADER_1X6",
    [(str(i), name, "P") for i, name in enumerate(["3V3", "GND", "USB_D+", "USB_D-", "TX", "RX"], 1)],
)


COMPONENTS: list[Component] = []


def comp(**kwargs) -> None:
    COMPONENTS.append(Component(**kwargs))


URL_DISPLAY = "https://www.buydisplay.com/download/manual/ER-TFTM070-4V3_Datasheet.pdf"
URL_ESP = "https://www.espressif.com/sites/default/files/documentation/esp32-s3-wroom-1_wroom-1u_datasheet_en.pdf"
URL_TPS = "https://www.ti.com/lit/ds/symlink/tps62132.pdf"


# Power input and protection.
comp(ref="J1", symbol="USB4105_GF_A", value="USB4105-GF-A", footprint="Connector_USB:USB_C_Receptacle_GCT_USB4105-xx-A_16P_TopMnt_Horizontal", datasheet="https://gct.co/files/drawings/usb4105.pdf", manufacturer="GCT", mpn="USB4105-GF-A", description="USB-C 16-position receptacle; power-only sink", nets={"A1":"GND","A4":"+5V_RAW","A5":"CC1","A6":None,"A7":None,"A8":None,"A9":"+5V_RAW","A12":"GND","B1":"GND","B4":"+5V_RAW","B5":"CC2","B6":None,"B7":None,"B8":None,"B9":"+5V_RAW","B12":"GND","SH":"GND"}, sch_pos=(2800,2600), pcb_pos=(130,32), pcb_angle=90)
comp(ref="R1", symbol="R_EXACT", value="5.1k 1%", footprint="Resistor_SMD:R_0603_1608Metric", datasheet="https://www.yageo.com/upload/media/product/productsearch/datasheet/rchip/PYu-RC_Group_51_RoHS_L_13.pdf", manufacturer="Yageo", mpn="RC0603FR-075K1L", description="USB-C CC1 Rd sink resistor", nets={"1":"CC1","2":"GND"}, sch_pos=(4300,2200), pcb_pos=(119,25))
comp(ref="R2", symbol="R_EXACT", value="5.1k 1%", footprint="Resistor_SMD:R_0603_1608Metric", datasheet="https://www.yageo.com/upload/media/product/productsearch/datasheet/rchip/PYu-RC_Group_51_RoHS_L_13.pdf", manufacturer="Yageo", mpn="RC0603FR-075K1L", description="USB-C CC2 Rd sink resistor", nets={"1":"CC2","2":"GND"}, sch_pos=(4300,3000), pcb_pos=(119,28))
comp(ref="U4", symbol="USBLC6_2SC6", value="USBLC6-2SC6", footprint="Package_TO_SOT_SMD:SOT-23-6", datasheet="https://www.st.com/resource/en/datasheet/usblc6-2.pdf", manufacturer="STMicroelectronics", mpn="USBLC6-2SC6", description="ESD protection for both USB-C CC pins and VBUS reference", nets={"1":"CC1","2":"GND","3":"CC2","4":"CC2","5":"+5V_RAW","6":"CC1"}, sch_pos=(5300,2600), pcb_pos=(114,31))
comp(ref="F1", symbol="FUSE_EXACT", value="2.0A resettable", footprint="Fuse:Fuse_1206_3216Metric", datasheet="https://www.bourns.com/docs/product-datasheets/mf-msmf.pdf", manufacturer="Bourns", mpn="MF-MSMF200-2", description="Resettable input current limiter", nets={"1":"+5V_RAW","2":"+5V"}, sch_pos=(6500,2600), pcb_pos=(108,30))
comp(ref="D1", symbol="DIODE_EXACT", value="SMAJ5.0A", footprint="Diode_SMD:D_SMA", datasheet="https://www.littelfuse.com/assetdocs/littelfuse-tvs-diode-smaj-datasheet", manufacturer="Littelfuse", mpn="SMAJ5.0A", description="Unidirectional 5 V rail TVS", nets={"1":"+5V","2":"GND"}, sch_pos=(7600,2600), pcb_pos=(102,29))
comp(ref="C1", symbol="C_EXACT", value="22uF 10V X5R", footprint="Capacitor_SMD:C_0805_2012Metric", datasheet="https://search.murata.co.jp/Ceramy/image/img/PDF/ENG/GRM21BR61A226ME44-01.pdf", manufacturer="Murata", mpn="GRM21BR61A226ME44L", description="Protected 5 V bulk capacitor; 10 V rating", nets={"1":"+5V","2":"GND"}, sch_pos=(8500,2600), pcb_pos=(98,29))

# 3.3 V converter and local energy storage.
comp(ref="U2", symbol="TPS62132RGTR", value="TPS62132RGTR 3.3V", footprint="Package_DFN_QFN:VQFN-16-1EP_3x3mm_P0.5mm_EP1.68x1.68mm_ThermalVias", datasheet=URL_TPS, manufacturer="Texas Instruments", mpn="TPS62132RGTR", description="3 A fixed 3.3 V synchronous buck", nets={"1":"SW","2":"SW","3":"SW","4":"PGOOD","5":None,"6":"GND","7":"GND","8":"GND","9":"SS","10":"+5V","11":"+5V","12":"+5V","13":"+5V","14":"+3V3","15":"GND","16":"GND","17":"GND"}, sch_pos=(5200,4800), pcb_pos=(45,39))
comp(ref="L1", symbol="L_EXACT", value="1.0uH 20%", footprint="Inductor_SMD:L_Bourns-SRU8028_8.0x8.0mm", datasheet="https://www.coilcraft.com/getmedia/5e5308cc-2480-4f52-be4a-cbbfc5c2eb1f/xal4020.pdf", manufacturer="Coilcraft", mpn="XAL4020-102MEC", description="Shielded buck inductor; Isat 7.6 A", nets={"1":"SW","2":"+3V3"}, sch_pos=(6800,4400), pcb_pos=(52,39))
comp(ref="C2", symbol="C_EXACT", value="10nF 25V X7R", footprint="Capacitor_SMD:C_0603_1608Metric", datasheet="https://search.murata.co.jp/Ceramy/image/img/PDF/ENG/GRM188R71E103KA01-01.pdf", manufacturer="Murata", mpn="GRM188R71E103KA01D", description="Buck soft-start capacitor", nets={"1":"SS","2":"GND"}, sch_pos=(6500,5200), pcb_pos=(47,44))
for ref, pos in [("C3",(58,37)),("C4",(58,41))]:
    comp(ref=ref, symbol="C_EXACT", value="22uF 10V X5R", footprint="Capacitor_SMD:C_0805_2012Metric", datasheet="https://search.murata.co.jp/Ceramy/image/img/PDF/ENG/GRM21BR61A226ME44-01.pdf", manufacturer="Murata", mpn="GRM21BR61A226ME44L", description="3.3 V output capacitor; 10 V rating", nets={"1":"+3V3","2":"GND"}, sch_pos=(7600,4600 if ref=="C3" else 5200), pcb_pos=pos)
comp(ref="C5", symbol="C_EXACT", value="10uF 10V X5R", footprint="Capacitor_SMD:C_0805_2012Metric", datasheet="https://search.murata.co.jp/Ceramy/image/img/PDF/ENG/GRM21BR61A106KE19-01.pdf", manufacturer="Murata", mpn="GRM21BR61A106KE19L", description="Buck input capacitor", nets={"1":"+5V","2":"GND"}, sch_pos=(7600,5800), pcb_pos=(39,39))
comp(ref="R3", symbol="R_EXACT", value="100k 1%", footprint="Resistor_SMD:R_0603_1608Metric", datasheet="https://www.yageo.com/upload/media/product/productsearch/datasheet/rchip/PYu-RC_Group_51_RoHS_L_13.pdf", manufacturer="Yageo", mpn="RC0603FR-07100KL", description="Power-good pull-up", nets={"1":"PGOOD","2":"+3V3"}, sch_pos=(6500,5800), pcb_pos=(48,35))

# Processor and required boot, reset, decoupling, debug.
u1_nets = {"1":"GND","2":"+3V3","3":"EN","4":"SD_CS","5":"SD_MISO","6":"SD_MOSI","7":"SD_SCK","8":"SD_CD","9":"BTN_PREV","10":"BTN_NEXT","11":"BTN_MENU","12":"STATUS_LED","13":"USB_D-","14":"USB_D+","15":"ALS_INT","16":"STRAP46","17":"I2C_SCL","18":"I2C_SDA","19":"LCD_BL","20":"LCD_TE","21":"LCD_RST","22":"LCD_CS","23":"LCD_DC","24":"LCD_WR","25":"LCD_RD","26":"STRAP45","27":"BOOT","28":"LCD_D0","29":"LCD_D1","30":"LCD_D2","31":"LCD_D3","32":"LCD_D4","33":"LCD_D5","34":"LCD_D6","35":"LCD_D7","36":"U0RXD","37":"U0TXD","38":None,"39":None,"40":"GND","41":"GND"}
comp(ref="U1", symbol="ESP32_S3_WROOM_1_N16R8", value="ESP32-S3-WROOM-1-N16R8", footprint="RF_Module:ESP32-S3-WROOM-1", datasheet=URL_ESP, manufacturer="Espressif Systems", mpn="ESP32-S3-WROOM-1-N16R8", description="Wi-Fi MCU module; 16 MB flash and 8 MB octal PSRAM", nets=u1_nets, sch_pos=(11200,6500), pcb_pos=(82,51))
for ref, value, mpn, pos, sy in [("C6","10uF 10V X5R","GRM21BR61A106KE19L",(70,45),5200),("C7","100nF 16V X7R","GRM188R71C104KA01D",(70,49),5700)]:
    comp(ref=ref, symbol="C_EXACT", value=value, footprint="Capacitor_SMD:C_0603_1608Metric" if ref=="C7" else "Capacitor_SMD:C_0805_2012Metric", datasheet="https://search.murata.co.jp/Ceramy/owa/CATALOG.showcatalog", manufacturer="Murata", mpn=mpn, description="ESP32 local decoupling", nets={"1":"+3V3","2":"GND"}, sch_pos=(9200,sy), pcb_pos=pos)
for ref, net, other, desc, spos, ppos in [
    ("R4","EN","+3V3","ESP32 enable pull-up",(9200,6400),(69,53)),
    ("R5","BOOT","+3V3","ESP32 GPIO0 boot pull-up",(9200,7000),(69,57)),
    ("R6","STRAP45","GND","GPIO45 strap pull-down for 3.3 V VDD_SPI",(9200,7600),(69,61)),
    ("R7","STRAP46","GND","GPIO46 strap pull-down for normal boot",(9200,8200),(69,65)),
]:
    comp(ref=ref, symbol="R_EXACT", value="10k 1%", footprint="Resistor_SMD:R_0603_1608Metric", datasheet="https://www.yageo.com/upload/media/product/productsearch/datasheet/rchip/PYu-RC_Group_51_RoHS_L_13.pdf", manufacturer="Yageo", mpn="RC0603FR-0710KL", description=desc, nets={"1":net,"2":other}, sch_pos=spos, pcb_pos=ppos)
for ref, net, desc, spos, ppos in [
    ("SW4","EN","Reset access",(9200,8800),(48,64)),
    ("SW5","BOOT","Bootloader access",(9200,9400),(56,64)),
]:
    comp(ref=ref, symbol="SW_KMR2", value="KMR221GLFS", footprint="Button_Switch_SMD:SW_Push_1P1T-SH_NO_CK_KMR2xxG", datasheet="https://www.ckswitches.com/media/1479/kmr2.pdf", manufacturer="C&K", mpn="KMR221GLFS", description=desc, nets={"1":net,"2":"GND","SH":"GND"}, sch_pos=spos, pcb_pos=ppos)
comp(ref="J4", symbol="HEADER_1X6", value="DEBUG 1x6", footprint="Connector_PinHeader_2.54mm:PinHeader_1x06_P2.54mm_Vertical", datasheet="https://cdn.harwin.com/pdfs/M20-999.pdf", manufacturer="Harwin", mpn="M20-9990646", description="Internal programming and debug header", nets={"1":"+3V3","2":"GND","3":"USB_D+","4":"USB_D-","5":"U0TXD","6":"U0RXD"}, sch_pos=(9200,10400), pcb_pos=(39,74))

# Display interface.  DB8..DB23 and touch pins are intentionally NC for the selected no-touch 8-bit build.
j2_nets: dict[str, str | None] = {"1":"GND","2":"+5V","3":"LCD_CS","4":"LCD_DC","5":"LCD_RD","6":"LCD_WR","7":"LCD_RST","8":"LCD_TE"}
j2_nets.update({str(9+i): f"LCD_D{i}" if i < 8 else None for i in range(24)})
j2_nets.update({"33":None,"34":None,"35":None,"36":None,"37":None,"38":None,"39":"LCD_BL","40":None})
comp(ref="J2", symbol="ER_TFTM070_4V3", value="ER-TFTM070-4V3 8-bit 8080 5V no-touch", footprint="Connector_PinHeader_2.54mm:PinHeader_2x20_P2.54mm_Vertical", datasheet=URL_DISPLAY, manufacturer="EastRising", mpn="ER-TFTM070-4V3", description="7-inch 800x480 SSD1963 display module; pin-header configuration", nets=j2_nets, sch_pos=(17400,6500), pcb_pos=(118,84), pcb_angle=90)

# Storage, buttons, sensor, and status indication.
comp(ref="J3", symbol="MICROSD_104031_0811", value="104031-0811", footprint="Connector_Card:microSD_HC_Molex_104031-0811", datasheet="https://www.molex.com/content/dam/molex/molex-dot-com/products/automated/en-us/productspecificationpdf/104/104031/PS-104031-001-001.pdf", manufacturer="Molex", mpn="104031-0811", description="Push-pull microSD socket with detect switch", nets={"1":None,"2":"SD_CS","3":"SD_MOSI","4":"+3V3","5":"SD_SCK","6":"GND","7":"SD_MISO","8":None,"9":"SD_CD","10":"GND","SH":"GND"}, sch_pos=(13200,11200), pcb_pos=(126,70), pcb_angle=90)
comp(ref="R8", symbol="R_EXACT", value="10k 1%", footprint="Resistor_SMD:R_0603_1608Metric", datasheet="https://www.yageo.com/upload/media/product/productsearch/datasheet/rchip/PYu-RC_Group_51_RoHS_L_13.pdf", manufacturer="Yageo", mpn="RC0603FR-0710KL", description="microSD card-detect pull-up", nets={"1":"SD_CD","2":"+3V3"}, sch_pos=(14500,11200), pcb_pos=(116,67))
comp(ref="U3", symbol="LTR_303ALS_01", value="LTR-303ALS-01", footprint="OptoDevice:Lite-On_LTR-303ALS-01", datasheet="https://optoelectronics.liteon.com/upload/download/DS86-2013-0004/LTR-303ALS-01_DS_V1.1.PDF", manufacturer="Lite-On", mpn="LTR-303ALS-01", description="I2C ambient-light sensor", nets={"1":"+3V3","2":None,"3":"GND","4":"I2C_SCL","5":"ALS_INT","6":"I2C_SDA"}, sch_pos=(7800,11200), pcb_pos=(63,80))
for ref, net, spos, ppos in [("R9","I2C_SCL",(6400,10800),(59,76)),("R10","I2C_SDA",(6400,11400),(63,76))]:
    comp(ref=ref, symbol="R_EXACT", value="4.7k 1%", footprint="Resistor_SMD:R_0603_1608Metric", datasheet="https://www.yageo.com/upload/media/product/productsearch/datasheet/rchip/PYu-RC_Group_51_RoHS_L_13.pdf", manufacturer="Yageo", mpn="RC0603FR-074K7L", description="I2C pull-up", nets={"1":net,"2":"+3V3"}, sch_pos=spos, pcb_pos=ppos)
comp(ref="C8", symbol="C_EXACT", value="100nF 16V X7R", footprint="Capacitor_SMD:C_0603_1608Metric", datasheet="https://search.murata.co.jp/Ceramy/image/img/PDF/ENG/GRM188R71C104KA01-01.pdf", manufacturer="Murata", mpn="GRM188R71C104KA01D", description="Ambient sensor decoupling", nets={"1":"+3V3","2":"GND"}, sch_pos=(9000,11200), pcb_pos=(67,80))
for idx, (ref, net, y, x) in enumerate([("SW1","BTN_PREV",12400,86),("SW2","BTN_NEXT",13200,96),("SW3","BTN_MENU",14000,106)]):
    comp(ref=ref, symbol="SW_KMR2", value="KMR221GLFS", footprint="Button_Switch_SMD:SW_Push_1P1T-SH_NO_CK_KMR2xxG", datasheet="https://www.ckswitches.com/media/1479/kmr2.pdf", manufacturer="C&K", mpn="KMR221GLFS", description=["Previous button","Next button","Menu/wake button"][idx], nets={"1":net,"2":"GND","SH":"GND"}, sch_pos=(10200,y), pcb_pos=(x,74))
    comp(ref=f"R{11+idx}", symbol="R_EXACT", value="10k 1%", footprint="Resistor_SMD:R_0603_1608Metric", datasheet="https://www.yageo.com/upload/media/product/productsearch/datasheet/rchip/PYu-RC_Group_51_RoHS_L_13.pdf", manufacturer="Yageo", mpn="RC0603FR-0710KL", description="User-button pull-up", nets={"1":net,"2":"+3V3"}, sch_pos=(11600,y), pcb_pos=(x,69))
comp(ref="R14", symbol="R_EXACT", value="1.0k 1%", footprint="Resistor_SMD:R_0603_1608Metric", datasheet="https://www.yageo.com/upload/media/product/productsearch/datasheet/rchip/PYu-RC_Group_51_RoHS_L_13.pdf", manufacturer="Yageo", mpn="RC0603FR-071KL", description="Status LED current limit", nets={"1":"+3V3","2":"LED_A"}, sch_pos=(15000,12400), pcb_pos=(71,76))
comp(ref="LED1", symbol="LED_EXACT", value="LTST-C191KGKT green", footprint="LED_SMD:LED_0603_1608Metric", datasheet="https://optoelectronics.liteon.com/upload/download/DS22-2000-228/LTST-C191KGKT.pdf", manufacturer="Lite-On", mpn="LTST-C191KGKT", description="Rear-facing green status LED", nets={"1":"STATUS_LED","2":"LED_A"}, sch_pos=(16400,12400), pcb_pos=(75,76))

# Labeled measurement points.  They are intentionally included in schematic parity and BOM-excluded later if desired.
for idx, (ref, net, pos) in enumerate([("TP1","+5V",(29,50)),("TP2","+3V3",(34,50)),("TP3","GND",(39,50)),("TP4","LCD_WR",(112,60)),("TP5","LCD_BL",(112,64)),("TP6","SD_CS",(112,68))]):
    comp(ref=ref, symbol="TESTPOINT", value=net, footprint="TestPoint:TestPoint_Pad_D1.5mm", datasheet="https://www.keyelco.com/product.cfm/product_id/13981", manufacturer="Keystone Electronics", mpn="5015", description=f"Labeled test point for {net}", nets={"1":net}, sch_pos=(18500,10500 + idx*450), pcb_pos=pos)

# ERC power drivers.
for idx, (ref, net, pos) in enumerate([("PF1","+5V",(2600,5200)),("PF2","+3V3",(2600,5900)),("PF3","GND",(2600,6600)),("PF4","+5V_RAW",(2600,7300))]):
    comp(ref=ref, symbol="PWR_FLAG", value="PWR_FLAG", footprint="", datasheet="", manufacturer="", mpn="", description="ERC power-driver marker", nets={"1":net}, sch_pos=pos, pcb_pos=(0,0), board_only=False)


def library_symbol_text(symbol: SymbolDef) -> str:
    count_left = sum(pin.side == "L" for pin in symbol.pins)
    count_right = len(symbol.pins) - count_left
    height = max(count_left, count_right, 2) * 100 + 300
    top = height // 2
    bottom = -top
    lines = [
        f"# {symbol.name}", f"#", f"DEF {symbol.name} U 0 40 Y Y 1 F N",
        'F0 "U" 0 150 50 H V C CNN', f'F1 "{symbol.name}" 0 -150 50 H V C CNN',
        "DRAW", f"S -700 {bottom} 700 {top} 0 1 12 f",
    ]
    left_index = 0
    right_index = 0
    for pin in symbol.pins:
        if pin.side == "L":
            y = top - 200 - left_index * 100
            left_index += 1
            x, orient = -900, "R"
        else:
            y = top - 200 - right_index * 100
            right_index += 1
            x, orient = 900, "L"
        lines.append(f"X {pin.name} {pin.number} {x} {y} 200 {orient} 45 45 1 1 {pin.etype}")
    lines += ["ENDDRAW", "ENDDEF"]
    return "\n".join(lines)


def write_library() -> None:
    content = ["EESchema-LIBRARY Version 2.4", "#encoding utf-8"]
    for symbol in SYMBOLS.values():
        content.append(library_symbol_text(symbol))
    content += ["#End Library", ""]
    LIB.write_text("\n".join(content), encoding="utf-8")
    DCM.write_text("EESchema-DOCLIB  Version 2.0\n#End Doc Library\n", encoding="utf-8")
    (KICAD_DIR / "sym-lib-table").write_text(
        '(sym_lib_table\n  (lib (name "PhotoFrame")(type "Legacy")(uri "${KIPRJMOD}/PhotoFrame.lib")(options "")(descr "Cleanroom project symbols"))\n)\n',
        encoding="utf-8",
    )


def symbol_pin_positions(symbol: SymbolDef) -> dict[str, tuple[int, int]]:
    count_left = sum(pin.side == "L" for pin in symbol.pins)
    count_right = len(symbol.pins) - count_left
    height = max(count_left, count_right, 2) * 100 + 300
    top = height // 2
    left_index = right_index = 0
    result = {}
    for pin in symbol.pins:
        if pin.side == "L":
            result[pin.number] = (-900, top - 200 - left_index * 100)
            left_index += 1
        else:
            result[pin.number] = (900, top - 200 - right_index * 100)
            right_index += 1
    return result
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

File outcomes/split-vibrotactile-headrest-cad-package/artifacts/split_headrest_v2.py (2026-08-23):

"""Full-size split PETG V2 vibrotactile headrest for 256 mm print beds.

The 300 mm body is divided at X=+90 mm, leaving the central head-contact and
actuator region in one 240 mm primary shell.  A 60 mm end cap is aligned by two
pins and retained by two independent one-piece bridges:

* an internal PETG actuator spine at the cavity ceiling; and
* the removable underside service panel.

Powered electronics remain external.

Coordinate system:
    origin: product footprint centre
    X: 300 mm product length
    Y: 140 mm front-to-rear depth
    +Z: upward from the closed underside
"""

from build123d import Align, Axis, Box, Color, Compound, Cylinder, Pos
from cadpy.assembly import AssemblyHelper, label_shape


BODY_LENGTH = 300.0
BODY_DEPTH = 140.0
BODY_BASE_Z = 0.0
BODY_TOP_Z = 80.0
BODY_HEIGHT = BODY_TOP_Z - BODY_BASE_Z
BODY_CORNER_RADIUS = 14.0
HEAD_CONTACT_EDGE_RADIUS = 10.0

SPLIT_X = 90.0
SEAM_GAP = 0.30
PRIMARY_LENGTH = SPLIT_X - SEAM_GAP / 2.0 + BODY_LENGTH / 2.0
END_CAP_LENGTH = BODY_LENGTH / 2.0 - SPLIT_X - SEAM_GAP / 2.0

CONCAVITY_RADIUS = 1000.0
CONCAVITY_CENTER_Z = 1068.0

CAVITY_LENGTH = 214.0
CAVITY_DEPTH = 112.0
CAVITY_BASE_Z = 4.0
CAVITY_TOP_Z = 53.0
CAVITY_HEIGHT = CAVITY_TOP_Z - CAVITY_BASE_Z
CAVITY_CORNER_RADIUS = 10.0

PANEL_LENGTH = 240.0
PANEL_DEPTH = 132.0
PANEL_THICKNESS = 4.0
PANEL_CORNER_RADIUS = 12.0
PANEL_RECESS_LENGTH = 242.0
PANEL_RECESS_DEPTH = 134.0
PANEL_RECESS_CLEARANCE = 1.0
PANEL_FASTENER_D = 3.4
PANEL_HEAD_RECESS_D = 6.2
PANEL_HEAD_RECESS_DEPTH = 1.5
PANEL_INSERT_ENVELOPE_D = 5.5
PANEL_INSERT_ENVELOPE_DEPTH = 8.0
PANEL_FASTENER_X = 105.0
PANEL_FASTENER_Y = 61.0
GASKET_GROOVE_OUTER_LENGTH = 226.0
GASKET_GROOVE_OUTER_DEPTH = 118.0
GASKET_GROOVE_INNER_LENGTH = 220.0
GASKET_GROOVE_INNER_DEPTH = 112.0
GASKET_GROOVE_DEPTH = 0.6
GASKET_GROOVE_OUTER_RADIUS = 13.0
GASKET_GROOVE_INNER_RADIUS = 10.0

CABLE_PORT_D = 8.0
CABLE_PORT_Z = 30.0
CABLE_GROMMET_RECESS_D = 14.0
CABLE_GROMMET_LIP = 2.5
CABLE_WALL_THICKNESS = (BODY_DEPTH - CAVITY_DEPTH) / 2.0
CABLE_GROMMET_RECESS_DEPTH = CABLE_WALL_THICKNESS - CABLE_GROMMET_LIP

# This one-piece PETG spine bridges the shell seam and carries the actuator.
SPINE_LENGTH = 210.0
SPINE_DEPTH = 100.0
SPINE_THICKNESS = 10.0
SPINE_CORNER_RADIUS = 8.0
SPINE_CLEARANCE_D = 4.5
SPINE_FASTENER_X_POSITIONS = (-75.0, 60.0, 100.0)
SPINE_FASTENER_Y = 42.0
SPINE_INSERT_ENVELOPE_D = 6.0
SPINE_INSERT_ENVELOPE_DEPTH = 8.0
STRAIN_RELIEF_HOLE_D = 3.4
STRAIN_RELIEF_X = 55.0
STRAIN_RELIEF_Y_POSITIONS = (8.0, 34.0)

ALIGNMENT_PIN_D = 6.0
ALIGNMENT_HOLE_D = 6.4
ALIGNMENT_PIN_LENGTH = 19.2
ALIGNMENT_HOLE_LENGTH = 20.0
ALIGNMENT_PIN_Y_POSITIONS = (-36.0, 36.0)
ALIGNMENT_PIN_Z = 60.0

TT25_LOWER_BODY_D = 67.0
TT25_BARE_TAB_SWEEP_D = 104.5
TT25_TOTAL_HEIGHT = 24.6
TT25_MOUNT_INTERFACE_THICKNESS = 4.0

SENSOR_SIZE = 30.0
SENSOR_THICKNESS = 2.0
SENSOR_OFFSET_X = 55.0


SHELL_COLOR = Color(0.72, 0.43, 0.20)
CAP_COLOR = Color(0.78, 0.48, 0.24)
PANEL_COLOR = Color(0.40, 0.18, 0.06)
SPINE_COLOR = Color(0.88, 0.40, 0.10)
PIN_COLOR = Color(0.95, 0.65, 0.20)
ACTUATOR_COLOR = Color(0.10, 0.12, 0.14)
SENSOR_COLOR = Color(0.12, 0.42, 0.24)


def _centered_box(length: float, depth: float, height: float, base_z: float):
    return Box(
        length,
        depth,
        height,
        align=(Align.CENTER, Align.CENTER, Align.MIN),
    ).moved(Pos(0, 0, base_z))


def _vertical_hole(diameter: float, height: float, x: float, y: float, base_z: float):
    return Cylinder(
        diameter / 2.0,
        height,
        align=(Align.CENTER, Align.CENTER, Align.MIN),
    ).moved(Pos(x, y, base_z))


def _horizontal_x_hole(diameter: float, length: float, x: float, y: float, z: float):
    return Cylinder(
        diameter / 2.0,
        length,
        rotation=(0, 90, 0),
        align=(Align.CENTER, Align.CENTER, Align.CENTER),
    ).moved(Pos(x, y, z))


def _rounded_centered_box(
    length: float,
    depth: float,
    height: float,
    base_z: float,
    corner_radius: float,
):
    solid = _centered_box(length, depth, height, base_z)
    return solid.fillet(corner_radius, solid.edges().filter_by(Axis.Z))


def make_full_split_ready_shell():
    outer = _centered_box(BODY_LENGTH, BODY_DEPTH, BODY_HEIGHT, BODY_BASE_Z)
    outer = outer.fillet(BODY_CORNER_RADIUS, outer.edges().filter_by(Axis.Z))

    concavity_tool = Cylinder(
        CONCAVITY_RADIUS,
        BODY_DEPTH + 30.0,
        rotation=(90, 0, 0),
        align=(Align.CENTER, Align.CENTER, Align.CENTER),
    ).moved(Pos(0, 0, CONCAVITY_CENTER_Z))
    shell = outer - concavity_tool

    contact_surface_lower_z = CONCAVITY_CENTER_Z - CONCAVITY_RADIUS
    contact_perimeter_edges = [
        edge
        for edge in shell.edges()
        if edge.bounding_box().min.Z >= contact_surface_lower_z - 1e-6
    ]
    if len(contact_perimeter_edges) != 8:
        raise ValueError(
            "Expected eight head-contact perimeter edges before softening, "
            f"found {len(contact_perimeter_edges)}"
        )
    shell = shell.fillet(HEAD_CONTACT_EDGE_RADIUS, contact_perimeter_edges)

    panel_recess = _rounded_centered_box(
        PANEL_RECESS_LENGTH,
        PANEL_RECESS_DEPTH,
        PANEL_THICKNESS + PANEL_RECESS_CLEARANCE,
        -PANEL_RECESS_CLEARANCE,
        PANEL_CORNER_RADIUS,
    )
    shell = shell - panel_recess

    cavity = _rounded_centered_box(
        CAVITY_LENGTH,
        CAVITY_DEPTH,
        CAVITY_HEIGHT,
        CAVITY_BASE_Z,
        CAVITY_CORNER_RADIUS,
    )
    shell = shell - cavity

    cable_port = Cylinder(
        CABLE_PORT_D / 2.0,
        24.0,
        rotation=(90, 0, 0),
        align=(Align.CENTER, Align.CENTER, Align.CENTER),
    ).moved(Pos(0, BODY_DEPTH / 2.0 - 6.0, CABLE_PORT_Z))
    shell = shell - cable_port

    cable_grommet_recess = Cylinder(
        CABLE_GROMMET_RECESS_D / 2.0,
        CABLE_GROMMET_RECESS_DEPTH,
        rotation=(90, 0, 0),
        align=(Align.CENTER, Align.CENTER, Align.CENTER),
    ).moved(
        Pos(
            0,
            BODY_DEPTH / 2.0 - CABLE_GROMMET_RECESS_DEPTH / 2.0,
            CABLE_PORT_Z,
        )
    )
    shell = shell - cable_grommet_recess

    for x in (-PANEL_FASTENER_X, PANEL_FASTENER_X):
        for y in (-PANEL_FASTENER_Y, PANEL_FASTENER_Y):
            shell = shell - _vertical_hole(
                PANEL_INSERT_ENVELOPE_D,
                PANEL_INSERT_ENVELOPE_DEPTH,
                x,
                y,
                PANEL_THICKNESS,
            )

    for x in SPINE_FASTENER_X_POSITIONS:
        for y in (-SPINE_FASTENER_Y, SPINE_FASTENER_Y):
            shell = shell - _vertical_hole(
                SPINE_INSERT_ENVELOPE_D,
                SPINE_INSERT_ENVELOPE_DEPTH,
                x,
                y,
                CAVITY_TOP_Z - 0.5,
            )
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

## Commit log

2026-08-23 Publish Fray Labs Outcomes
    [cat-shelter.step, robot-snake.step, split_headrest_v2.step]
2026-09-02 Publish fold-flat travel hanger outcome
    [hanger-deployed-check.step, hanger-deployed.step, hanger-folded-check.step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]
2026-09-02 Fix hanger viewing and add fold motion
    [hanger-deployed-check.step, hanger-deployed.step, hanger-folded-check.step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]
2026-09-02 Publish genuine Burr cleanroom outcomes
    [digital_photo_frame.step, hanger-deployed-check.step, hanger-deployed.step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]
2026-09-02 outcomes: publish complete Burr cleanroom projects
    [00_display_envelope_reference.step, center_yoke.3mf, center_yoke.step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]
2026-09-02 outcomes: slim public cleanroom bundles
    [00_display_envelope_reference.step, center_yoke.3mf, center_yoke.step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]
2026-09-27 Add five practical workday prompt outcomes with verified examples
    [diagnosis.csv, exceptions.csv, queue-breakdown.csv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]
2026-09-27 Withdraw rejected workday collection; retain prior demo catalog
    [diagnosis.csv, exceptions.csv, queue-breakdown.csv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]
2026-10-05 Publish the first recorded recipes: falling-sand sandbox and flow-field poster maker
    Both were captured with possible capture from fresh Claude Code sessions,
    reviewed before export, and are labelled as made by an AI agent.
2026-10-05 Publish the recorded slithering robot snake prototype
    Captured from a scripted Codex session that used the $possible skill,
    reviewed before export, and labelled as made by an AI agent. Media was
    regenerated from the session's own files.
2026-10-18 Publish two cleanroom agent results: bakery central kitchen deck and two-angle phone stand
    Both were made by Possible's hireable agents (Deck Maker and Prototype
    Engineer) in fresh, empty workspaces from a single brief, recorded with
    possible capture and reviewed before export.
2026-11-12 Launch film poster: the 'Get the agents that make these' frame with real results
2026-11-12 Launch film poster: new file name so the directory picks up the 15 s frame
